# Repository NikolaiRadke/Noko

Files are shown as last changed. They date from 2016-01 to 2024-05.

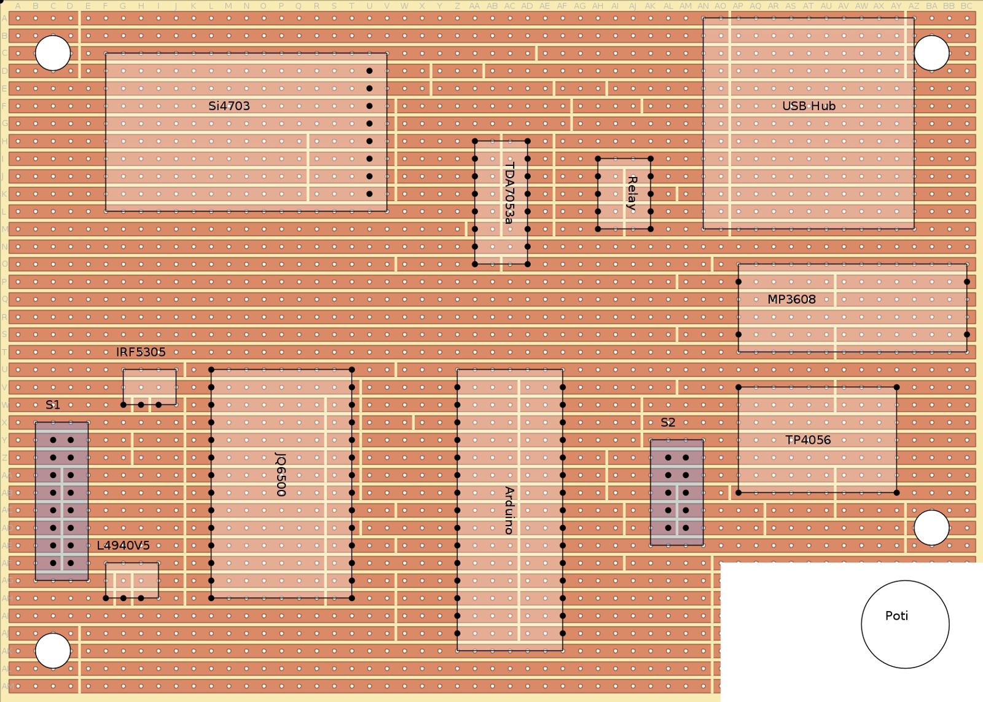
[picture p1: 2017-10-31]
schematics/Noko_layout_down.png

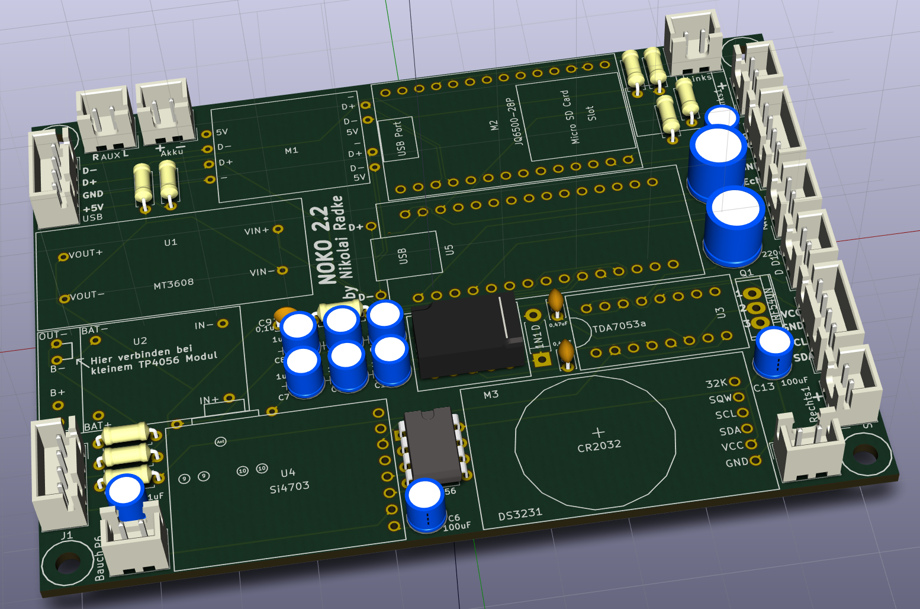
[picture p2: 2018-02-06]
Schematics/kicad/screenshots/NOKO PCB 3D 2018-02-01 20-50-33.png

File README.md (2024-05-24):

Noko
  
The DIY-**Noko Monster**, lovely and naughty, ready to build on your own. And everyone is invited to **contribute**. Noko is for everyone. What's new? See the [newsblog](https://github.com/NikolaiRadke/Noko/tree/master/NEWS.md).  
  
Noko Orange  

Noko is a multifunctional monster with an ATmega328  microcontroller on an **Arduino Nano**, display, clock, radio, mp3 player, four buttons as user interface, battery, voice set and  tons of gimmicks, packed in a cuddly monster suit - sturdy,
lovely and sometimes a bit mean and annoying. Just the way you want him to be. He, she or it - this is your decision     and only depends on the voice set. In this repository Noko is a lad, a real bloke! A buddy for life and a companion by day and night. All he needs is a little power every now and then.  

**Noko** stands for **No**ra and ni**ko**'s monster.

### Notes for non-German Noko makers
There are a German and an English version. Right now, the building wiki, the voice set, the manual and the optional EEPROM text files are in German. I'll try to translate the wiki and the manual one day. Until then, feel free to ask me for translation, if you need help. **Contribute!** I need an English voice set and English text files. In addition, any other language is welcome, Noko is to be cosmopolitan!

### Prerequisites
Noko needs Arduino IDE 1.6.6 - [1.8.2](https://www.arduino.cc/en/Main/Software) Copy the folder `Noko/V10/src/[language]/Noko/` into your sketch folder. When using 1.6.10 or newer with AVR core 1.6.12 or newer, everything will compile out-of-the-box. With 1.6.9 or lower, *Noko.ino* won't compile, the sketch size is too large. 

**Option 1:** Install newest  [IDE](https://www.arduino.cc/en/Main/Software) and relax.  
**Option 2:** If you are using IDE 1.6.9 or lower, you need to install [Optiboot](https://github.com/Optiboot/optiboot) onto your Nano.  
**Option 3:** Take one of the precompiled hex-files and follow the instructions in [how to compile](https://github.com/NikolaiRadke/Noko/tree/master/howto_compile).  

**In any case, Optiboot is strongly recommended.**

### Content

```
Noko/
├── howto_compile/
|   Manual how compile the sketches in your Arduino IDE and precompiled sketches.  
|   └── precompiled/
|       Precompiled hex-files and windows tools.
|       ├── Deutsch/
|       |   German Versions.
|       ├── English/
|       |   English Versions.
|       ├── Flashtool/
|       |   Linux firmware flasher.
|       └── avrdude_win/
|           Avrdude files for windows.
|
├── manual/
|   Noko manual in PDF format and a template for a packaging design.
|   └── scribus/
|       Source documents for Scribus with all illustrations and fonts.
|
├── mp3/
|   Female and male voice sets for Noko in German. English needed? Contribute!
|   ├── female/  
|   |   Female voice set for Nokos.
|   |   └── VoiceSet_226/
|   |       New voice files.
|   └── male/
|       Male voice sets
|       ├── alternative/
|       |   Some less rude voice files.
|       ├── VoiceSet_111/
|       |   Voice set for older Nokos.
|       └── VoiceSet_226/
|           Enhanced voice set.
| 
├── schematics/
|   The Schematics for the Noko parts, the Noko sewing pattern and shopping lists.
|   └── geda/
|       Source documents for gEDA.
|
├── src/
|   Arduino sketches.
|   ├── deutsch/
|   |   German version
|   |   └── Noko/
|   |       Main sourcecode with all the required libraries.
|   ├── english/
|   |   English version. 
|   |   └── Noko/
|   |       Same files but translated. 
|   └── tools/
|       Tools for using components and diagnostic.    
|       ├── I2C-Scanner/
|       |   Sketch to scan adresses of all connected I2C-devices.
|       ├── Noko_Diagnostics/
|       |   Tool to test Noko functions via serial monitor.
|       ├── Noko_Disk1/
|       |   Sketch to write the Disk1 textfile into 24LC256-EEPROMs.
|       ├── Noko_EEPROM_Disk0/
|       |   Sketch to write Noko presets into the Arduino EEPROM and the Disk0 textfile into the
|       |   AH24C32 EEPROM.
|       └── Noko_Time/
|           Simple tool to set the current time without touching the EEPROM
└── write_EEPROM/
    Tools to write data through serial connection to the Arduino and the EEPROMs. 
```
### Let's get started!

Interested in Noko? Great! Let's start here: [German wiki](https://github.com/NikolaiRadke/Noko/wiki).  
English wiki will follow. One day...

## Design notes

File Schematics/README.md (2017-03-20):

# Schematics

### Technical schematics
* **NOKO.png**:
NOKO's main schematic.
* **NOKO_Amp.png**:
Amplifier with TDA7053a and ADC-schematic for the buttons.
* **NOKO_USB.png**:
Power source and USB hub.

These schematics have been written with [gEDA](http://www.geda-project.org/). You can find the source files in folder [geda/](https://github.com/NikolaiRadke/NOKO/tree/master/schematics/geda).

### Other manuals

* **NOKO_Pattern.pdf**:
NOKOs sewing pattern. 
* **NOKO_Einkaufsliste.pdf**:
Shopping list in German  

### Construction plans, used in the wiki
* **NOKO_inside.png**:  
Foto of NOKOs inside life  
* **NOKO_layout_down.png**:  
Mainboard layout downside  
* **NOKO_layout_s1.png**:  
S1 plug description German  
* **NOKO_layout_s2.png**:  
S2 plug description German  
* **NOKO_layout_small.png**:  
Upper board layout downside  
* **NOKO_layout_small_2.png**:  
Upper board connections upside  
* **NOKO_layout_up.png**:  
Mainboard layout upside  
* **NOKO_layout_up_amp.png**:  
Mainboad layout for amplifier and connections upside
* **NOKO_layout_up_data.png**:  
Mainboard layout for data connections upside  
* **NOKO_layout_up_power.png**:  
Mainboard layout for power connections upside  
* **NOKO_raw.png**:  
Mainboard downside

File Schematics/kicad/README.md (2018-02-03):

Achtung! Bitte die Gerber Dateien noch nicht benutzen! Es müssen noch Fehler beseitigt werden.

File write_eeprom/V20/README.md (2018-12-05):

# Setting up a serial connection and writing to EEPROMs

Open the NOKO writer sketch **write_eeprom.ino** in the Arduino IDE and start it. You can see the progress on your console.  

## Linux

1. Open a terminal  

2. To communicate through the connection, the user must be a member of the group **Dialout**. This can easily be done once-for-all with this command:  
``` sudo usermod -aG dialout $(whoami) ```  

3. Set parameter of serial communication with  
``` stty -F /dev/ttyUSB0 cs8 9600 ignbrk -brkint -imaxbel -opost -onlcr -isig -icanon -iexten -echo -echoe -echok -echoctl -echoke noflsh -ixon -crtscts ```  
if another USB port is used by NOKO, modify /dev/USB0 to /dev/USB1 or whatever the IDE tells you.

4. Change the directoy to ` NOKO/write_eeprom/ `

5. Write the text file to EEPROM with the command  
``` ./write_eeprom > /dev/ttyUSB0 ```  
or, if you want to see the progress in your console,    
``` ./write_eeprom | tee /dev/ttyUSB0 ```  
The program sends the content of the text file **EEPROM** via Arduino to the EEPROM. You can watch your Arduino's RX and TX LEDs blinking furiously. This may take a while, the file needs about 18 minutes to be written... *yawn*

### NOTE 
*write_eeprom* was compiled with *x86_64*. For other platforms, see *write_eeprom.c* comments to compile it for yourself.

## Windows

1. Open a command line. Click on *Start* and type ``` cmd ```.  

2. Chance the directoy to ` NOKO/write_eeprom/  `  

3. Write the text file to EEPROM with the command  ``` write_eeprom > COM1 ```  
If another USB port is used by NOKO, modify COM1 to COM2 or whatever the IDE tells you. The program sends the content of the text file **EEPROM** via Arduino to the EEPROM. You can watch your Arduino's RX and TX LEDs blinking furiously. This may take a while, the file needs about 18 minutes to be written... *yawn*

## Windows 8  

Users report troubles writing an EEPROM with the provided tools. Please try another platform.  

## Windows 10

Like written above, but first Windows 10 needs another **baud rate**. You need admin rights.  
 
or **Line 17** in **write_eeprom.ino**.  
  
2. *Right click Start* -> *Device Manager* -> *Ports* -> *USB Serial Port (COMX)* -> *Right click Port Settings*  

3. Set *Bits per second* to **115200**.

4. Take steps above.  

### NOTE 
*write_eeprom.exe* was compiled with *x86_64*. For other platforms, see *write_eeprom.c* comments to compile it for yourself.

## The textfile EEPROM

### EEPROM format
* **0000-3999** are for the swearword generator:  
*German version*  
**0000-0999** 10 chars for an adjective. If it's male, the funtions adds an "r" and a space.  
**1000-1999** 10 chars for the first part of the noun.  
**2000-2999** 10 chars for male noun.  
**3000-3999** 10 chars for female noun.  
*English version*  
**0000-0999** 10 chars for an adjective. The function adds a space.  
**1000-1999** 10 chars for the first part of the noun. The function adds a space.  
**2000-3999** 10 chars for noun.  

* **4000-9999** are for the phrases:  
Every phrase starts with *Wusstest Du, dass...* in German and *Did you know that...* in English. So each item has **3x20** characters.

* **10000-17999** are for the quotations:    
Just **4x20** chars. NOKO pretends to be sophisticated.

* **18000-20079** are for the poems:   
Again **4x20**. Try to be lyrical.

* **20080-XXX** 20 chars for author's name and 20 chars for the story title

if you want to write less items, just change the starting adresses in *NOKO.ino*.

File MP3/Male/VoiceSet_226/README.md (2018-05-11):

# Male voice set for NOKO - German | enhanced 226 files Version

Copy these mp3s into the folder **001** on your microSD card. Strictly observe the sequence!
021.mp3 must be copied as the 21st file. See the [Wiki](https://github.com/NikolaiRadke/NOKO/wiki/SDKarte) for more detailed instructions.

| Number  | Assignment |
| ---|---:|
| 001-010 | Free NOKIA alarm tunes |
| 011-050 | Response to belly button |
| 051-100 | Response to nose button  |
| 101-150 | Response to ultrasonic |
| 151-225 | Time based events |
| 226 | Birthday song |

011-225 have been spoken by my fellow actor [Carsten Caniglia](https://filmmakers.de/carsten-caniglia). Why? 
He has done a great job - moreover I don't want to listen to my own voice every day, especially when development takes more than a year! (Ian said I sound really weird in real life. Thanks, mate.)

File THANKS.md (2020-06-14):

# Thanks

These people helped me bringing life to Noko:  
  
- **Hans Radke** - (my dad) hardware construction and a lot of soldering.
- **Nora Linder** - creating and sewing the monster suit and spellchecking.
- **Carsten Caniglia** - the voice of Noko. Look at his [Homepage](https://filmmakers.de/carsten-caniglia).  
- **Norma Anthes** - the new female voice of Noko. Look at her [Homepage](http://norma-anthes.de/Norma_Anthes/).  
- **Ian Berell** - some english translations and spelling. Look at his [bike locks](https://twitter.com/sphykeian) and his new Hexlox [Kickstarter campain](https://www.kickstarter.com/projects/hexlox/hexlox-anti-theft-for-saddles-wheels-and-more-made). 
- **Helga Hansen** - The great article in the german Make-Magazin.

Active supporters:  
  
- **Hein-Peter Mahlzahn** - lots of corrections in the Wiki and GitHub.
- **David Feindel** - corrections.  
- **Reinhard Hund** - corrections.  
- **Ronny Roscher** - he found an annoying hardware bug.  
- **Thomas "Crayfish68"** - schemtics corrections, the (wheeee!) pcb and a LOT of beta testing.   
- **Yannik "ylth94"** - for the first pcb and supporting Thomas with the pcb design.  
- **Tim "Wetimer"** - for supporting Thomas with the pcb design.  
- **"jlegen"** - for supporting Thomas with the pcb design.  
- **Thomas "teuler"** - for supporting Thomas with the pcb design.  
- **Ralf Warmuth** - corrections.  
- **BigAngelina** - ideas,testing and the (horray!) 3D casing.  
- **Issue-Community** - ideas, inspirations and (alas!) bugs.  

Used ressources:  

- **Arduino board and IDE** - [www.arduino.cc](http://www.arduino.cc)  
- **Display library** - [Marco Schwartz](https://github.com/marcoschwartz/LiquidCrystal_I2C)  
- **Old display library** - [Francisco Malpartida](https://bitbucket.org/fmalpartida/new-liquidcrystal/wiki/Home)  
- **RTC library** - [Wagner Sartori Junior](https://github.com/trunet/DS3231RTC)   
- **JQ6500 library** - [James Sleeman](https://github.com/sleemanj/JQ6500_Serial)  
- **Si4703 library** - [Gary Bell](https://github.com/whiteneon/Si4703_FMRadio)     
- **TimerFreeTone library** - [Tim Eckel](https://bitbucket.org/teckel12/arduino-timer-free-tone/wiki/Home)  
- **Time library** - [Michael Margolis](https://github.com/michaelmargolis/arduino_time/tree/master/Time)  
- **Clock font** - [Ishan Karve](http://karve.in/?p=59)  
- **Suit inspiration - Ninni** - [RevoluzZa Blog](http://blog.revoluzzza.com/2009/02/25/tutorial-hopw-to-sew-a-revoluzzzionary-monster-wie-man-ein-revoluzzzionares-monster-naht/)

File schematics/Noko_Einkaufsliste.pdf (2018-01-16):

+/,#5(3-+34'
Technik
1 Arduino Nano
1 Serielles (I2C) LC-Display, 20x04 Zeilen
1 Echtzeituhr DS3231 mit EEPROM AT24C32 1 MP3-Modul JQ6500-28p
1 Ultraschallsensor HC-SR04
1 Akku 1800mAh, 81x50x4mm
1 Lademodul TP4056
1 Step Up-Modul, MP3608, 2A
1 USB-Hub, klein, mit kabelgebundenen Ports 1 microSD-Karte, min. 2GB
2 Lautsprecher 8Ohm, rechteckig, 20x40mm
1 (Optional) Radio Si4703
1 (Optional) EEPROM 24LC256
2 Lochstreifenplatinen 160x100mm, 2,54mm Rastermaß
1 Hartpapierplatine ohne Kupferauflage, ca. 100x50mm
2 Micro-USB-Kabel mit Winkel rechts
1 USB Buchse, isoliert mit Anschlusskabel (eventuell vom USB-Slotblech) 1 3,5mm AUX-Klinkenbuchse, isoliert mit Anschlusskabel
4 Taster, flach und breit
1 LED - oder 3 Taster und eine Taster-LED für die Nase (empfohlen)
1 R 330 (LED-Vorwiderstand)
1 L4940V5 Spannungsregulator
1 TDA7053a DIP (kein Sockel!)
1 MOSFET IRF5305
1 Printrelais ST3 001 H5W
1 Poti 470k logarithmisch mit Schalter 1 Potiknopf
2 Elko 220µ
5 Elko 100µ
7 Elko 1µ
3 C0,47µ
2 C 0,1µ
1 R 100k
2 R 10k
1 R 4,7k
1 R 2,7k
3 R 2,2k
2 R 1k
1 Flachbandkabel,16-polig, ca. 0,5m 1 Flachbandkabel, 10-polig, ca. 0,5m 2 Stiftbuchsen mit Stecker, 16-polig 1 Stiftbuchse mit Stecker, 10-polig 1 Kabel mit Abschirmung, ca. 0,5m

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

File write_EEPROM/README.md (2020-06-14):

# Setting up a serial connection and writing to EEPROMs

Open the NOKO writer sketch **NOKO_EEPROM_Disk0.ino** or **NOKO_Disk1.ino** in the Arduino IDE and start it. 
Wait for *10 seconds*. When running *NOKO_Disk1.ino* you can go on immediately.

## Linux

1. Open a terminal  

2. To communicate through the connection, the user must be a member of the group **Dialout**. This can easily be done once-for-all with this command:  
``` sudo usermod -aG dialout $(whoami) ```  

3. Set parameter of serial communication with  
``` stty -F /dev/ttyUSB0 cs8 9600 ignbrk -brkint -imaxbel -opost -onlcr -isig -icanon -iexten -echo -echoe -echok -echoctl -echoke noflsh -ixon -crtscts ```  
if another USB port is used by NOKO, modify /dev/USB0 to /dev/USB1 or whatever the IDE tells you.

4. Change the directoy to ` NOKO/write_eeprom/ `

5. Write the text file to EEPROM with the command  
``` ./write_Disk0 > /dev/ttyUSB0 ```  
or   
``` ./write_Disk1 > /dev/ttyUSB0 ```  
or, if you want to see the progress in your console  
``` ./write_Disk1 | tee /dev/ttyUSB0 ```  
The program sends the content of the text file **Disk0** or **Disk1** via Arduino to the EEPROM. You can watch your Arduino's RX and TX LEDs blinking furiously. This may take a while, Disk1 needs about 20 minutes... *yawn*

### NOTE 
*write_DiskX* was compiled with *x86_64*. For other platforms, see *write_DiskX.c* comments to compile it for yourself.

## Windows

1. Open a command line. Click on *Start* and type ``` cmd ```.  

2. Chance the directoy to ` NOKO/write_eeprom/  `  

3. Write the text file to EEPROM with the command  
``` write_Disk0 > COM1 ```  
or  
``` write_Disk1 > COM1 ```  
If another USB port is used by NOKO, modify COM1 to COM2 or whatever the IDE tells you. The program sends the content of the text file **Disk0** or **Disk1** via Arduino to the EEPROM. You can watch your Arduino's RX and TX LEDs blinking furiously. This may take a while, Disk1 needs about 20 minutes... *yawn*

## Windows 8  

Users report troubles writing an EEPROM with the provided tools. Please try another platform.  

## Windows 10

Like written above, but first Windows 10 needs another **baud rate**. You need admin rights.  

1. Uncommend **Line 65** in sketch **NOKO_EEPROM_Disk0.ino**  
or **Line 17** in **NOKO_Disk1.ino**.  
  
2. *Right click Start* -> *Device Manager* -> *Ports* -> *USB Serial Port (COMX)* -> *Right click Port Settings*  

3. Set *Bits per second* to **115200**.

4. Take steps above.  

### NOTE 
*write_DiskX.exe* was compiled with *x86_64*. For other platforms, see *write_DiskX.c* comments to compile it for yourself.

## The textfiles Disk0 and Disk1

### Disk0 format
The Disk0 file contains the author and title of the stories. Every item has exactly **2x20** characters, including unused spaces. The next item follows immediately. Do not use the return key, the file is like a single long string. It has to be plain text, don't use a word processor, just a simple text editor. **Note:** NOKO counts from zero, maybe your editor starts with 1 - change nothing. Just type. The number of stories ist limited to **95**, the AT24C32 is limited to measy 4096 bytes. In this repository, there are 40 german stories. If you want more or less, modifiy in *NOKO_EEPROM_Disk0* **max_stories** in line  
``` #define max_stories 40 // Max 95 ```.  

### Disk1 format
Nearly the same as Disk0. No return key, just space bar. 
* **0000-3999** are for the swearword generator:  
*German version*  
**0000-0999** 10 chars for an adjective. If it's male, the funtions adds an "r" and a space.  
**1000-1999** 10 chars for the first part of the noun.  
**2000-2999** 10 chars for male noun.  
**3000-3999** 10 chars for female noun.  
*English version*  
**0000-0999** 10 chars for an adjective. The function adds a space.  
**1000-1999** 10 chars for the first part of the noun. The function adds a space.  
**2000-3999** 10 chars for noun.  

* **4000-9999** are for the phrases:  
Every phrase starts with *Wusstest Du, dass...* in German and *Did you know that...* in English. So each item has **3x20** characters.

* **10000-17999** are for the quotations:    
Just **4x20** chars. NOKO pretends to be sophisticated.

* **18000-20079** are for the poems:   
Again **4x20**. Try to be lyrical.

if you want to write less items, just change the starting adresses in *NOKO.ino*. Right now, the swearword generator needs 4000 chars, so the phrases always start at 4000. Change the adresses of the quotations and poems in line **95 and 96**.

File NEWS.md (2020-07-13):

# Newsblog
  
## 2020  

* **13.07.2020** Release **V1.0-130720**. The last for old Noko.   
* **12.07.2020** The rework is finishid.    
* **10.07.2020** Tested new IDE 1.8.13. Works good.  
* **10.06.2020** This repository gets a rework.  

## 2019
* **18.09.2019** New IDE 1.8.10 is out. Saves about 500 bytes - that's quite a lot!  
* **14.04.2019** Firmware **X.0-140418**. Fixed old and rare nightmode bug.  
* **13.04.2019** New IDE 1.8.9 is working.  

## 2018  
* **15.01.2018** New IDE 1.8.8 is working but still has AVR Core 1.6.23.  
* **20.11.2018** Small improvements for write_eeprom tool. Thanks to jlegen.  
* **19.11.2018** New IDE 1.8.7 tested. Works with new AVR Core 1.6.23. Finally.  
* **26.08.2018** See Noko and me at Wissensnacht Ruhr Gelsenkirchen: 28.08.2018.  
* **25.08.2018** New IDE 1.8.6 is out! Together with old AVR Core 1.6.18 code size is reduced by about 400 bytes!  
* **24.08.2018** See Noko and me at the Maker Faire Hannover: 15.09.2018-16.09.2018.  
* **14.05.2018** See Noko and me at the Maker Faire Berlin: 25.05.2018-28.05.2018, FEZ!  
* **11.05.2018** The female voice set ist finished.  
* **30.04.2018** Firmware **X.0-300418** Slightly optimized random generator.  
* **26.04.2018** Good news: The 3D printable casing is ready! Stay tuned for a new 2.0 repository!  
* **06.04.2018** Firmware **X.0-060418** When uploading files Noko should be quiet. The equalizer menu sets Noko in upload mode.  
* **04.04.2018** My hoster was offline for more than two weeks. I moved to a new one. The graphics in the GitHub are back now. What a waste of time...  
* **19.03.2018** German version V2.0 now has full Umlaute support.  
* **13.03.2018** The german manual got an update. All new functions are described now.  
* **07.03.2018** Firmware **X.0-070318** - Enhancement: You can select weekdays for the alarm. Very handy!  
* **02.03.2018** Firmware **X.0-020318** - Bugfix: No more compiling warnings. I sacrificed two precious bytes for your relief.  
* **01.03.2018** Testing firmware and tools to be released. The manual got an update too.  
* **28.02.2018** Firmware **1.0-280218**  
  PCB Nokos got the new update yesterday, today it's time for handmade Noko.  
  * Enhancement: Older Nokos got the equalizer, too.  
  * Removed: The obsolete quiet mode.  
* **27.02.2018** Firmware **2.0-270218**  
  Found some time today to do a little work at the player.
  * Enhancement: Added an equalizer menue fot the MP3 Module. See settings menue.  
  * Enhancement: Added two navigation buttons, +10 and -10 to the player for faster file browsing.  
  * Removed: The almost obsolete quiet mode is gone. The equalizier is now in his place. If you want Noko to be quiet, use the poti.  
  * Bugfix: Very small code cleanup.  
* **26.02.2018** Firmware **2.0-260218** - Bugfix: Fixed wrong story information adressing. Sorry, you need to flash again.   
* **24.02.2018** Firmware **2.0-240218** - There it is. Story informations are now stored in the not-optional-anmymore 24LC256.  
* **23.02.2018** Firmware **X.0-230218** - Enhancement: Noko shows the duration of a MP3 or a story by his own! Typing the times into noko_eeprom_disk0.ino is not needed anymore. In an upcoming firmware of V2.0 the story titles and authors will be written to 24LC256 to store more stories.  
* **09.02.2018** Firmware **X.0-080218** - Instead of NewTone library, which caused some troubles, Noko now uses TimerFreeTone library. Noko has his lost flash space back and tone generation works great.   
* **08.02.2018** Added Firmware **2.0-080218** - Bugfix: I encountered too much troubles with the tone generation on the PCB. Switched back from the beloved NewTone library to standard tone library. Now it is working fine, but takes 1500 Bytes more flash. Sight.  
* **07.02.2018** Added Firmware **1.0-070218** - Some tone code reworks.   
* **06.02.2018** Added Firmware **2.0-060218** and directory V20. These files are for PCB-Nokos. V1.0 in folder V10 will certainly get the same maintenance. No Noko will be left behind!  
* **04.02.2018** Finished testing the PCB. Nearly everything is working! There are some minor issues with the hub left.  
* **03.02.2018** The diagnostics tool got an update to V0.8. I needed more functions to test the new PCB.  
* **15.01.2018** Firmware **1.0-150118** - Enhancement: Story menu no shows length in hours and minutes.  
* **12.01.2018** Added a simple tool to set the current time without touching the EEPROM.  
* **08.01.2018** Finished the enhanced voice set. Firmware was updatet to **1.0-080118**. Have fun!  
  Warning: The new voice set ist preselected. If you want to use the old set, modify the comments in line **116** and **117**.  
* **01.01.2018** Happy new year! Stay tuned for the new Noko board and the enhanced voice set!  
  
## 2017
* **30.12.2017** Firmware **1.0-301217** - Enhancement/optional: Noko can read the busy signal reliable analog via A1  
* **18.12.2017** The gerber files are now online! Build your Noko in an easy way! Thanks to the community!  
* **30.11.2017** Firmware **1.0-301117** - Bugfix: The story addressing is now working correctly.  
NOTE: You need to reflash your AH24C32. Sorry. I'm a lousy coder.  
* **07.10.2017** Firmware **1.0-210917** - Enhancement: EEPROM lifecycle was improved mit EEPROM.update() instead of EEPROM.write(). I tried to fix more bugs but couldn't find any of them ;-). noko_eeprom_disk0 was also modified with this function. Noko_Diagnostics V0.5 now supports a library-free radio test.  
* **04.10.2017** IDE 1.8.5 is out. Still no compilier options. It seems to be AVR Core specific, maybe platform.txt is being ignored. Stay with 1.6.18 if you care about free flash.  
* **25.08.2017** IDE 1.8.4 with AVR Core 1.6.20 is out. Again, since AVR Core 1.6.19 compiler options aren't supported anymore. You can stay with 1.6.18. 
* **24.08.2017** Firmware **1.0-240817** - Bugfix: Now Noko supports 95 stories instead of 42.  
* **10.08.2017** Noko moved to Berlin!  
* **21.07.2017** ...and updated to V0.4. I have had some free time.  
* **20.07.2017** The Noko diagnostic tool was updated to V0.3.  
* **30.06.2017** **Release V1.0-300617**  
Second Noko release with new firmware 1.0-300617. I spend a lot of time looking for bugs. Since last firmware 1.0-240617, the belly button debounce was improved again, i also fred up some flash memory und did some small powersave improvents. This should be the last V1.0 release. Hopefully...  
* **24.06.2017** - Firmware **1.0-240617** - Belly button debounce improvement - it was about time! And some code optimizations. 100 Bytes freed! Wheee!  
* **19.06.2017** - Firmware **1.0-190617** - Bugfix: No time refresh when playing radio oder MP3s.  
* **09.06.2017** - Firmware **1.0-090617** - Another firmware update before the upcoming release with serval optimizations and a bugfix: The display won't turn off. 
* **07.06.2017** - New IDE 1.8.3 tested. Compiler options in platform.txt aren't working. Again. AVR Core 1.6.19 increases the sketch size by about 760 Bytes. IDE 1.8.3 with AVR Core 1.6.18 takes 17 Bytes more. Noko stays with AVR Core 1.6.18.  
* **04.06.2017** - Firmware **1.0-040617** - Code shrinking and - as the reason for a new firmware - a nasty bug got fixed in the distance light settings. A new release will follow soon.  
* **31.05.2017** - Added an early diagnostic tool for Noko to test functions through serial monitor.  
* **28.05.2017** - Added a TCL/TK Linux firmware flash tool. Should work with OSX, too. A Windows version will follow.  
* **21.05.2017** - Firmware **1.0-210517** - RDS rework. Works MUCH better now. Polling does not block navigation anymore. I am still working on some other improvements, expect a new release in June.    
* **17.05.2017** - **Release V1.0-170517**  
New optimized release. Install it! Noko will be glad. It is based on firmware 1.0-150517 with the following enhancements:  
  * Custom chars were taken from PROGMEM. That caused too much troubles.  
  * Cleaned up source code, completely in english, including constants, variables and function names.    
  * Autodetection for the display address. Very handy.  
  * Very small bugfixes.  
* **15.05.2017** - Small bugfixes. PROGMEM troubles custom character.  
* **14.05.2017** - The sourcecode is now in English. Renamed constans, functions and variables for better understanding.  
* **02.05.2017** - **Release V1.0-010517 - Buggy V1.0-190417 removed 29.05.2017**  
First release after initial 120516. Optimized and bugfixed 130417. Now there is enough flash free for future enhancements. Feel free to contact me for ideas, bugs and suggestions.  
* **27.04.2017** - Tested compiling options in platform.txt. They are working again with IDE 1.8.2. This saves about 800 bytes flash.  
* **19.04.2017** - Firmware **1.0-190417** - Fixed ADC bug after power safe mode.  
* **13.04.2017** - Well - it is **1.0-130417** now. Found a more flash-saving way.   
* **12.04.2017** - New firmware **1.0-120417** is out. After 11 month Noko gets some small enhancements:
  * Custom chars are now in PROGMEM  
  * Power saving when idle was improved.
  * The life cycle of the internal EEPROM was highly improved (several decades).
  * Small bugfixes and typos in the comments where removed.
* **24.03.2017** - New IDE 1.8.2 with AVR Core 1.6.18 works too.  
* **22.03.2017** - Noko was guest at CeBIT faire 2017: [https://www.youtube.com/watch?v=V2i4UrzMkM8#action=share]  
* **07.03.2017** - All four issues are now available as an ebook in all common stores and [heise shop](https://shop.heise.de/katalog/make-noko-das-mp3-monster?pk_campaign=dossnoko&pk_kwd=t1).  
* **22.02.2017** - The fourth und last issue of the Make Magazin arrived: [https://shop.heise.de/katalog/frankensteins-labor].  
* **13.01.2017** - New IDE 1.8.1 with AVR Core 1.6.17 works.  
* **12.01.2017** - Added Windows 10 support for burning the eeproms.  
* **05.01.2017** - **Hardware bug found**: The resistor at D2 moved to D3.  
  
## 2016
* **24.12.2016** - Merry Xmas. A good time to test new 1.8.0 IDE. Works.  
* **15.12.2016** - The third issue of the Make magazin is out: [https://shop.heise.de/katalog/make-06-2016].  
* **02.12.2016** - New IDE 1.6.13 is out. Works, but still no compiling options possible. (Deja Vu)  
* **12.11.2016** - The ST3 002 H5W relay is out of stock. Switched to FRT5 DC5V with a 1N4001 diode.  
* **02.11.2016** - Updated compiling options for newer (1.6.10+) and older (1.6.9-) IDEs.
* **13.10.2016** - The second issue of the Make magazin with the Noko article ist out. Get it now! Remember your friends... See [https://www.heise.de/make/inhalt/2016/5/68/] for more.  
* **28.09.2016** - New IDE 1.6.12 is out. Works, but still no compiling options possible. 
* **21.09.2016** - Added precompiled hex-files for those who have too much compiling troubles.  
* **28.08.2016** - New IDE 1.6.11 is out. Works, but new AVR Core 1.6.13 doesn't support compiling options anymore. Strange. Core 1.6.12 is still working great.    
* **12.08.2016** - Noko appears in the next four issues of the german Make magazin! See [https://www.heise.de/make/inhalt/2016/4/66/] for more.  
* **29.07.2016** - IDE 1.6.10 now has LTO, even Windows version! Optiboot and compiler options are not needed anymore, but still recommended.  
* **28.07.2016** - New IDE 1.6.10 is out. Works with Noko.ino. 
* **28.07.2016** - Reanimated the newsblog. For you and me and Noko.  
* **06.01.2016** - Joined GitHub

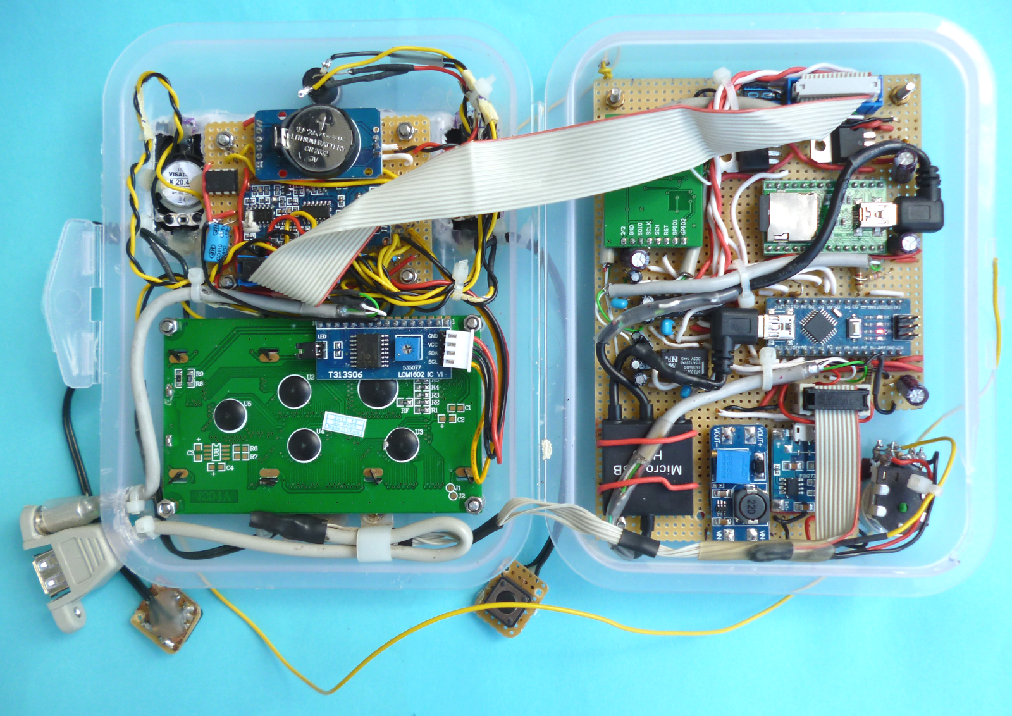
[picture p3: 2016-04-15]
schematics/Noko_inside.png

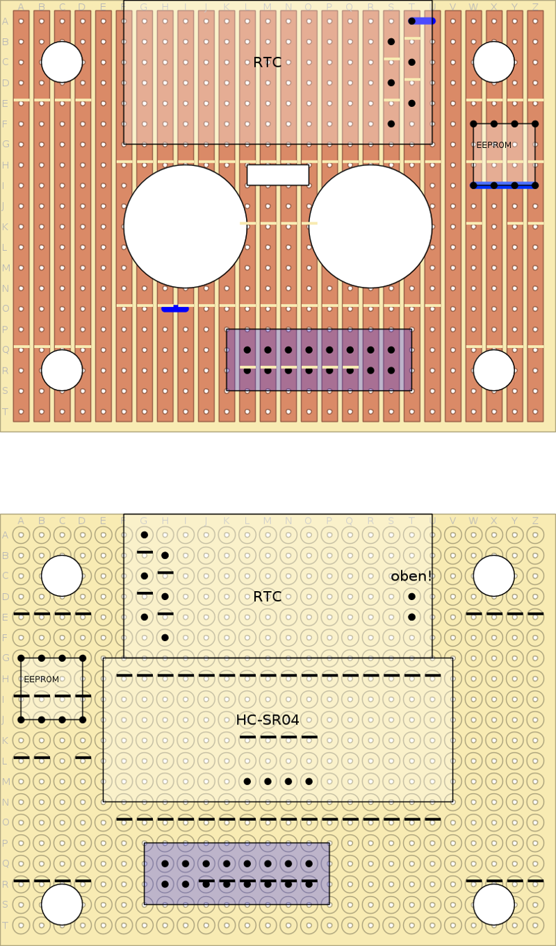
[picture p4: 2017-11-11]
schematics/Noko_layout_small.png

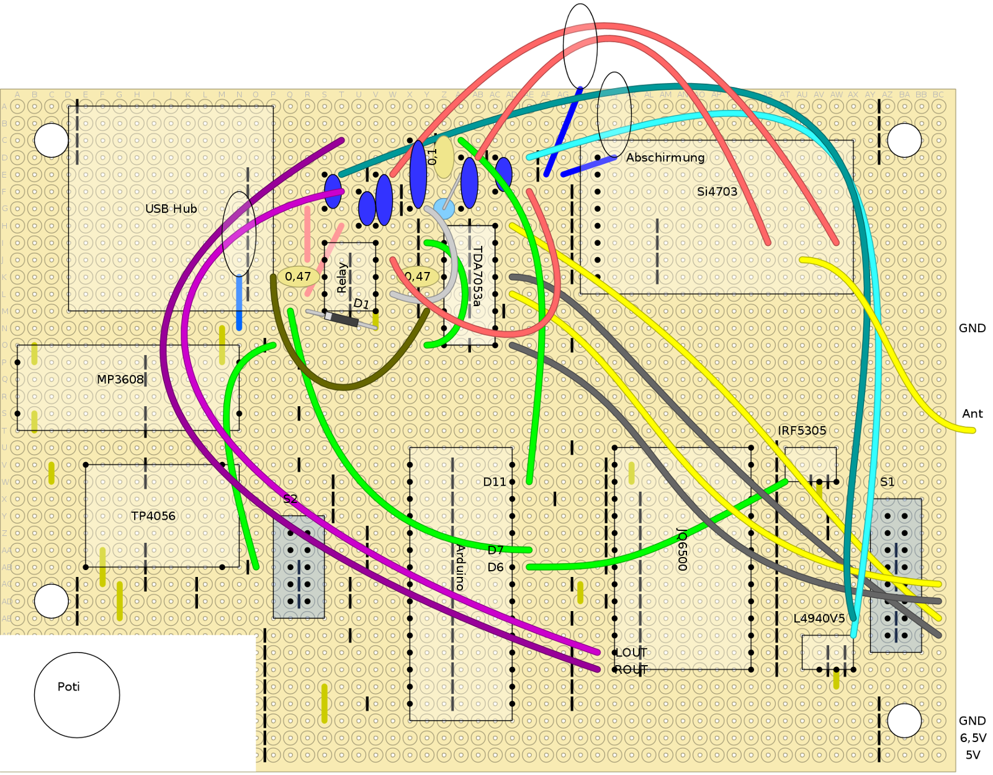
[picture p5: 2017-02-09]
schematics/Noko_layout_up_amp.png

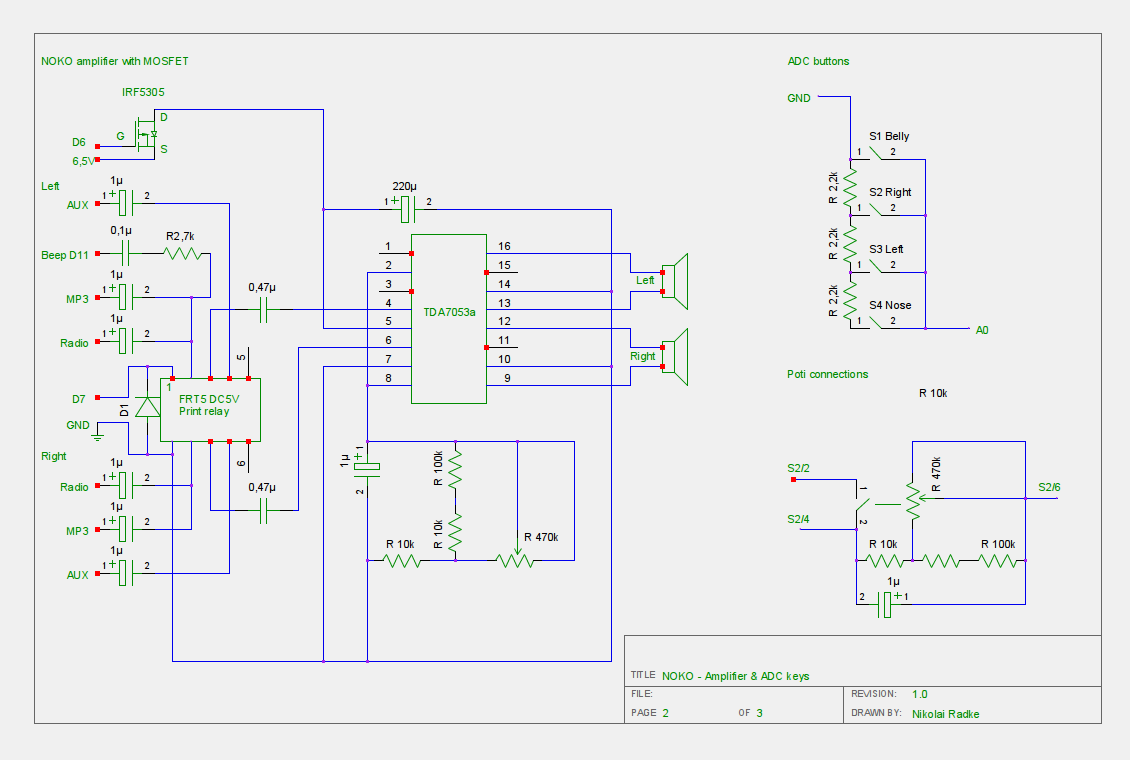
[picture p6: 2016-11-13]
schematics/Noko_Amp.png

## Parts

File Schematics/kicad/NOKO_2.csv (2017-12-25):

ID | Bezeichner | Gehäuse | Stückzahl | Bezeichnung | Anbieter und Ref.
1 | 1N1 | D_DO-41_SOD81_P7.62mm_Horizontal | 1 | D
2 | C1,C13,C14 | CP_Radial_D5.0mm_P2.50mm | 3 | 1uF
3 | C2,C3,C9,C15,C16 | CP_Radial_D5.0mm_P2.50mm | 5 | 100uF
4 | C4 | CP_Radial_Tantal_D4.5mm_P2.50mm | 1 | 0,1uF
5 | C5,C6 | CP_Radial_D8.0mm_P2.50mm | 2 | 220uF
6 | C7,C8 | CP_Radial_Tantal_D4.5mm_P2.50mm | 2 | 0,47uF
7 | C10,C11,C17,C18 | CP_Radial_D5.0mm_P2.00mm | 4 | 1uF
8 | C12 | CP_Radial_Tantal_D4.5mm_P2.50mm | 1 | 0,1u
9 | D1 | LED_D4.0mm | 1 | D
10 | P1 | JST_EH_B02B-EH-A_02x2.50mm_Straight | 1 | Battery
11 | P2 | JST_EH_B02B-EH-A_02x2.50mm_Straight | 1 | Switch_Poti
12 | P3 | JST_EH_B03B-EH-A_03x2.50mm_Straight | 1 | L4940V5
13 | P4 | JST_EH_B02B-EH-A_02x2.50mm_Straight | 1 | S4_Nose
14 | P5 | JST_EH_B02B-EH-A_02x2.50mm_Straight | 1 | S3_Left
15 | P6 | JST_EH_B02B-EH-A_02x2.50mm_Straight | 1 | S2_Right
16 | P7 | JST_EH_B02B-EH-A_02x2.50mm_Straight | 1 | S1_Belly
17 | P8 | JST_EH_B03B-EH-A_03x2.50mm_Straight | 1 | Poti
18 | P10 | JST_EH_B02B-EH-A_02x2.50mm_Straight | 1 | Speaker_Left
19 | P11 | JST_EH_B02B-EH-A_02x2.50mm_Straight | 1 | Speaker_Right
20 | P12 | JST_EH_B04B-EH-A_04x2.50mm_Straight | 1 | HC-SR04
21 | P13 | JST_EH_B04B-EH-A_04x2.50mm_Straight | 1 | Display
22 | P14 | JST_EH_B02B-EH-A_02x2.50mm_Straight | 1 | AUX
23 | Q1 | TO-220 | 1 | IRF540N
24 | R1,R2,R3 | R_Axial_DIN0207_L6.3mm_D2.5mm_P7.62mm_Horizontal | 3 | 2,2k
25 | R4,R6 | R_Axial_DIN0207_L6.3mm_D2.5mm_P7.62mm_Horizontal | 2 | 10k
26 | R5 | R_Axial_DIN0207_L6.3mm_D2.5mm_P7.62mm_Horizontal | 1 | 100k
27 | R7,R9 | R_Axial_DIN0207_L6.3mm_D2.5mm_P7.62mm_Horizontal | 2 | 1k
28 | R8 | R_Axial_DIN0207_L6.3mm_D2.5mm_P7.62mm_Horizontal | 1 | 300
29 | R10 | R_Axial_DIN0207_L6.3mm_D2.5mm_P7.62mm_Horizontal | 1 | 4,7k
30 | R11 | R_Axial_DIN0207_L6.3mm_D2.5mm_P7.62mm_Horizontal | 1 | 2,7k
31 | U3 | TDA7053a | 1 | TDA7053a
32 | U5 | Arduino_Nano | 1 | Arduino_Nano
33 | U7 | Printrelais_ST03 | 1 | FRT5_DC5V
34 | U8 | DIP-8_W7.62mm | 1 | 24LC256
35 | M3 | Micro-USB-Hub | 1 | Micro-USB-Hub
36 | P9 | JST_EH_B04B-EH-A_04x2.50mm_Straight | 1 | USB-Connector
37 | M2 | JQ6500-28P | 1 | JQ6500-28P
38 | U4 | Si4703 | 1 | Si4703
39 | M1 | DS3231 | 1 | DS3231
40 | U2 | TP4056 | 1 | TP4056
41 | U1 | MT3608 | 1 | MT3608

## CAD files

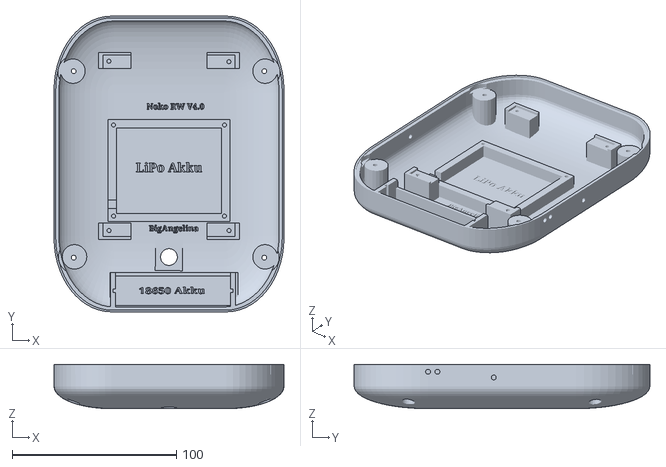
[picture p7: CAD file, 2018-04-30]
Schematics/gehaeuse/Rueckwand.stl
140.0 x 180.0 x 27.0

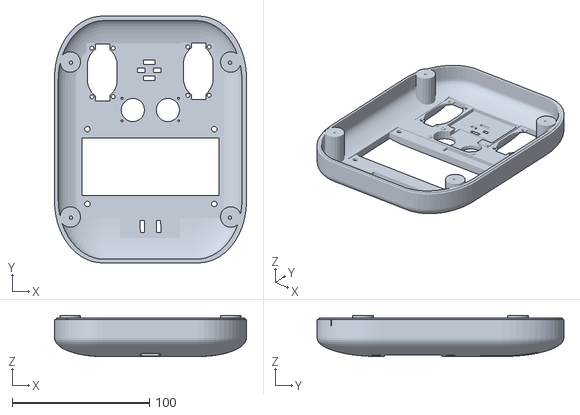
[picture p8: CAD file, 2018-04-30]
Schematics/gehaeuse/Gehaeuse_runde_LED_Schalter.stl
140.0 x 180.0 x 30.0

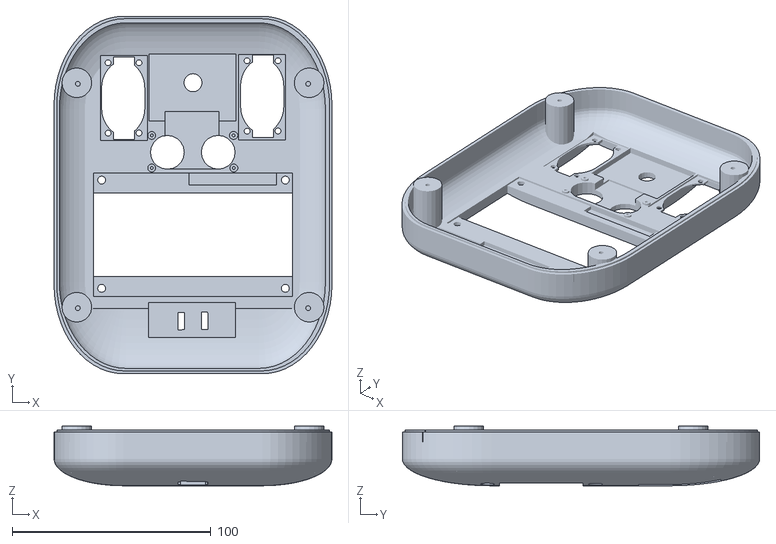
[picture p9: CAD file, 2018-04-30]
Schematics/gehaeuse/Gehaeuse_eckiger_LED_Schalter.stl
140.0 x 180.0 x 30.0

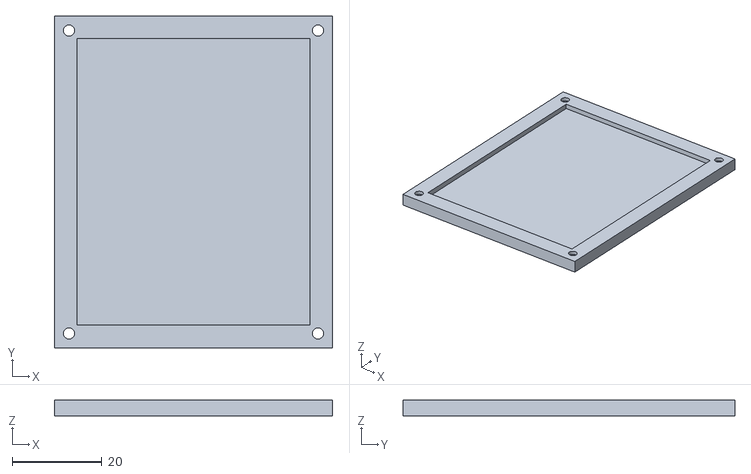
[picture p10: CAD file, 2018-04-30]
Schematics/gehaeuse/Akku_deckel.stl
62.0 x 74.0 x 3.50

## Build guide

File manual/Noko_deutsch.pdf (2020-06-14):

# Noko

# Anleitung

# Noko

# Inhalt

Einführung |
Noko zum Anfassen |
Das Display |
Die Menüs |
Hauptmenü |
Spiel was vor |
Radio hören |
Eigenes hören |
Geschichten hören |
Alarm stellen |
Uhrzeit stellen |
Nachtmodus |
Noko stellen |
weiter |
Noko und der Strom |
Display dimmen |
Nachtmodus |
Ausschalten |
Akku sparen |
Die Mischung macht's |
Fragen und Anworten |
Anhang |
Hinweise |

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
# Noko

# Einführung

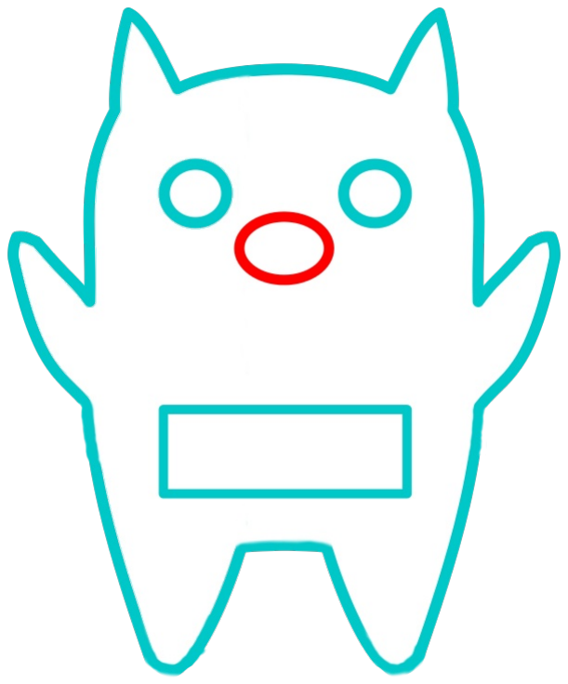
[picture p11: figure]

Noko ist zuhause. Von nun an wird alles anders. Er ist ein Kum‐ pane fürs Leben und ein Begleiter am Tag und in der Nacht. Al‐ les, was er braucht, ist ab und zu ein bisschen Strom. Noko soll unterhalten und nützlich sein, wird sich aber auch einmischen, denn sonst wird ihm schnell langweilig.

Noko steht für Noras und Nikos Monster und hat eine Vielzahl an Funktionen:

### Niedlich sein - Kumpel sein

Ja, das kann er wirklich gut. Er ist schließlich aus flauschigem Fleece mit einer kuscheligen Füllung genäht. Aber er kann noch mehr: Er bemerkt, wenn man sich ihm nähert, fordert ab und an Aufmerksamkeit, zeigt Gedichte auf seinem Display, ist schrecklich kitzelig am Bauch und mag es gar nicht, wenn man ihm auf die Nase drückt.

### Uhrzeitanzeige

Auf seinem Display zeigt Noko die Uhrzeit und das Datum an. Noko weiß, wie spät es ist, auch wenn er mal keinen Strom hat. Und sollte er sich irren: Man kann ihn natürlich stellen. Auch Zeitumstellungen kennt der kluge Noko. Aber er weiß auch, wann Schlafenszeit ist: Im Nachtmodus macht er artig von allei‐ ne das Display aus. Und mit einem Wisch auch mal kurz wieder an.

### Wecker

Noko verschläft nie und weckt artig mit Tönen, Klängen oder seinem Radio.

### Radio

Fremde Botschaften von der Erde oder aus dem All sind für No‐ ko kein Problem. Sofern es sich um UKW handelt. Stationstas‐ ten hat er auch und wenn der Empfang stimmt, zeigt er auch Sendernamen und Sendungsinformationen via RDS.

### Hörspiele und Musik

Langeweile? Noko kennt Hörspiele und kann viele Lieder in seinem Speicher ablegen, da ist für jeden etwas dabei. Es reicht jedenfalls für viele, viele Stunden. Und wird auch das langweilig: Mit Hilfe des AUX-Anschlusses gibt Noko auch ger-

# Noko

# Noko zum Anfassen

Noko hat neben seinem weichen Fell auch ein paar Dinge, um mit seinen Mitmenschen zu kommunizieren.

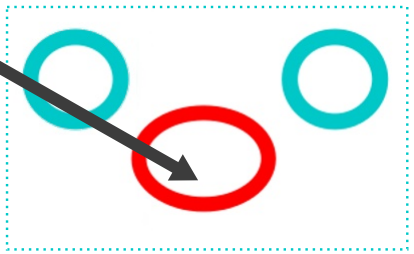
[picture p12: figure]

## Leuchtnase

Damit bietet Noko ein Licht in der dunklen Nacht. Die Helligkeit ist einstellbar. Licht aus geht natürlich auch. Noko hat keine Angst im Dunkeln.

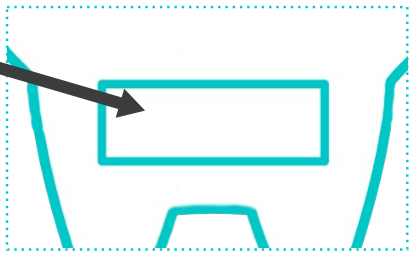
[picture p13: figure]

## Display

Nicht nur die Uhrzeit wird hier angezeigt, auch fast die gesamte Bedienung wird über dieses Display eingestellt. Ab und zu zeigt Noko auch hier ein Gedicht. Oder er macht damit Faxen. Ganz, wie es ihm gefällt.

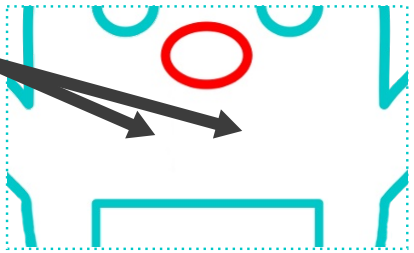
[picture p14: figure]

## Distanzsensor

Noko weiß, was um ihn herum geschieht. Wenn man sich ihm nähert, wird er sich äußern. Und in der Nacht macht er auf einen Wink hin das LIcht an. Wenn man will.

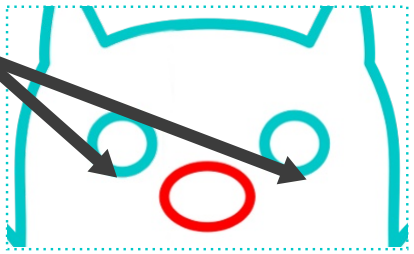
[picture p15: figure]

## Lautsprecher

Monster müssen Krach machen! Oder Geschichten erzählen. Das geht am besten mit zwei kräftigen Stereolautsprechern. Die sind etwas versteckt, vielleicht sind sie Noko peinlich. Nicht zu feste draufdrücken, ja?

## USB- und AUX-Anschluss

Hier kann Noko aufgeladen werden, zudem kann er dort eine neue Firmware bekommen, um ihm seine Fehlerchen auszutreiben und man kann neue MP3-Dateien aufspielen.
Mit dem AUX-Anschluss kann Noko wiedergeben, was auch
immer an eine 3,5mm-Klinke passt. Da kann kein

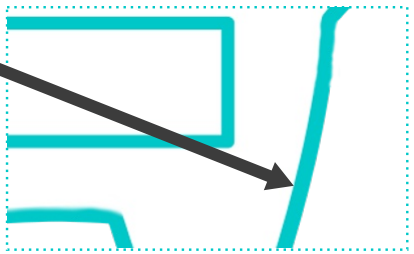
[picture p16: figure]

Handylautsprecher oder I-Pott mithalten! | 5

# Noko

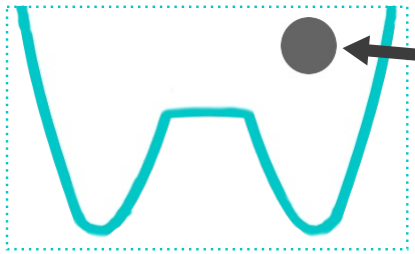
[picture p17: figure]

## Lautstärkeregeler

Auf Nokos Rückseite befindet sich die drehbare Lautstärkeregelung. Laut und leise. Man kann Noko hier auch ausschalten. Das wird er zwar nicht mögen, aber es geht. Einschalten geht hier natürlich auch.

## Nokos Tasten

Mithilfe von vier Tasten kann man Noko sagen, was er zu tun hat. Auf der Nase, auf dem Bauch, linke Hand und rechte Hand. Links und rechts gehen vom Betrachter aus.

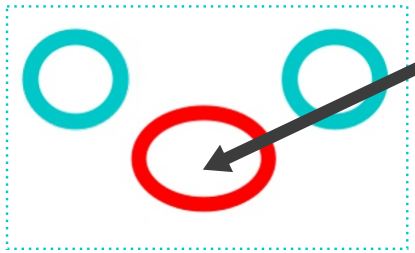
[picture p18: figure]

## Nasentaste

Mit einem Druck auf die Taste unter der LED kommt man sofort zurück zur Uhrenanzeige. Immer. Aber Noko wird leider nicht gern dort angefasst. Manchmal zeigt er das auch. Es ist schließlich seine Nase.

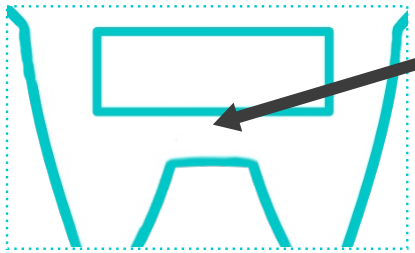
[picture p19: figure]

## Bauchtaste

Eine sehr wichtige Taste! Hiermit kommt man nämlich in das Hauptmenü. Zudem werden mit der Bauchtaste weitere Menüpunkte ausgewählt, Dinge angewählt und bestätigt. Sozusagen die Haupttaste. Wenn Noko nur am Bauch nicht so schrecklich kitzelig wäre...

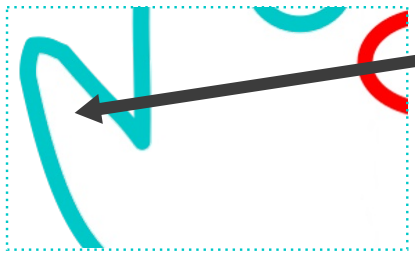
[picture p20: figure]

## Linke Hand

Mit Links wird die Displaybeleuchtung ausgeschaltet, aber auch im Menü die Menüpunkte ausgewählt. Nach links und nach oben. Das geht mit Links.

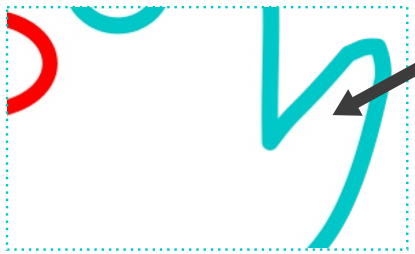
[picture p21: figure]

## Rechte Hand

Ist Noko mal zu lästig, wird der Distanzsensor mit einem Druck auf diese Taste ausgeschaltet. Im Menü geht man damit nach rechts und nach unten.

# Noko

# Das Display

Hier zeigt Noko also Datum und Uhrzeit an. Aber was bedeuten diese andere Zahl und diese Buchstaben?

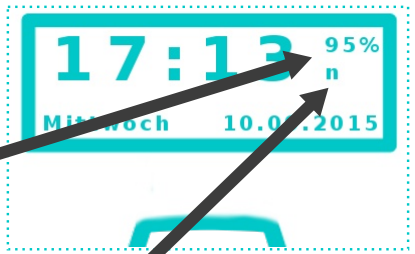
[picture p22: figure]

## Ladestand

Noko braucht Strom. Sein Akku hält etwa einen Tag, der Ladestand wird oben rechts als Zahl in Prozent angezeigt.

% | Der Akku entlädt.
+ | Der Akku wird geladen.

Fällt der Ladestand unter 10%, so blinkt die Anzeige und Noko beschwert sich jede Minute mit einem Piepton.

## Einstellungen

Anhand eines Buchstabens werden aktuelle Einstellungen dargestellt. Beim ersten Einschalten sollte hier ein n stehen.

n | Nachtmodus ist eingestellt.
N | Nachtmodus ist eingestellt und aktiv.
P | Noko spielt etwas vor
p | Pause, die Wiedergabe wird angehalten.
X | Distanzsensor ist deaktiviert.
D | Display ist gedimmt und geht von alleine aus.
Ω | (Omega) Der Alarm ist gestellt.
A | Der AUX-Eingang ist aktiviert.

Die einzelnen Einstellungsmöglichkeiten werden im nächten Abschnitt vorgestellt.

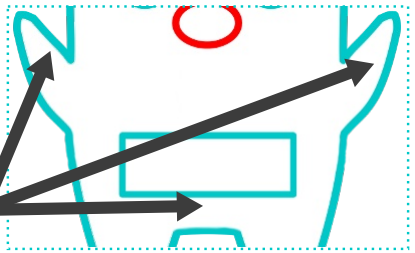
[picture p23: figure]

## Was kann man hier noch machen?

Drei Tasten können hier gedrückt werden. Nunja, eigentlich vier, aber die Nasentaste wird nicht gebraucht und Noko mag das nicht. Ausprobieren!

Bauchtaste | Hauptmenü
Linke Hand | Display dimmen bzw. ausschalten
Rechte Hand | Distanzsensor an/aus

## Nanu? Was passiert da auf dem Display?

Keine Uhrzeit zu sehen? Dafür aber ein Gedicht? Oder ein dummer Spruch? Oder komische Dinge? Das sind Events, mit

n N S P X D Ω A

# Noko

# Die Menüs

Die Bedienung des Noko erfolgt über die einzelnen Menüs, die nun vorgestellt werden. Auf das Hauptmenü folgen mehrere Untermenüs, die widerum Untermenüs haben können. Aber verwirrend ist das nicht. Noko kann das auch. Mit einem Druck auf die Bauchtaste zeigt er das Hauptmenü an. Wird das jeweilige Menü eine Minute nicht genutzt, kehrt Noko zur Uhrzeit zurück.

## Hauptmenü

Im Hauptmenü werden die Untermenüpunkte angezeigt. Der kleine Pfeil zeigt an, welches Element gerade ausgewählt ist. Mit der linken Hand wird der Pfeil hoch, mit der rechten Hand runter bewegt. Mit der Bauchtaste wird der Menüpunkt aufgerufen. Mit der Nasentaste wird das Hauptmenü verlassen (zum Ärger Nokos) und wieder die Uhrzeit angezeigt. Die vier Hauptmenüpunkte werden kurz vorgestellt und anschließend einzeln ausführlich beschrieben.

Spiel was vor
Unterhaltung pur! In diesem Untermenü zeigt Noko, was er zur Unterhaltung zu bieten hat. Das Radio kann hier bedient werden, Noko spielt Geschichten ab oder es wird etwas am AUX-Eingang über Nokos Lautsprecher ausgegeben.

Alarm stellen
Wann soll der Alarm klingeln? Soll er überhaupt klingeln? Wie soll er klingeln? Alles wird hier eingestellt.

Uhrzeit stellen
Noko zeigt die falsche Zeit an? Kein Problem, einfach neu stellen. Und ganz wichtig: Hier wird auch der Nachtmodus gestellt.

Noko stellen
Viele Einstellungen hier... viele. Helligkeit der LED, Häufigkeit der Events, Empfindlichkeit des Distanzsensors, Stromsparmodus, Distanzlicht und natürlich: Untermenü Mein Noko -um klar zu zeigen, wer Nokos einzig wahrer Kumpel ist.

> Spiel was vor
Alarm stellen
Uhrzeit stellen
NOKO stellen

# Noko

> Radio hören
Eigenes hören
AUX-Eingang
Geschichten hören

> Spiel was vor

## Spiel was vor

Ist eines der Geräte gerade aktiv, wird in diesem Menü vor dem jeweiligen Eintrag ein Notensymbol ♪ angezeigt.

Radio hören
Hier können das Radio eingeschaltet und verschiedene Sender auf Stationstasten verteilt werden.

* Eigenes hören
Noko eigene MP3s wiedergeben. Hier in diesem Untermenü. Sofern der Erbauer welche aufgespielt hat.

AUX-Eingang
Zum Hören eines externen Gerätes genügt ein Druck auf die Bauchtaste, woraufhin ein Notensymbol vor dem Menüpunkt erscheint. Sollten das Radio oder eine Geschichte laufen, so werden diese allerdings ausgeschaltet.

* Geschichten hören
Noko kann Hörspiele erzählen. Alles hier in diesem Untermenü. Sofern der Erbauer auch hier welche aufgespielt hat.

## Radio hören

Das Radio. Die nie versiegende Quelle der Unterhaltung. Die erste Zeile zeigt die Frequenz in MHz und, sofern der Empfang gut genug ist, den Sendernamen via RDS an. Das Radio ist, wenn es nicht in diesem Menü zuvor angeschaltet wurde, aus. Ist das Radio an und wird das Menü anhand der Nasentaste verlassen, läuft es weiter, bis es ausgeschaltet wird.

[«][»] Sendersuchlauf. Noko versucht, einen Sender zu finden. Dazu muss das Radio jedoch eingeschaltet sein.
[<][>] Manuelle Suche. Ändert die Frequenz um 0.1 MHz.
[►][■] Startet/Stoppt das Radio. Läuft gerade eine Geschichte oder ist der AUX-Eingang aktiv, so werden diese abgeschaltet.
[R] | Startet RDS-Text in Zeile zwei, sofern das
Radio | eingeschaltet | ist. | Bei | schlechtem
Empfang ist hier leider nichts zu sehen. Oder der Sender bietet keinen RDS-Text.
[1|s] Stationstasten. Bei 1, 2, 3 werden die Sender aufgerufen, bei s entsprechend gespeichert.

> Spiel was vor

> Radio hören

♪ 101.30 WDR4

[«][<][►][R][>][»]
[1|s][2|s][3|s]

# Noko

## * Eigenes hören

Sofern Noko mit MP3s gefüttert wurde, spielt er sie auch dienstbereit ab. In der zweiten Zeile zeigt Noko den Namen der Datei an. Allerdings nur die ersten acht Zeichen - zu mehr hat er einfach keine Lust. Oben zeigt Noko die aktuelle Nummer an, sowie die Anzahl aller MP3s, die er kennt.

[<][>] Titelauswahl. Läuft gerade ein MP3, so springt Noko zum nächsten/vorherigen.
[«][»] Zehn Titel vor oder zurück. Wie oben.
[►][■] | Startet/Stoppt das Abspielen. Läuft das Radio
| oder ist der AUX-Eingang aktiv, so werden
| diese abgeschaltet. Ist er am Ende angelangt,
| so spielt er automatisch den nächsten Titel.
[װ [ | Pause. Lieder und Geschichten können lang
| sein. Die Wiedergabe wird unterbrochen und
| kann zu einem anderen Zeitpunkt fortgesetzt
| werden. Neben der Uhrzeit wird P angezeigt.
| Die Pause hat aber Nachteile: Noko kann
| nicht Sprechen und verbraucht mehr Strom.

Wie kommen aber nun die MP3s auf den Noko? Das geht über die USB-Verbindung. Wie das genau funktioniert, wird im Anhang beschrieben.

## * Geschichten hören

Noko kennt einige Geschichten als MP3: Tatort-Krimis, Bestsellervertonungen und tolle Kurzgeschichten, sofern er damit ausgestattet wurde. Allesamt lizenzfrei. Die erste Zeile zeigt die Geschichtennummer und die Spieldauer an. Die zweite Zeile die Reihe bzw. Autor und die dritte Reihe den Titel.

Die Steuerung ist genauso, wie unter Eigenes hören. Allerdings hört Noko am Ende einer Geschichte auf. Vielleicht, weil dann ja Schlafenszeit ist.

## OK, was bedeutet nun dieser Stern?

Die Ausstattung kann variieren. Manche Nokos können etwas mehr, manche etwas weniger. Dieser Stern bedeutet also, dass die entsprechende Fähigkeit optional ist. Das betrifft Geschichten, Eigene MP3s und einige lustige Texte, Reime und Frechheiten, die er als Events auf dem Display von sich gibt. Aber keine Sorge: Im Großen und Ganzen bleibt Noko doch immer derselbe.

> Spiel was vor

> Geschichten hören

♪ 006/040 00:47:09
Tatort
Currykill
[«][<][װ][►][>][»]

> Spiel was vor

> Eigenes hören

♪ 001/045 00:03:4
NOKOLIED.MP3

[«][<][װ][►][>][»]

# Noko

> Alarm stellen

♪ 15:10 Uhr
> 15:10 | [aus]
Tage | [MDMDF | ]
Weckton | [Ton | ]

> Alarm stellen

> [X] Weckton
[ ] Radio
[ ] MP3

> Weckton +| [3]

## Alarm stellen

Gegen Müdigkeit oder fehlendes Erinnerungsvermögen hat Noko ein Rezept: Schrille Töne! Nun gut, wer mag kann sich auch sanft wecken lassen. In der ersten Zeile steht neben dem Glockensymbol die aktuell eingestellte Weckzeit. In der dritten Zeile kann nun die neue Weckzeit eingestellt werden. Mit den Handtasten wird zwischen 10er und 1er-Stellen gewechselt, mit der Bauchtaste die jeweilige Stelle um 1 erhöht. Noko passt dabei auf, dass keine unsinnigen Zeiten wie 25:61 entstehen.

[aus] | Hier wird der Wecker an- bzw. ausgestellt.
[MDMDFSS] Hier werden die Tage, an denen geweckt
| werden soll, ausgewählt.
[Ton] | Zur Auswahl der Weckerart kommt man von
| hier in ein weiteres Untermenü.

Drei Arten von Weckern stehen zur Auswahl: Von Noko generierte Töne, das Radio oder (lizenzfreie) Wecktöne im MP3-Format. Das X zeigt die aktuell ausgewählte Weckerart an. Wird Radio ausgewählt, erscheint das X an entsprechender Stelle. Bei Weckton und MP3 zeigt Noko ein neues Untermenü.

Angezeigt wird der aktuelle Weckton. Drückt man nun auf die Bauchtaste, wird der nächste Ton angezeigt und gespielt. Es gibt sechs Töne und zehn MP3. Mit der Nasentaste kehrt Noko zur Uhrzeit zurück.

## Uhrzeit stellen

Eigentlich ist Noko nicht vergesslich. Sollte aber seine Uhr mal falsch gehen, oder muss er weit in eine andere Zeitzone verreisen, so kann man die Uhr natürlich auch stellen. In der zweiten Zeile kann der Nachtmodus gestellt werden, der auch ein eigenes Untermenü hat. Uhrzeit und Datum werden wieder mit den Handtasten ausgewählt und mit der Bauchtaste verstellt. Auch hier passt Noko auf, dass alles seine Richtigkeit hat.

[an ] Hier gelangt man zum Nachtmodus-Menü.

Die Uhr wird nur gestellt, wenn auch etwas mit der Bauchtaste verändert wurde. Zur Uhranzeige kommt man mit der Nasentaste.

> Uhrzeit stellen

@ Neue Uhrzeit/Datum
> Nachtmodus [an ]
15:10 Uhr
10.09.2015

# Noko

## Nachtmodus

Manchmal ist Noko ganz schön redselig. Zum Glück gibt es den Nachtmodus! In einem angegebenen Zeitraum, voreingestellt ist 22:00 bis 09:00 Uhr, hält Noko sich vornehm zurück. In diesem Zeitraum

- löst der Distanzsensor keine Sprache aus.
- sagt Noko nichts, außer man drückt Tasten.
- wird ein Stromsparmodus aktiv.
- kann das Display automatisch dimmen.
[an] | Hier | wird | der | Nachtmodus | ein- | bzw.
ausgeschaltet. Ist der Nachtmodus an, so erscheint in der Uhzeitanzeige ein n.
[X] | Ist hier ein X gesetzt, so wird das Display
während der angewählten Zeit automatisch nach einer Minute ausgeschaltet.

In der dritten und vierten Zeile wird der Zeitraum des Nachtmodus von ... bis festgelegt. Das muss nicht zwingend über Nacht sein, auch von 09:00 bis 18:00 Uhr wäre möglich. Das wäre dann zwar ein Tagmodus, heißt aber dennoch weiterhin Nachtmodus, um Noko nicht unnötig zu verwirren. Ist der Zeitpunkt erreicht, wird aus dem n neben der Uhr ein N und der Nachtmodus verrichtet seinen Dienst.

Der Zeitraum wird, wie bei der Uhrzeit oder dem Alarm auch, wieder mit den Handtasten und der Bauchtaste gestellt. Die Nasentaste führt zurück zur Uhr.

Hinweis: Sollte Noko gerade damit beschäftigt sein, eine Geschichte abzuspielen, so läuft diese artig bis zum Ende, bevor er in seine wohlverdiente Nachtruhe geht. Bei Eigenen MP3s ist da schon Handarbeit gefragt.

Grundsätzlich ist der Nachtmodus eine gute Sache - er spart Strom und automatisiert Noko ungemein. Ausprobieren!

> Nachtmodus [an ]

> Uhrzeit stellen

@ Nachtmodus stellen
> [an ] Dimmen [X]
von 22:00 Uhr
bis 09:00 Uhr

# Noko

## Noko stellen

Mit Hilfe einiger Einstellungsmöglichkeiten kann man sich das Zusammenleben mit Noko so angenehm und auch rücksichtsvoll wie nötig oder möglich gestalten. Die ersten drei Einträge lassen sich wieder mithilfe der Bauchtaste verstellen.

LED
Ist das Display gedimmt oder aus, so wird automatisch die LED angeschaltet. Die Helligkeit wird mit 0 bis 9 bestimmt, wobei 0 ganz aus bedeutet.

Hinweis: Läuft das Radio, eine Geschichte, AUX oder sagt Noko gerade etwas, wird die LED zu dieser Zeit ausgeschaltet, um Störgeräusche zu vermeiden.

Events
Dieser Wert von 0 bis 9 bestimmt die Häufigkeit, mit der Noko Faxen macht, also etwas sagt oder auf seinem Display anzeigt. Bei 0 macht er nichts. Sitzt nur so da. Und bei 9? So ziemlich jede Minute. Bei 4 etwa alle halbe Stunde. Aber das bestimmt der Zufall. Im Nachtmodus macht Noko keine Events.

Hinweis: Events lassen sich mit einem Druck auf die Nasentaste unterbrechen, falls die eine Minute mal zu lang werden sollte. Dann zeigt Noko wieder die Uhrzeit.

Distanz
Die Empfindlichkeit des Distanzsensors wird auch hier mit 0 bis 9 bestimmt. Mit 0 wird er ausgeschaltet. Noko bemerkt nicht, wenn man ihn in die Hand nimmt, auch das Display wird nicht eingeschaltet, wenn es gedimmt wurde. Die anderen Werte von 1 bis 9 entsprechen dabei jeweils etwa 10 cm, bei 5 würde er also auf einen halben Meter reagieren.

Hinweis: Bei 0 wird auch in der Uhranzeige ein X angezeigt. Auch ein Druck auf die rechte Hand ändert nichts, die Empfindlichkeit muss hier erst wieder hochgestellt werden.

weiter...
Dieser Eintrag führt zu weiteren Einstellungen. Ausprobieren. Nur Mut.

> NOKO stellen

> LED | +| [0]
Events | +| [4]
Distanz +| [5]
weiter...

# Noko

weiter...
Hier sind weitere praktische Einstellungsmöglichkeiten. Die Elemente können mit der Bauchtaste angewählt werden, an der entsprechenden Stelle erscheint ein X.

Akku sparen
Ist Noko nicht am Ladegerät und wird das Display automatisch oder manuell gedimmt, so wird ein stärkerer Stromsparmodus aktiv, bei dem u.a. das Display ganz ausgeschaltet wird.

Hinweis: Die Stromsparmechanismen werden im nächsten Kapitel behandelt.

Distanzlicht
Ist das Display gedimmt, so kann es mit einem Wink vor Nokos Distanzsensor wieder beleuchtet werden, um z.B. nachts die Uhrzeit ablesen zu können. Anschließend wird es nach kurzer Zeit wieder gedimmt. Ist der Distanzsensor auf 0 gestellt oder durch Drücken der rechten Hand deaktiviert, so steht in der Uhranzeige ein X und das Distanzlicht funktioniert nicht.

Equalizer & Upload
Hier gelangt der Musikkenner in ein Untermenü, in dem verschiedene Equalizervoreinstellungen vorgenommen werden können: Normal, Rock, Pop, Jazz, Klassik und Bass. Wenn Noko mit neuen MP3s bespielt werden soll, ist dieser Menüpunkt ebenfalls zu wählen. Noko hält dann artig und Geduldig die Klappe.

Mein Noko
Ein sehr wichtiger Menüpunkt. Hier wird Nokos Kumpel, sein Bezugspunkt oder auch, was er allerdings weniger mag, sein Besitzer samt Email angezeigt. Das ist sogar so wichtig, dass Noko nicht von alleine zur Uhrzeit zurückkehrt! Nach Drücken einer beliebigen Taste werden noch die Firmwareversion und der Hersteller angezeigt. Nach einem Druck auf die Nasentaste ist der Spuk aber vorbei und Noko zeigt wieder die Uhrzeit an.

> NOKO stellen

> Akku sparen | [ ]
Distanzlicht | [ ]
Equalizer & Upload
Mein NOKO

@ Dieser NOKO gehört
Uwe Testperson
Uwesmail@
uwesprovider.de

> NOKO stellen

> weiter...

> weiter...

> Mein NOKO

# Noko

# Noko und der Strom

Auch Monster haben Hunger. Noko mag zwar Bier und Kekse, zum Funktionieren braucht er aber Strom. Meistens ist am USB-Anschluss das Netzteil angeschlossen. Wenn nicht, so muss Noko auf seinen Akku zurückgreifen. Der hält im Normalzustand locker über einen halben Tag, bevor er geladen werden muss. Wem das nun nicht reicht, der kann auf folgende Stromsparfunktionen zurückgreifen.

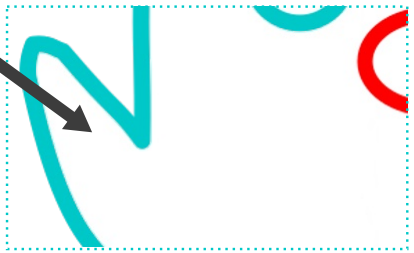
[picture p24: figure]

## Display dimmen

Zeigt Noko die Uhrzeit, so kann mit einem Druck auf die linke Hand die Displaybeleuchtung ausgeschaltet werden. Das spart natürlich Strom. Wurde vorher unter Noko stellen > weiter... > Distanzlicht ein X gesetzt, so kann das Licht mit einem Wisch vor dem Distanzsensor wieder für eine kurze Zeit eingeschaltet werden.

## Nachtmodus

Mehr Strom kann Noko im Nachtmodus sparen. In Zeiten, in denen man ihn wirklich nicht braucht oder er stören könnte, wie z.B. nachts, muss er auch nichts sagen. Ist der Modus aktiv, was im Display mit einem N angezeigt wird, wird das MP3-Modul weniger verwendet, was natürlich Strom spart.

Zusätzlich kann Uhr stellen > Nachtmodus > Dimmen angewählt werden. So wird im Nachtmodus das Display automatisch gedimmt. Ist die eingestellte Zeit vorüber und der Nachtmodus nicht mehr aktiv, bleibt das Display allerdings aus. Mit einem Druck auf die linke Hand ist Noko aber wieder voll da. Zumindest, bis es wieder Zeit für den Nachtmodus ist.

## Ausschalten

Das ist natürlich eine sehr stromsparende Maßnahme. Einfach am Lautstärkeregeler ausschalten. Dadurch wird Noko so espritvoll wie ein Stein, was ja nicht ganz Sinn der Sache ist, beispielsweise im Kino oder in der Oper aber angemessen wäre. Allerdings entläd sich so zwangsläufig die Pufferbatterie der Uhr. Sollte er nach zehn Jahren nicht wieder eingeschaltet werden, ist sie alle... .

# Noko

## Akku sparen

Unter Noko stellen > weiter... > Akku sparen findet man eine weitere Energiesparoption. Diese wird nur aktiv, wenn Noko auf seinen Akku zugreift, also nicht am Ladegerät via USB-Buchse angeschlossen ist. Ist dort ein X gesetzt, so wird das Display nicht nur gedimmt, wie oben beschrieben, sondern ganz abgeschaltet. Ebenso werden, wie im Nachtmodus, das MP3-Modul abgeschaltet und noch weitere Einsparungen vorgenommen. Ist der Modus gesetzt, das Display gedimmt und wird das Stromkabel gezogen, wird dieser Modus ebenfalls aktiv.

Nokos Alarm funktioniert natürlich weiterhin, ebenso beschwert er sich, wenn an seiner Nasentaste hantiert wird. Das Distanzlicht jedoch funktioniert hier nicht, ebenso muss das Display erst wieder mit der linken Hand eingeschaltet werden, bevor man ins Menü gelangt. Allerdings braucht Noko dafür etwas Zeit, auch hier ist etwas Geduld gefragt.

Auf diese Weise spart Noko wirklich sehr viel Strom, weit mehr als 24 Stunden sind so möglich.

## Die Mischung macht's

Ist Noko am Ladekabel angeschlossen, so sind Stromsparfunktionen natürlich nicht notwendig. Abgesehen vielleicht vom Nachtmodus, damit auch der feine Herr Noko freundlicherweise die Nachtruhe bewahrt.

Im Akkubetrieb sieht das anders aus. Noko ständig im Stromsparmodus zu betreiben ist natürlich langweilig, da das Display nicht nur gedimmt, sondern ganz aus ist. Daher empfiehlt es sich, den Nachtmodus und die Dimmfunktion einzuschalten. Wird er längere Zeit vom Stromnetz genommen, so ist der Menüpunkt Akku sparen durchaus sinnvoll. Auf diese Weise hält Noko auch ohne Ladestrom einen Tag durch. Tapferer Noko.

Noko hat nie was dagegen, wenn sein Display mit Drücken der linken Hand manuell gedimmt wird, sollte man mal das Haus verlassen. Alleine schon der Umwelt zuliebe.

> NOKO stellen

> weiter...

> Akku sparen [ ]

> Nachtmodus [an ]

> Akku sparen [X]

> [an ] Dimmen [X]

# Noko

# Fragen und Anworten

Hier sind Antworten auf Fragen und Probleme, die auftreten könnten.

Hilfe! Noko sagt nichts mehr! Warum?
Das könnte verschiedene Ursachen haben:

Vielleicht ist er via USB am Computer verbunden? Vielleicht ist der Nachtmodus aktiv?
Vielleicht ist die Lautstärkeregelung auf Minimum? Vielleicht ist er gedimmt im Akkusparmodus? Vielleicht ist er aus?

Hilfe! Ich drücke eine Taste, aber es passiert nichts!
Noko ist nicht der Schnellste. Manchmal klappt die Abfrage nicht sofort, machmal sogar gar nicht. Einfach wieder versuchen. Vielleicht hilft es auch, die Taste etwas fester zu drücken. Noko ist hart im Nehmen.

Hilfe! Noko lacht, aber reagiert erst spät auf die Taste!
Leider braucht Noko einige Zeit, wenn das MP3-Modul etwas wiedergibt. Es ist aber kein zweites Drücken mehr notwendig. Das ist zugegeben manchmal etwas nervig, aber nunmal seine Natur.

Hilfe! Das Display geht die ganze Zeit aus!
Wenn man Noko in den Händen hält, sein Display aber dennoch immer wieder kurz oder länger ausgeht, so ist er gedimmt, erkennbar an einem D neben der Uhrzeit, hat aber das Distanzlicht aktiv. Einmal die linke Hand drücken.

Hilfe! Das Menü ist trotz des Distanzlichtes dunkel!
Gleiches Problem wie oben: Er ist gedimmt. An hellen Sommertagen draußen ist das kein Problem. Ist die Displaybeleuchtung aus, weil man sich außerhalb des Distanzsensors befindet, wird es im Menü nicht angeschaltet. Der Distanzsensor funktioniert nur bei der Uhrzeitanzeige!

Hilfe! Noko ist frech!
Ja. Das ist er. Da kann man nichts machen. Außer vielleicht Events auf 0 stellen oder die Lautstärke runter drehen. Aber dann ist er auch langweilig. Wer will das schon?

# Noko

# Anhang

## Eigene MP3s auf Noko spielen

Dazu muss Noko zunächst über den USB-Anschluss mit einem Computer verbunden werden. Beide Geräte müssen natürlich eingeschaltet sein.

MP3
Noko kann alle gängigen MP3s abspielen. Natürlich auch Stereo. Leider kann er nicht ID3-Tags auslesen, dafür jedoch den Dateinamen anzeigen. Aber auch hier gibt es Beschränkungen: Das 8.3-Format. Maximal acht Zeichen, natürlich nur Großbuchstaben und keine Sonderzeichen und Umlaute, für den Namen und die drei Zeichen für die Endung .mp3 - mehr ist leider nicht möglich.

Ein möglicher Dateiname wäre also NOKOLIED.mp3.

Linux
Es sollte sich nun ein Fenster öffnen. In diesem sollte sich das Verzeichnis MP3 befinden. Dort können nun die neuen MP3-Dateien hineinkopiert oder alte gelöscht werden. Zum Schluss noch das Laufwerk auswerfen, fertig.

Mac
Das konnte ich mangels Hardware leider noch nicht testen, sollte aber wie unter Linux ablaufen.

Windows
Tja. Hier ergibt sich eine Besonderheit: Sobald Noko
eingesteckt | wird, | öffnet | das | MP3-Modul | eine
Benutzeroberfläche, mit der einfach Dateien kopiert werden können. Sehr praktisch. Aber leider auf Chinesisch...
1. Zweiten Tabulator anwählen.
2. Den Knopf rechts drücken.
3. Im Auswahlmenü das Quellverzeichnis und anschließend die MP3s zum Aufspielen wählen.
4. Ersten Tabulator anwählen.
5. Den Knopf drücken.

Nun werden die Datein hochgeladen, was anhand eines Fortschrittbalkens extrem eindrucksvoll dargestellt wird.

# Noko

# Hinweise

Nokos Firmware wird ständig weiterentwickelt. Anhand der beiliegenden Software kann eine neue Firmware aufgespielt werden. Alle Besitzer werden via Email informiert, wenn eine neue Firmware erstellt wurde.

Ladespannung: | 5V 1A
Akku: | LiPo 3,7V mit Überhitzungs- und Entladeschutz

Fragen bitte an
kontakt@nikolairadke.de

Noko wurde entworfen, programmiert und gebaut von Niko, genäht hat ihn Nora. Danke an: Nikos Vater (Bau und Test), Carsten Caniglia (Stimme).

Interesse an Noko?
https://github.com/NikolaiRadke/Noko
Baut Nokos. Denkt auch an Eure Freunde.

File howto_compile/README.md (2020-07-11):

# Compiling instructions for Noko
### NOTE: These options are used globally for all sketches.

**Prerequisits**  
If you have Optiboot installed, you don't need to change anything.  
If you have IDE 1.6.10 or higher with AVR Core 1.6.12 or higher, relax, but Optiboot is always recommended.  

Linux: with IDE 1.6.6-1.6.9 use AVR Core 1.6.9 and see intructions below.  
Windows: IDE 1.6.6-1.6.9 will *not* work without Optiboot. Install Optiboot and see intructions below.

### Note:
The sketch will **not** run without the Si4703 radio module. If you want to test it anyway, you have to modify *Noko.ino*. Change the line  
```#define def_radio 1           // Using Radio?```   
in the beginning of the sketch into   
```//#define def_radio 1           // Using Radio?```    

Now, the radio functions are commented out and disabled.  

## Instructions for older IDEs   

### platform.txt

To compile Noko.ino, you need to modify the file configuration file platform.txt.  
- In Linux, it can be found under 
`/usr/share/arduino/hardware/arduino/avr/platform.txt`

- In Windows under 
`[Arduino folder]/hardware/arduino/avr/platform.txt`

Open your **platform.txt** and overwrite the lines after the line
```
# These can be overridden in platform.local.txt
```
with the lines below. Without these options the compiled sketch would exceed the 30kb flash memory of the Arduino Nano. With Optiboot, it will just fit.

Alas, until now I wasn't able to find out more about *platform.local.txt*, which allows the user to define a specific platform.txt locally for each sketch. So better backup your old platform.txt to save your old compiler options. 

### Linux and Windows with IDE 1.8.2 and higher (optional, saves about 700 byte flash)

```
# These can be overridden in platform.local.txt
compiler.c.extra_flags=-funsafe-math-optimizations -mcall-prologues -maccumulate-args -ffunction-sections -fdata-sections -fmerge-constants
compiler.c.elf.extra_flags=-funsafe-math-optimizations -mcall-prologues -maccumulate-args -ffunction-sections -fdata-sections -fmerge-constants
compiler.S.extra_flags=
compiler.cpp.extra_flags=-funsafe-math-optimizations -mcall-prologues -maccumulate-args -ffunction-sections -fdata-sections -fmerge-constants
compiler.ar.extra_flags=
compiler.objcopy.eep.extra_flags=
compiler.elf2hex.extra_flags=
```  

### Linux with IDE 1.6.9 and below  

```
# These can be overridden in platform.local.txt
# Compiling options for NOKO and NOKO.ino
compiler.c.extra_flags=-flto -funsafe-math-optimizations -mcall-prologues -maccumulate-args -ffunction-sections -fdata-sections -fmerge-constants
compiler.c.elf.extra_flags=-flto -funsafe-math-optimizations -mcall-prologues -maccumulate-args -ffunction-sections -fdata-sections -fmerge-constants
compiler.S.extra_flags=
compiler.cpp.extra_flags=-flto -funsafe-math-optimizations -mcall-prologues -maccumulate-args -ffunction-sections -fdata-sections -fmerge-constants
compiler.ar.extra_flags=
compiler.objcopy.eep.extra_flags=
compiler.elf2hex.extra_flags=
```
### Windows with IDE 1.6.9 and below  
```
# These can be overridden in platform.local.txt
# Compiling options for NOKO and NOKO.ino
compiler.c.extra_flags=-funsafe-math-optimizations -mcall-prologues -maccumulate-args -ffunction-sections -fdata-sections -fmerge-constants
compiler.c.elf.extra_flags=-funsafe-math-optimizations -mcall-prologues -maccumulate-args -ffunction-sections -fdata-sections -fmerge-constants
compiler.S.extra_flags=
compiler.cpp.extra_flags=-funsafe-math-optimizations -mcall-prologues -maccumulate-args -ffunction-sections -fdata-sections -fmerge-constants
compiler.ar.extra_flags=
compiler.objcopy.eep.extra_flags=
compiler.elf2hex.extra_flags=
```
Unfortunately, on Windows the Link Time Optimization (LTO) plugin is disabled in IDE 1.6.6-1.6.9, the *-flto* switch is unusable. The sketch fits barely into flash memory, so **Optiboot** is a **must have**! See [Issue 3](https://github.com/NikolaiRadke/NOKO/issues/3).  
You can find an intruction on how to flash a new bootloader in German [here in the wiki](https://github.com/NikolaiRadke/NOKO/wiki/Optiboot). An English instruction will follow. Until then take a look [here](https://www.arduino.cc/en/Tutorial/ArduinoISP).

## How to upload a precompiled hex-file  

Select the hex-file of your choice in [howto_compile/precompiled](https://github.com/NikolaiRadke/NOKO/tree/master/howto_compile/precompiled). Notice that files **older than 170517** are made for **displays** with **0x27**-address. If you need a file with anoher address like *0x3f* just contact me. You need a special file? Feel free to ask me, i'll try my best!  

### Linux  
See if you habe *avrdude* installed. Open a shell and type ```avrdude```. If not, install is with ```sudo apt-get install avrdude``` for Debian-based systems. Test again. Connect your Arduino via USB, open a terminal and use the following command:

With OptiBoot:  
```avrdude -v -patmega328p -carduino -P/dev/ttyUSBX -b115200 -D -Uflash:w:XXXXX.hex:i```  
Without OptiBoot:  
```avrdude -v -patmega328p -carduino -P/dev/ttyUSBX -b57600 -D -Uflash:w:XXXXX.hex:i```  

* XXXXX.hex is the name of your selected hex-file.  
* X in ttyUSBX is the number of your USB-port connected to the Arduino. In most cases, ist is *ttyUSB0*. If not, look into the Arduino-IDE for the correct number.  
  
### Linux Updater  
Just run **nokoflash** in [howto_compile/precompiled/Flashtool](https://github.com/NikolaiRadke/Noko/tree/master/howto_compile/precompiled/flashtool) and select the firmware of your choice. Needs *avrdude* (see above). The GUI was written in TCL/TK and should run on every modern Linux Distribution and OSX. Maybe the *tk* and *wish* packages are needed, if it does not run at once.   

Try *blink.hex* to test the tool :-)  

### Windows (Stupid stupid Windows)
Get *avrdude* either from sourceforge or better, because you need libusb0.dll as well, from [howto_compile/precompiled/avrdude_win](https://github.com/NikolaiRadke/Noko/tree/master/howto_compile/precompiled/avrdude_win). Copy the files to your machine and add the hex-file of your choice from [howto_compile/precompiled](https://github.com/NikolaiRadke/Noko/tree/master/howto_compile/precompiled) into the same directory. Open the command prompt with admin rights und use the following command:  

With OptiBoot:  
```avrdude v -patmega328p -carduino -P\\.\COMX -b115200 -D -Uflash:w:XXXXX.hex:i```  
Without OptiBoot:  
```avrdude v -patmega328p -carduino -P\\.\COMX -b57600 -D -Uflash:w:XXXXX.hex:i```   

* XXXXX.hex is the name of your selected hex-file.  
* X in COMX is the number of your USB-port connected to the Arduino. In most cases, it is *COM1*. If not, look into the Arduino-IDE for the correct number.

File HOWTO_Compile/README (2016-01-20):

Compiling options for NOKO
NOTE: These options are used global for all sketches.

Open your platform.txt and overwrite the lines after the line
"# These can be overridden in platform.local.txt"
with the lines below.

Alas, until now i wasn't able to find out more about platform.local.txt. 
So backup you old platform.txt to save your old compiler options. 

# These can be overridden in platform.local.txt
compiler.c.extra_flags=-Wextra -flto -funsafe-math-optimizations -mcall-prologues -maccumulate-args -ffunction-sections -fdata-sections -fmerge-constants
compiler.c.elf.extra_flags=-w -flto -funsafe-math-optimizations -mcall-prologues -maccumulate-args -ffunction-sections -fdata-sections -fmerge-constants
compiler.S.extra_flags=
compiler.cpp.extra_flags=-Wextra -flto -funsafe-math-optimizations -mcall-prologues -maccumulate-args -ffunction-sections -fdata-sections -fmerge-constants
compiler.ar.extra_flags=
compiler.objcopy.eep.extra_flags=
compiler.elf2hex.extra_flags=

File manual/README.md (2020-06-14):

# Manual for Noko
This folder contains the 19 page manual as a PDF, written in German. Box.pdf is a design template to place Noko in a
pretty matching gift box.

Both PDFs have been written with [Scribus](http://www.scribus.net). The source files, fonts and illustrations are
in the folder [/scribus](https://github.com/NikolaiRadke/Noko/tree/master/manual/scribus), so you can change the manual as you wish or translate it in any language. Please fork this repository or send a copy.

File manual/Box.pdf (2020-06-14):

Noko


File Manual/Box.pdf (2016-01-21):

NOKO


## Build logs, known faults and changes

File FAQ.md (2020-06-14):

# FAQ

### Why Arduino? A Raspberry PI is much more powerful.
Yes, but much more complicated to install, larger and takes MUCH more battery power. Are there any features missing? I don't think so. Noko is as good as it is.

### Why this crappy LCD? There are cheap colorful touchscreens.
Yes, there are, but the LC display should be an easy-to-read clock and a lightsource. Besides, the Arduino ressources are very VERY limited. Noko doesn't need a touchscreen. He has buttons for a more haptical experience.

### Is it possible to fast forward a story or an own MP3?
No, it is not supported by the JQ6500-Module. 
  
### Why does it not do or have XXX?
You got a good idea? Write me!

### When did your work on Noko start?
I started wasting my time in March, 2014.  

# More FAQ (German)
See project page of Make Magazin:  
[Noko-FAQ](https://www.heise.de/make/artikel/Noko-FAQ-3618296.html)

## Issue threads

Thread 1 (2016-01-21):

Repository is not complete

NikolaiRadke, 2016-01-21:
Yes... i'm working on it. Please stay patient.

NikolaiRadke, 2016-01-22:
Das dauert ja ne ganze Weile und viele Commits, um GitHub und die Funktionen zu verstehen. Aber langsam habe ich das alles Verstanden und arbeite fleißig am Wiki.

Closed 2016-04-18.

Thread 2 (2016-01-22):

Which licence?

NikolaiRadke, 2016-01-22:
Ich habe keine Ahnung, welches Lizenzmodell ich wählen soll. Die meisten verwendeten Bibliotheken im Quelltext verwenden GPL v3, einige MIT. Jemand riet mit zu APACHE 2.0 - ich habe aber keine Ahnung, warum.

Vielleicht kann mich jemand aufklären?

StephanSST, 2016-09-19:
Ich kenne auch nicht alle drei, weiss aber, dass MIT die einfachste ist. Da darf man alles, muss aber auf Deinen Code bzw. Deine Lizenz zurückverweisen.

So wie ich Apache 2.0 verstanden habe, würde diese Lizenz verbieten, dass ein anderer Deinen Code patentieren lässt. Aber da bin ich auf Glatteis.

Ich würde also sagen, wenn Du nicht bzw. nie vor hast, mit Noko Geld zu verdienen, dann nimm MIT.

NikolaiRadke, 2016-10-16:
Hm. Mein Code ist eher auf Grundstudium Informatik-Niveau, aber alleine schon aus Verlagsgründen möchte ich doch die Rechte daran behalten. Dann kommt also eher Apache in Frage.

Danke für die Info!

hkuhn42, 2016-10-16:
Apache / BSD erlaubt jedem alles (ändern,neu veröffentlichen etc.) , solange er deine Copyright Disclaimer nicht entfernt und ist damit ziemlich offen.
Falls Du Zeit zum lesen hast, gibt es bei [Heise](http://www.heise.de/ct/artikel/Open-Source-Lizenzen-221957.html) eine relativ gute Übersicht der Unterschiede.

NikolaiRadke, 2016-10-28:
Danke für den Link!

Closed 2018-03-05.

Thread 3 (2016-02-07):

Windows (IDE 1.6.7): Won't compile with -flto

NikolaiRadke, 2016-02-07:
I always get
``` collect2.exe: fatal error: CreateProcess: No such file or directory ```.

Without Link Time Optimization the sketch will be 3kb larger and wont't fit
 into flash without Optiboot.

NikolaiRadke, 2016-02-07:
Hm. I found this:
``` LTO permanently removed for Arduino IDE as the plugin is not correctly delivered in the AVR GCC tool chain for Arduino. ```

Drat!

NikolaiRadke, 2016-08-19:
LTO is back!

Closed 2016-08-19.

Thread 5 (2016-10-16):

TDA7053a wird nicht mehr produziert

NikolaiRadke, 2016-10-16:
Im August wurde nach vielen Jahren die Produktion eingestellt. War ja klar. Der erste Verstärker, mit dem ich zufrieden war. Und natürlich gibt es keinen Nachfolger. Die Suche geht also weiter, ich werde es mal mit dem TDA7057aq versuchen.

Der TDA7053a ist noch in China erhältlich. Wer nicht fündig wird oder absolut nicht warten kann, soll sich an mich wenden, ich habe noch einige vorrätig.

NikolaiRadke, 2016-11-12:
Aus Großbritannien für unter 5€ inkl. Porto:
http://www.ebay.de/itm/TDA7053A-Integrated-Circuit-Case-DIP16-Make-NXP-Semiconductors-/172140647270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

Crayfish68, 2018-03-16:
Es gibt (derzeit) einen eBay Verkäufer in Shen Zen, der die TDA7053a im 5er Pack für $3,29 (bei mir kamen etwa 2,65€ bei der Konvertierung raus) anbietet, das sind also 53ct pro Stück. Versandkostenfrei.
[https://www.ebay.de/itm/5pcs-TDA7053A-STEREO-BTL-AUDIO-OUTPUT-AMPLIFIER-DIP-16/172454933389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](https://www.ebay.de/itm/5pcs-TDA7053A-STEREO-BTL-AUDIO-OUTPUT-AMPLIFIER-DIP-16/172454933389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)
Sie haben bei mir allerdings 48 Tage bis zur Ankunft benötigt.

NikolaiRadke, 2018-03-16:
Ah! Das lohnt sich ja gerade. Ich habe eben 10 Stück für 5,55€ bestellt.

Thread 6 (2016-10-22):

Kein Issue, eher eine Frage ...

teuler, 2016-10-22:
Hi, mir gefällt das Projekt sehr gut. Eine Frage zum Verstärker: Ich verwende ein DAB-Radio-Modul und hatte große Probleme mit dem Empfang, sobald ich die Verstärkerschaltung (mit dem TDA7053a) anschloss. Nach etwas 'rumprobieren fand ich heraus, dass das Step Up-Modul (MT3608) für die Störungen verantwortlich ist und der Verstärker (ich betreibe ihn allerdings Mono) auch mit stabilisierten 5V aus einem USB-Hub läuft. Was spricht dagegen, den Verstärker mit 5V zu betreiben?
Vielen Dank und Grüsse,
Thomas

NikolaiRadke, 2016-10-27:
Hallo Thomas,

entschuldige die späte Antwort, Deine Mail hat der Spamfilter gefressen.
Gegen 5V spricht die Klangqualität. Erst ab etwas mehr als 6V war der
Verstärker einigermaßen laut und klirrfrei. Wird auch im Datenblatt
empfohlen. Lauffähig ist er aber ab 4,5V, 5V sollten also auch gehen,
aber dann eben nicht kräftig krachen. Beim USB-Hub darauf achten, dass
er mindestens 1A bei Spitzenlast gibt. Die Ports an meinen Computern
gehen da schon lange in die Knie.

Liebe Grüße,

Nikolai

--

	*Nikolai Radke*

Tel.  : 0171 401 22 69
Mail: kontakt@nikolairadke.de <mailto:kontakt@nikolairadke.de>
Web: http://www.nikolairadke.de

teuler, 2016-10-29:
Hallo Nikolai,

danke für die Nachricht und die Info.
Ich kann kein Klirren feststellen und laut genug ist der Verstärker auch. Ich denke, ich bleibe erstmal bei 5V - ich habe bisher keinen Spannungswandler (5V -> 6.5V oder höher) gefunden, der nicht den DAB Receiver massiv stört. Beim USB-Hub habe ich darauf geachtet, dass er ein externes Netzteil mit mindestens 3A mitbringt.

Beste Grüsse,
Thomas

NikolaiRadke, 2016-10-31:
Da bin ich gespannt, halt mich auf dem Laufenden.
Was ist das für ein DAB-Modul?

teuler, 2016-10-31:
http://www.monkeyboard.org/products/85-developmentboard/80-dab-fm-digital-radio-development-board

NikolaiRadke, 2016-11-13:
Danke für den Link. Bin gespannt, was daraus wird!

teuler, 2016-12-19:
https://github.com/teuler/Grundig60

NikolaiRadke, 2016-12-21:
Tolle Idee, schönes Projekt!

Closed 2017-05-29.

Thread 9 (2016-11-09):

Printrelais ST3 002 H5W alternative ?

JimmyBondi, 2016-11-09:
Hallo Nikolai,

auch ich bin gerade dabei mir alles herauszusuchen.
Dabei ist mir aufgefallen, dass das genannte Printrelais anscheinend ebenfalls nicht mehr verfügbar ist.
Welches könnte ich denn alternativ dafür nehmen ?

Danke und Gruß,
Lars

NikolaiRadke, 2016-11-09:
Oje... schon wieder ein Bauteil, das eingestellt wurde. Es ist zum verrückt werden.
In Frage käme vielleicht das G6K-2P 5V. Allerdings braucht dieses Relais noch eine Schutzdiode. Ich kümmere mich am Wochendende darum. Dabei ist mir auch ein Fehler im Verdrahtungsplan aufgefallen, es sind Plus und Minus, also Pin1 und Pin10 vertauscht. Interessanter Weise funktioniert es trotzdem tadellos :-)

Viele Grüße,

Nikolai

bencha, 2016-11-11:
Diesem Thema schließ mich an, bin gespannt welche Lösung folgt.

Vorab schon mal vielen Dank
Ben

NikolaiRadke, 2016-11-12:
Das Printrelais ist nun ein FRT8S. Dass benötigt allerdings noch eine Freilaufdiode in Sperrichtung. Hierfür reicht eine 1N4001 aus. Das Relais ist genauso groß und hat diesselbe Pinbelegung wie das ST3 002 H5W. Das Wiki wurde entsprechenend angepasst.

bencha, 2016-11-13:
Hallo Nikolai,

erstmal vielen Dank für das Feedback, aber leider muss ich Dir sagen, Du machst es uns nicht einfach.
Ich suche nun seit 1h nach dem Printrelais und nicht mal die Dealer meines vertrauens (reichelt.de, Ebay.de, Conrad.de u. google.de) können das Relais finden. Die Freilaufdiode ist Wiederrum kein Problem.

Ich hoffe Du kannst uns auch hier weiterhelfen.

Danke und Grüße
Ben

NikolaiRadke, 2016-11-13:
Das liegt daran, dass ich mich gerne an den entscheidenden Stellen vertippe :-)
Das Relais heißt FRT5 DC5V (Reichelt) oder FRT5 DV05V (Conrad).

Zur Strafe muss ich jetzt wieder alle entsprechenden Texte im Wiki ändern.

NikolaiRadke, 2016-12-03:
Als Alternative zum Relais dient nun das gleich große und Pingleiche FRT5 DC5V. Allerdings benötigt dieses Relais noch eine Freilaufdiode.

Closed 2016-12-03.

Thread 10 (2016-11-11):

Battery

bencha, 2016-11-11:
Hallo an alle,

hat jemand einen Tip wo ich den Akku bestellen kann?

Danke für eure Hilfe und
viele Grüße
Benjamin

NikolaiRadke, 2016-11-12:
Im Auktionshaus des Vertrauens. Z.B. hier:
http://www.ebay.de/itm/LiPo-Akku-2000-mAh-3-7-V-Lithium-Polymer-Schutzschaltung-/182347325476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

Darauf achten, dass der Akku eine Schutzschaltung (PCM) hat!

bencha, 2016-11-13:
Hallo Nikolai,

danke für den Link und den Hinweis "Schutzschaltung (PCM)".

Grüße
Ben

Closed 2016-11-13.

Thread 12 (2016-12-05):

Taster

Crayfish68, 2016-12-05:
Hallo Nikolai! Tolles Projekt, Danke für die Idee und die ganze Arbeit, die da drin steckt!!!

Ich habe eine Frage zu den Tastern: welche (Art von) Tastern hat sich als geeignet erwiesen? Ich stehe etwas auf dem Schlauch. In der Bucht finde ich den Abbildungen ähnliche (6x6x5mm), wenn ich nach "THT Taster 4 Pin" suche, frage mich aber, ob die zu klein sind. Wie groß sind die, die du benutzt hast?

PS: nachdem sich die Idee, so etwas zu Weihnachten zu machen, rumgesprochen hat, ist der Bedarf hier auf 5 gewachsen - ich bin also grad in der Massenproduktion, bzw. derzeit noch im Massen-Bestell-Prozess. Vieles kommt aus China und lümmelt sicher noch in irgendwelchen Container rum. Mal schauen :)

Thomas

NikolaiRadke, 2016-12-05:
Meine sind haben eine Kantenlänge von ca. 1 cm - das ist ausreichend und gut zu bedienen. je größer, desto besser. Erhältlich in einschlägigen Elektronikonlineshops

Fünf Nokos! Au weia! Da wünsche ich starke Nerven ;-)
Viel Erfolg und viele Grüße!

Nikolai

Crayfish68, 2016-12-22:
Noch eine Frage bitte:

Was genau meinst du in der Stückliste mit:
--------------------snip----------------------
2 Stiftbuchsen mit 3 Steckern, 16-polig
1 Stiftbuchse mit 2 Steckern, 10-polig
--------------------snip----------------------
?
Soweit ich das bis jetzt übersehe, brauche ich doch 2 x 16-polige Buchsen (und eben 2 x 16-polige Stecker dazu) und 1 x 10-polige Buchse (mit 1 x 10-poligem Stecker), richtig? Warum dann 2 Buchsen mit 3 Steckern bzw. 1 Buchse mit 2 Steckern??

PS: Die Dinger heißen (glaube ich) "Pfostenverbinder" - hab mir 'n Wolf gesucht, vielleicht magst du es in der Stückliste anpassen? Ich lasse mich auch gerne eines Besseren belehren ;)

Danke
Thomas

NikolaiRadke, 2016-12-27:
Hallo Thomas,

sorry, hab Deine Nachricht übersehen.

Ich kann absolut nicht mehr nachvollziehen, was ich mir dabei gedacht habe. Ehrlich, keine Ahnung.
In NOKO sind 3 "Wannenstecker", 2x16 und 1x10-polig drin. Danke für den Hinweis. Die Stückliste und das Wiki werden überarbeitet.

Liebe Grüße,
Nikolai

Closed 2017-01-06.

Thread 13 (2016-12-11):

Beschreiben der EEProms (write_disk0/1)

jlegen, 2016-12-11:
Unter Windows 10 haben die beiden Programme "nach Anleitung" nichts in die EEProms geschrieben, obwohl der Ablauf (Zeit, Geblinke) normal aussah.
Das klappte erst, nachdem ich sowoho im Code, als auch im Gerätemanager den COM-Port auf 115200 Baud gesetzt hatte.
Ansonsten vielen Dank für ein wirklich interessantes Projekt! 👍

NikolaiRadke, 2016-12-12:
Danke für den Hinweis! Wird bezeiten geprüft - sobald ich ein Windows 10-Testgerät unter den Fingern habe.

Viele Grüße!

d1ckb31n, 2017-01-06:
Das kann ich so bestätigen. Mit der Default-Baudrate von 9600 laufen die Routinen zwar fehlerfrei durch aber Text wird scheinbar keiner geschrieben. Erst nach Anpassung der Baudrate des "Arduino-COM-Port" im Gerätemanager auf 115200 sowie der Codeanpassung in NOKO_EEPROM_Disk0.ino (Zeile 105) sowie NOKO_Disk1.ino (Zeile 22) von

`Serial.begin(9600);`
auf
`Serial.begin(115200);`

funktioniert es einwandfrei.

NikolaiRadke, 2017-01-12:
Kann ich auch bestätigen.
Danke für Eure Mitarbeit! Das Wiki und der Sketch werden angepasst.

Closed 2017-01-12.

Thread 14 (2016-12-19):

Prototyp: Nur knattern aus dem Lautsprecher

d1ckb31n, 2016-12-19:
Hallo,

ich habe jetzt den Prototyp nach Anleitung (allerdings ohne Radio) aufgebaut.

- Via USB 5V/1A am MP3 Modul passiert gar nichts, weder die LED am Modul noch das Display etc. geht an
- Via USB 5V/1A am Nano läuft soweit alles, nur das ich fortwährend nur "knattern" aus dem Lautsprecher höre, nichts anderes.

Irgendeine Idee?

By the Way: Auf der Einkaufsliste ist die Rede von einem 330Ohm Vorwiderstand für die LED, im Wiki sind es nur noch 300Ohm

d1ckb31n, 2016-12-19:
Das knattern beginnt übrigens sobald ich Pin 25 am MP3 Modul mit D3 verbinde.

NikolaiRadke, 2016-12-20:
Danke für den Hinweis. Das Wiki habe ich angepasst.
Ist der USB-Port das MP3-Moduls auf der linken Seite? Vielleicht stimmt die Pinbelegung nicht. Im Make-Magazin ist z.B. eine andere aufgeführt.

d1ckb31n, 2016-12-20:
USB Port ist wie in deiner Anleitung beschrieben, rechts (zeigt Richtung Nano). Links ist der MicroSD Slot.
Alle Bilder bei Google nach Q6500-P28 zeigen einen identisches Pinlayout. Hast du ggf. eine Grafik aus dem Make-Magazin oder einen Link?

Lautsprecher an sich funktionieren einwandfrei. Ebenso wird das MP3-Modul sauber am PC erkannt. Der Nano scheidet als Fehlerquelle egtl. auch aus. Ein identisch konfigurierter zeigt das selbe "knattern".

NikolaiRadke, 2016-12-21:
Da könnte ein Problem liegen: Ich verwende eine andere Pinnummerierung, als jene im Make (die stammt von der Redaktion). Bei mir liegt Pin 1 links neben dem USB-Anschluss. So wie in der Grafik sollte es aber klappen.

Hast Du mal versucht, nur das Modul zusammen mit einem Arduino und einem 8-Ohm-Lautsprecher zu betreiben?

d1ckb31n, 2016-12-27:
Selbst nur arduino und mp3 Modul in der Konfiguration (https://github.com/sleemanj/JQ6500_Serial/blob/master/README.md#jq6500_serial) geht nicht.

Klar es gibt hier kein knattern aber halt auch kein anderes audio out.

NikolaiRadke, 2016-12-28:
Hm. Vielleicht ist das Modul auch einfach kaputt?
Schick mir doch eine Mail mit einem Foto eines Minimalaufbaus, also nur Arduino und Modul samt eines Sketches zum Abspielen einer einzelnen Datei an meine Adresse: kontakt@nikolairadke.de
Ich prüfe das dann.

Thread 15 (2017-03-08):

MP3 Dateien

Wetimer, 2017-03-08:
Hallo NikolaiRadke,

bin momentan ebenfalls dabei dein Noko-Projekt (darauf gestoßen über das Make-Magazin) nachzubauen. Deine Beschreibung ist sehr gut und ich komme gut voran jedoch wollte ich gerade die MP3 Dateien (https://github.com/NikolaiRadke/NOKO/tree/master/mp3) downloaden und bekam eine Fehlermeldung. Gibt es einen anderen Weg an die MP3 Dateien zu kommen oder sind die Dateien gar nicht mehr vorhanden?

Gruß Wetimer

NikolaiRadke, 2017-03-08:
Hallo Wetimer,

ich habe eben nachgeschaut, die Dateien können problemlos
heruntergeladen werden: Anklicken, z.B. 001.mp3, dann rechts auf
"Download", oder das alternativ das Git klonen, oder einfach alles auf
der Startseite vom NOKO-Repository mit dem grünen Button "Clone oder
download" herunterladen.

Aber um Sicher zu gehen, habe ich die Dateien gezipt und auf meinen
Webserver geladen, da sollte nichts schief gehen:
http://www.nikolairadke.de/NOKO/noko.zip

Viel Erfolg und viele Grüße,

Nikolai

--

	*Nikolai Radke*

Tel.  : 0171 401 22 69
Mail: kontakt@nikolairadke.de <mailto:kontakt@nikolairadke.de>
Web: http://www.nikolairadke.de

Wetimer, 2017-03-08:
Hallo Nikolai,

vielen Dank für die schnelle Antwort!
Danke fürs zippen, hat problemlos geklappt!

PS: Habe mit dem Programm kicad ein PCB erstellt für die Noko-Schaltung (alles auf einer Platine). Sobald ich es getestet habe ob alles so funktioniert wie es soll kann ich es gerne zur Verfügung stellen falls Interesse besteht ?!

Gruß Wetimer

NikolaiRadke, 2017-03-08:
Hallo nochmal.

"Interesse" ist stark untertrieben :-)
Sehr gern!

Liebe Grüße,

Nikolai

--

	*Nikolai Radke*

Tel.  : 0171 401 22 69
Mail: kontakt@nikolairadke.de <mailto:kontakt@nikolairadke.de>
Web: http://www.nikolairadke.de

Wetimer, 2017-03-08:
Ok dann melde ich mich nochmal sobald es fertig ist :)

Closed 2017-03-13.

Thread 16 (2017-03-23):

Leiterplatte

ylth94, 2017-03-23:
Hi,
gibt es inzwischen einen Bastler, der sich die Mühe gemacht hat eine Leiterplatte für NOKO zu entwerfen?

VG
Yannik

NikolaiRadke, 2017-03-24:
Hallo Yannik!

Ja, einer hat angekündigt, daran weiter zu arbeiten, will aber - völlig unnachvollziehbar!! - erst seine Masterarbeit im April beenden. Ein weiterer User ist dran, hat aber wenig Zeit.

Also ein klares "eventuell".

LG,
Nikolai

ylth94, 2017-03-24:
Hi Nikolai,
vielen Dank für die schnelle Antwort! Dann bin ich mal gespannt und warte ab!

VG Yannik

NikolaiRadke, 2017-05-06:
Lieber Yannik,

leider warte ich immer noch. Wenn Du also Lust hast - NOKO, ich und viele Bastler würden sich freuen über Deinen technisch-heroischen Einsatz :-)

LG,
Nikolai

ylth94, 2017-05-10:
Hallo Nikolai,

ich kann mich mal dran versuchen, aber ohne viel zu Verspechen! ;-)

Viele Grüße
Yannik

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

NikolaiRadke, 2017-05-11:
Wer NOKO etwas verspricht, hat selber Schuld  :-D
Viel Erfolg und danke für Deine Mühe,

Nikolai

Wetimer, 2017-05-27:
Hallo zusammen,

ich hätte ein fertiges Layout, jedoch arbeitet Noko noch nicht ganz wie gewünscht (Lautstärkeregelung über Poti funktioniert noch nicht). Sobald ich weiß woran es liegt und ich es ausschließen kann, dass es ein Fehler im Layout ist stell dich Dateien fürs Layout zur Verfügung.

Grüße
Wetimer

NikolaiRadke, 2017-05-28:
Oooooooh... da freue ich mich aber!
Das Poti regelt den TDA7053a an Pin 2 und Pin 8. Da kann man eigentlich nicht viel falsch machen.

Ich bin sehr gespannt! Auch wenn es wieder viel Tipparbeit für die Dokumentation bedeutet :-)

Liebe Grüße,
Nikolai

NikolaiRadke, 2017-05-28:
Interessant wäre auch eine Variante ohn den Regulator, was die Akkulaufzeit erheblich steigern würde. Angeblich läuft ja der Verstärker auch mit 5V problemlos. Die Probleme mit Störungen können durchaus an meiner wilden Verdrahtung angefallen sein...

teuler, 2017-05-28:
Bei mir läuft der Verstärker mit 5 V aus einem USB Netzteil seit Monaten verlässlich.

NikolaiRadke, 2017-05-29:
Siehe Make 2/2017 :-)

Wetimer, 2017-05-29:
Ja die Beschaltung des TDA passt auch soweit, also muss iwo anders im Layout der Fehler liegen (AUX-Eingang funktioniert auch noch nicht)... nicht wundern wenn es noch ein paar Wochen dauert (bin jetzt erst mal für ne Weile im Urlaub;) )

NikolaiRadke, 2017-05-30:
Kompliziert.
Nen schönen Urlaub!

Wetimer, 2017-06-20:
Also Schaltplan steht, das Layout wird vermutlich im Laufe dieser Woche oder spätestens nächster Woche fertig sein. Ich werde das neue fertige Layout jedoch leider nicht mehr testen können, da ich momentan noch keine Möglichkeit habe eine Platine selbst zu erstellen und nochmals welche zu bestellen ist mir zu teuer. Falls jmd das Layout testet kann würd ich mich über eine Rückmeldung freuen (funktioniert alles bzw. gibt's Layoutfehler etc. ). Notfalls kann ich dann auch nochmals das Layout überarbeiten.

Bis bald.

Grüße
Wetimer

ylth94, 2017-06-20:
Hallo zusammen,

leider bin ich wegen diverser Prüfungen an der Uni noch nicht so weit wie Wetimer.
Jedoch hätte ich bei uns an der Uni die Möglichkeit Leiterplatten-Prototypen zu fertigen! Also wenn ich da helfen kann, gerne.

Viele Grüße
Yannik

NikolaiRadke, 2017-06-21:
Das wäre ja großartig!!
Wenn nicht, so bin ich auch bereit, mal ein paar Euro in die Hand zu nehmen.

Viele Grüße!

ylth94, 2017-06-24:
Sollte zu 90% klappen! Bräuchte dann nur den fertigen Entwurf als Eagle oder Gerber file :-)

Viele Grüße!

Wetimer, 2017-06-25:
Hört sich sehr gut an ! :)
Bin jetzt fertig mit den Layout-Dateien, habe sie als Gerber Files abgespeichert. Leider kann ich das File-Format hier nicht als Anhang hinzufügen.
Ich könnte Sie NikolaiRadke per Mail schicken und er kann Sie dann bei sich hier im Projektverzeichnis hinzufügen ?! Oder gibt es eine andere Möglichkeit ?

NikolaiRadke, 2017-06-26:
Das ist doch die beste Lösung.
Die Dateien bitte an kontakt@nikolairadke.de

Danke schonmal für Eure Mühe!

NikolaiRadke, 2017-06-27:
Ich habe die Dateien bekommen, allerdings enthält das Layout einen Fehler (den ich selbst verbockt bzw. verbugt habe): Der Widerstand zum MP3-Modul sitzt an D3, nicht an D2.

Vor einem halben Jahr hat mich ein fleißiger User darauf aufmerksam gemacht :-)

Vielen Dank schonmal für die Dateien! Ich würde es selber ändern, kann es aber leider (noch) nicht...

NikolaiRadke, 2017-06-27:
Ich habe die Dateien schon mal hochgeladen.

NikolaiRadke, 2017-07-05:
Lieber Yannik,

Wetimer und ich haben die Dateien nun soweit fertig, ich habe sie im oben genannten Verzeichnis abgelegt.

Dann drücken wir Dir mal die Daumen :-)

Viele Grüße!

ylth94, 2017-07-10:
Hallo Zusammen,

ich habe die Dateien erhalten! Leider ist die Fräse nicht immer zugänglich und wo es was umsonst gibt sind viele in der Schlange :-D Ich gebe gas!

Viele Grüße !

NikolaiRadke, 2017-07-11:
Uiuiuiuiui, das ist ja wie Weihnachten!

Wetimer, 2017-07-12:
Hallo ylth94,

du willst die Leiterplatte fräsen ?! Ich glaube nicht, dass dir das besonders gut gelingen wird, da auf der Leiterplatte auch SMD Bauteile vorhanden sind ...eine Möglichkeit zu ätzen hast du nicht an der Uni ?

ylth94, 2017-07-20:
Hey,
Die SMD Bauteile sollten kein problem darstellen, das habe ich schon oft gemacht. Allerdings sind in den Gerber files keine drill-files enthalten, also wir haben heute beim Versuch zu fräsen keine Löcher gefunden. Könntest du mir die Ki-Cad Datei zukomenlassen? Am besten Per mail, weil veröffentlicht werden müssen sie ja nicht.
Viele Grüße

peddi47, 2017-07-21:
Das sehe ich anders. Mir fehlen die auch, um Bauteile zu tauschen und die Platine zu fräsen.

Am 20. Juli 2017 20:30:29 MESZ schrieb ylth94 <notifications@github.com>:
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

--
Diese Nachricht wurde von meinem Android-Gerät mit K-9 Mail gesendet.

Wetimer, 2017-07-24:
Hallo zusammen,

habe das drill-File Nikolai geschickt. Er wird's (hoffentlich) zu den restlichen Daten hinzufügen damit Sie vollständig sind.

Viele Grüße

NikolaiRadke, 2017-07-24:
Hab ich gemacht:
https://github.com/NikolaiRadke/NOKO/tree/master/schematics/layout

Viel Erfolg Euch allen!

ylth94, 2017-08-03:
Hallo Zusammen,

die Leiterplatte is gefertigt und sieht soweit gut aus, müssen jetzt nur noch die Vias gelötet werden, dann kann sie bestückt werden.
Soll ich das tun oder möchte jemand von euch den Prototyp haben?

Viele Grüße

NikolaiRadke, 2017-08-17:
Hallo!

Sorry für die späte Antwort, ich bin gerade (mit NOKO) nach Berlin gezogen und habe noch viel um die Ohren. Ich würde gerne helfen, aber ich befürchte, dass ich das nicht kann :-(

Liebe Grüße

NikolaiRadke, 2017-09-21:
Gibt es was neues von der Platine?
Der Heise-Verlag hat auch Interesse bekundet.

ylth94, 2017-09-21:
Hallo Zusammen,

leider hatte ich 3 Prüfungen den ganzen September.. Montag ist endlich die Letzte! Danach bin ich sofort wieder auf und dran. Sorry das es sich so hin zieht!

VG

ylth94, 2017-10-16:
Hallo,

ich habe die Leiterplatte durchkontaktiert und feststellen müssen, dass es nicht klappt. Ich war leider zu überzeugt vom Leiterplatten fräsen. Chemisch wäre doch die bessere Methode gewesen... Habe jetzt alles versucht sie "zum laufen" zu bekommen. Konnte deshalb auch die Leiterplatte nicht richtig testen (im Blick auf NOKO und seine Funktionen).

Aber wenn Heise ja Interesse hat, vielleicht können sie einen Prototyp organisieren, denn Heise hat sicher einen festen Zulieferer was Platinen angeht.

Also ich bin leider gescheitert, tut mir leid.

Viele Grüße Yannik
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
teuler, 2017-11-30:
Der Verstärker läuft seit mehr als einem Jahr verlässlich und mit sehr gutem Klang mit 5 V; ich versorge ihn direkt aus einem USB-Hub. Allerdings habe ich ihn ausschließlich mit dem alten [Originallautsprecher ](https://github.com/teuler/Grundig60/wiki/Geh%C3%A4use-%C3%BCberarbeiten) des Radios getestet; von dem habe ich aber die Spezifikationen nicht.

Crayfish68, 2017-11-30:
Vielen Dank für die Blumen - das geht natürlich runter wie Öl! ;)

Ich habe auch schon diverse Ideen für die nächste Version der Leiterplatte, ist auch schon in Arbeit. Die wichtigste Frage wäre natürlich, wie die Schaltung aussähe, käme das StepUp Modul raus. Das ersparte natürlich einiges an Platz auf der Leiterplatte. Käme der 5V Regler dann auch raus? Die Batteriespannung betriebe dann alles? Besäße ich ein Oszi, testete ich es selbst.

Aber genug vom Konjunktiv! Wenden wir uns dem Imperativ zu: Nikolai, mach mal! :)

Das Grundig Radio Projekt habe ich auch gesehen, alle Achtung, sehr schick! Den DrehKo anzuzapfen ist ja ein echtes Husarenstück. Den Lautsprecher tippe ich auf 60Ohm ;) Vor allem das DAB+ Modul finde ich richtig gut, obwohl es (relativ) teuer ist. DAB+ Radio hat sich mMn immer noch nicht richtig in DE durchgesetzt, weil die DAB-Radios alle einfach _potthäßich_ sind! Hier könnten Maker sicher helfen, dazu bräuchte es aber ein preiswerteres Modul. Dieses hier, kann man ja nicht mal eben zerschießen.

vG
Crayfish

NikolaiRadke, 2017-11-30:
Ja Sir!
Aber erst mach ich den 6,2V-NOKO, sonst würde ich Deine Arbeit ja nicht angemessen würdigen :-)

Die 5V-Variante benötigt natürlich auch den Step-Up, da der Akku ja nur, je nach Ladestand, 3,2-4,2V liefert. Der Regulator, der außer dem Verstärker alle anderen Geräte versorgt, würde dann wegfallen, alle Geräte würden direkt am Step-Up hängen. Darüber hinaus würde der Akku länger halten, da diese "Heizung" ja weg fällt, zudem wäre NOKO weniger anfällig gegenüber Störgeräuschen. Das kann ich zwar nicht bestätigen, ist aber häufig im Netz nachlesbar, dass Step-Up und Regulatoren sich nicht allzu gerne mögen.

teuler, 2017-11-30:
@NikolaiRadke Wäre eine günstige Powerbank nicht eine gute Energiequelle? Eine, bei der man eine Ladebuchse herausführt? Dann könnte man die Schaltung noch ein bisschen vereinfachen.
@Crayfish68 Ja, das DAB-Modul ist nicht günstig. Es scheint aber robust zu sein; ich hab's nicht kaputt gekriegt. Ärgerlicher ist eher, dass man die Infos über die Ansteuerung erst beim Kauf erhält; meine Arduino library durfte ich nicht auf GitHub stellen, da sie "proprietäre" Information enthält. So muss jeder, der das Modul nicht vom PC aus mit VisualBasic ansteuern möchte, sich wieder selbst 'was zusammenbasten - ist nicht schwierig, aber unnötiger Aufwand.

Crayfish68, 2017-12-01:
Das mit der PowerBank war schon einmal in der Diskussion irgendwo. Die PowerBanks haben zu 97% die LiIon Typ 18650 drin. Die sind deutlich größer. Mein LiPo ist 3,6mm dick, ein 18650 hat 18,5mm Durchmesser. Dafür kostet er zugegebenrmaßen nur etwa die Hälfte.
Baulich ist ein flacher LiPo Akku allerdings am idealsten. Ich wüsste jetzt nicht, wie und wo ich die 18650 unterkriegen sollte.
Ausserdem müßte man dann zwingend das Lademodul mit Lade- _und Ent_ ladeschutz haben. Aus einem total banalen Grund: für die 18650 _mit_ Entladeschutz gibt es keine Halterungen, weil diese 5mm länger sein müsste. Keine Ahnung warum, ich suche seit ca. 6 Monaten danach, es gibt sie einfach nicht. Derzeit säge ich normale Halterungen ausseinander und schraube sie dann mit 5mm Abstand auf ein Brett. Is'n Traum!

NikolaiRadke, 2017-12-02:
Die Powerbank müsste auch einen Strom von 2A liefern, da der Verstärker bei Spitzenlasten doch recht hungrig wird. Die billigen Dinger liefern aber meist nur 1A.

Besonders aus Platzgründen habe ich mich für die flachen Akkus mit selbst gebauter Lade- und StepUp-Kombination entschieden, zumindest was meine ersten Nokos mit TDA7052a und nur einem Lautsprecher betrifft, der auch mit 5V gut klang.

Crayfish68, 2017-12-16:
Noch ein kleiner Nachtrag zu der Leiterplatte und den 5V: ich habe jetzt einen NOKO mit 5V gebaut, es scheint zu funktionieren, klingt alles sauber, keine Störungen zu hören. Das dürfte natürlich auch die Laufzeit des NOKO deutlich verlängern. Dazu einfach:

 * den StepUp Wandler auf 5V regeln
 * C2, C3 und C4 weglassen
 * 5V Regler weglassen
 * Löcher für Pin 1 und 3 des 5V Reglers verbinden.

Sieht dann ungefähr so aus:

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

![bildschirmfoto vom 2017-12-16
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

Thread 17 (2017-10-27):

Obere Leiterplatte Lautsprecher Anschlüsse

Crayfish68, 2017-10-27:
Hallo Nikolai

Noch eine Detailfrage:

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

(das ist hier:  https://camo.githubusercontent.com/beaceb80ccfa7fbee1aa4dac055786602f59c68a/687474703a2f2f7777772e6e696b6f6c61697261646b652e64652f4e4f4b4f2f4e4f4b4f5f6c61796f75745f7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)

Hier sind zwischen dem HC-SR04 und dem Wannenstecker zwei Leiterbahnen _nicht_ getrennt (M und N). Allerdings liegen da bei mir jetzt Echo und Trigger vom HC-SR04 drauf (an den 4 Pins habe ich den Sonsor sozusagen befestig), so habe ich es verstanden. Das war dann aber gar nicht so gemeint, oder? Denn an den beiden Pins des Wannensteckers werden ja dann R- und L+ (von den Lautsprechern).

Also, doch trennen, richtig?

vG
Thomas
PS: das war doch bestimmt mal so gedacht, das Echo und Tigger direkt zum Wannenstecker runtergezogen werden und R+- und L+- über andere SteckerPins zur Hauptplatine gehen ... aber dann hat Noko geniest?

NikolaiRadke, 2017-10-31:
Hallo Thomas!

Ich habe gerade schrecklich viel zu tun, aber ich werde wohl heute Abend dazu kommen, Deine Fragen zu beantworten.

Liebe Grüße,

Nikolai

NikolaiRadke, 2017-10-31:
Au backe.
Da habe ich aber einen dummen Fehler gemacht, Ich befürchte ich habe da sogar mal verschlimmbessert. Ja, der Stecker ist verrutscht. Ich muss wohl alle Grafiken neu erstellen...

Danke für den Hinweis!!

Crayfish68, 2017-10-31:
Mh, 'Stecker verrutscht' kann, wenn ich das alles richtig sehe, eigentlich nicht sein, denn die Anschlüsse (+, -, SCL, SDA, A0, ...) stimmen ansonsten mit der Belegung von S1 auf der Hauptplatine überein ... auch die Lautsprecher. Aus meiner Sicht sollte eine Trennung der Leiterbahnen hier reichen.

vG
Thomas

Es sei denn, ich sehe hier irgend etwas anderes nicht...

vG
Thomas

NikolaiRadke, 2017-10-31:
Es war mal angedacht, Trigger und Echo direkt hinzuführen, aber dann habe ich beim Bauen einen Fehler gemacht. Bis das Wiki überarbeitet ist, mache einfach die Unterbrechnungsline unter dem Sensor durchgängig. Ich habe die restliche Verdrahtung im Wiki angeschaut, die müsste so eigentlich funktionieren.

NikolaiRadke, 2017-10-31:
ARGH! Da warst Du 3 Sekunden schneller :-D

Crayfish68, 2017-10-31:
Gut, jetzt poltert mir grad ein riesiger Brocken vom Herzen, sollte eigentlich in ganz Berlin zu hören gewesen sein ;)  Und das an Halloween!

Dann werde ich mich mal weiter durchkämpfen.

:)

vG
Thomas

NikolaiRadke, 2017-10-31:
Ja, habe ich hier in Weißensee auch gehört. Dachte, es war ein Böller.
Viel Erfolg weiterhin!

Das Issue bleibt erstmal offen, bis die Grafiken korrigiert sind.

NikolaiRadke, 2017-11-11:
Ist korrigiert!

Closed 2017-11-11.

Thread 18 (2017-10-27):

A0 auf der oberen Platine

Crayfish68, 2017-10-27:
Hi Nikolai

Hier nochwas gefunden: auf der oberen Platine ist (mit 'hellbgrünem' Kabel) der A0-Anschluss vom Wannenstecker zu Spalte R / Reihe O, gezogen. Dann müsste aber noch eine Brücke zu den Widerständen gelegt werden (Reihe S), oder das Kabel direkt in die Reihe S ziehen (auf der Leiterseite dann).

Richtig?

vG
Thomas

Crayfish68, 2017-10-27:
Sorry, die Brücke ist ja drin, alles gut!

Closed 2017-10-27.

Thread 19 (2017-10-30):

Hauptplatine im Wiki

Crayfish68, 2017-10-30:
Und nochwas:

Im Wiki auf der Seite "Hauptplatine" scheint irgendwas nicht zu stimmen. Von unten sieht es so aus:

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

Von oben sieht es so aus:

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

Also, müssen da jetzt 3 oder nur 2 Leiterbahnen getrennt werden?

vG
Thomas

NikolaiRadke, 2017-10-31:
Auch hier ein dickes Danke, die Unterbrechung ist eigentlich überflüssig, sofern die Verbindung in der Grafik bei 4_1 Stromversorgung zwischen VIN+ des MP3608 und BAT+ vom TP4056 um eins nach unten versetzt wird. Die Grafik werde ich gleich korrigieren.

NikolaiRadke, 2017-10-31:
Nein, ich habe mich entschieden, die Unterbrechung in der oberen Grafik einzufügen. Das ist einfacher, als alle anderen Grafiken neu zu bearbeiten...

Crayfish68, 2017-10-31:
Ok, das ist für mich auch einfacher, ich hatte es schon unterbrochen und dann wieder gebrückt. Ich nehme die Brücke jetzt einfach raus.

vG
Thomas

NikolaiRadke, 2017-10-31:
Prima. Freut mich.
Ein schönes Gefühl, ein Issue zu schließen :-)

Closed 2017-10-31.

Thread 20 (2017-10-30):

Radio Antenne

Crayfish68, 2017-10-30:
Hi Nikolai

Sorry, ich arbeite mich durch und dann kommen die Fragen so dahergetrödelt. Zum Radio: du sagst unter "4.3 Verstärker", dass die Antenne an den Pin zwischen den beiden Kanälen angeschlossen wird. Damit meinst du diesen Pin hier?

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

das mit der Unterbrechung zwischen L1 und C5 wird spaßig - ich sollte mir ein Mikroskop zulegen!

vG
Thomas

NikolaiRadke, 2017-10-31:
Lieber Thomas,

die Dokumentation im Wiki ist in der Tat da etwas... defizitär, das werde ich ergänzen.
Ja, die Antenne soll an genau diesen Pin. Die Wurfantenne soll 1/4 von 3m = 0,75m lang sein.

Die Unterbrechung trennt einen Eingangsfilter aus Kondensator und Spule. Dadurch verbessert sich der Empfang. Das geht ganz gut mit einem Skalpell oder etwas brachialer mit einem Teppichmesser. Wenn das zu fummelig ist, kann der Filter auch drin bleiben.

Crayfish68, 2017-11-01:
Hi Nikolai

Das ist ja dann doch leichter gewesen, als ich gedacht habe. Der Tip mit dem Skalpell ist Gold wert! Manchmal kommt man einfach nicht auf die einfachsten Sachen.

Leider habe ich zu dem Radio-Modul keinen Schaltplan/Bestückungsplan gefunden, könnte mir denken, dass es auch reicht entweder L1 oder C5 zu entfernen?

Im Wiki würde es ausreichen, wenn du das Bild von mir oben einfügst, ich denke, dann ist es klar. Der Antennenanschluss war wirklich das einzige, was etwas unklar war. Hiermit übertrage ich dir vollständig und unwiderruflich die Rechte an dem Bild oben! ;)

vG
Thomas

NikolaiRadke, 2017-11-11:
Ich habe dann aus Konsistenzgründen eine Grafik mit einem grünen Modul erstellt. Wiki ist ergänzt. Danke für den Hinweis!

Closed 2017-11-11.

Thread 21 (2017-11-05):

NOKO bleibt stumm?

Crayfish68, 2017-11-05:
Hallo Nikolai

Ich brauche noch einmal moralische Unterstützung! Und Hilfe! Nachdem ich mich jetzt durch die Audio-Verbindungen (Teil 4.3: Verstärker) gekämpft habe, wäre mein erster NOKO eigentlich fertig - nur bleibt er leider stumm. Kein Pieps. Momentan stehe ich ein bisschen auf dem Schlauch, warum das sein könnte. Wenn ich in das Menü -> Noko stellen -> weiter... gehe, und dort versuche das "Stumm [X]" zu deaktivieren (so, dass er eben _nicht_ mehr stumm ist), dann überlegt er 2 Sekunden und dann kommt das X wieder. Ich kann grad den Fehler nicht sehen - hättest du einen Tipp für mich?

Im I2C Bus sieht Noko alles, was er soll (x10x3Fx50x57x68), Spannungen (6.5V) sind da, hab jetzt grad keine Idee mehr, was ich noch falsch gemacht haben könnte. Übersehe ich irgendetwas an der Bedienung?

vG
Thomas

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

NikolaiRadke, 2017-11-06:
Hallo Thomas!
Morgen Abend schaue ich mir das mal in Ruhe an. Komisch.

Crayfish68, 2017-11-07:
Jetzt ist bei mir auch Winter ;)

Einen Fehler in der Verdrahtung habe ich grad noch gefunden: das MOSFET Gate ging an D8 und nicht D6. Das habe ich jetzt berichtigt, aber trotzdem geht es (noch) nicht, selbes Fehlerbild. (https://photos.app.goo.gl/k7eFVjTP8my8jkH93)

Mir ist aber auch grad noch aufgefallen(!), dass ich die USB Verbindungen zum MP3 Modul und Arduino noch nicht dran habe! Ich dachte, die brauche nur zum Anschluss an den PC nachher. Kann es sein, dass der Arduino und das MP3-Module darüber ihre Versorgungsspannung bekommen, zumindest solange der Potischalter aus ist? Ich hätte jetzt angenommen, die kämen über den 5V Bus über StepUp Wandler und dann 5V Regler - aber die sind ja dann aus!? Die Seite 3 des Schaltplanes hat mich da reingelegt, da ist nämlich rehts (Arduino und MP3 USB) nur D+ und D-.
Trotzdem, wenn ich den Potischalter einschalte ... _sollte_ es ja gehen. Ich vermute, das irgendetwas immer noch nicht stimmt.

Nunja, ich wollte Geld sparen, die USB-Selbstlöt-Stecker sind noch auf dem Weg aus Fernost, hier im Abendland kosten die (konfektionierten) ein Vermögen (4€/Stck vs. 1€/10Stck), aber ich bestelle dann mal 2 bei Reichelt, brauche eh noch Zeugs.

vG
Thomas

NikolaiRadke, 2017-11-08:
Lieber Thomas,

das sich "Stumm" nicht ausstellen lässt, ist schon sehr komisch, da dieser Zusand nur über dieses Menü geschaltet werden kann. Wenn Stumm, also die Variable quiet=true ist, müsste NOKO ein großes S im Display neben der Uhrzeit haben.

Ersetze doch mal bitte in Zeite 283 "quiet=read_EEPROM(1);" durch "quiet=false;". Dann miss mal D6 bzw. das MOSFET-Gate. Beim Einschalten muss NOKO zwei Töne von sich geben und dabei D6 auf LOW ziehen. Ist der Verstärker aus, ist D6 HIGH.

NOKO bezieht seinen Strom ausschließlich über den Akku. Ich habe sowohl beim MP3-Modul als auch beim Arduino nur die Datenleitungen D+ und D- des Hubs verlötet. Die Versorgung der beiden kommt, wie vermutet, über die 5V des Regulators. Somit ist NOKO nicht in einem schrecklichen Dämmerzustand, wenn Der Akku geladen wird. Die USB-Verbindungen werden aber im Betrieb nicht benötigt. Die kommen nur zum Einsatz, wenn NOKO an den Computer angeschlossen wird, um eine neue Software auzuspielen oder die SD-Karte des MP3-Moduls zu beschreiben.

Die Winkelstecker kosten hier schrecklich viel Geld, ich weiß. Wären da nicht private und berufliche Pflichten, würde ich NOKO-Teile im eigenen Shop für kleines Geld anbieten. Oh grausames Schicksal.

Dran bleiben!

Viele Grüße,
Nikolai

Crayfish68, 2017-11-14:
Hallo Nikolai

Ich habe jetzt ein paar Tage probiert, ich komme derzeit einfach nicht weiter. Es ist ein Hardware Problem an der oberen Leiterplatte. Nach dem Herausnehmen dieser Platine (aus der Befestigung), ging es plötzlich – aber nur ganz kurz. Wenn ich sie jetzt wieder einsetze und mit dem Kabel (S1) verbinde, dann brechen meine 5V plötzlich ein. Manchmal. Wenn ich sie dann nochmal herausnehme und wieder einsetze, geht es (ohne Ton). Dann wieder nicht. ... Irgendwo ist noch ein Wackler oder eine Brücke, aber es ist sehr schwierig zu finden. Das Einfachste wäre wohl, diese Platine noch einmal zu machen, jetzt weiß ich ja wie es geht ;)

Aber, ich denke, ich warte aber jetzt erst einmal auf meine Leiterplatten aus China. Sie sollten nächste Woche ankommen, wenn alles gut geht. Ich denke, dass ich damit insgesamt besser fahre. Durch-testen und bauen muss ich die dann sowieso, insgesamt denke ich, wird das der einfachere Weg sein. Also, mach hier ersteinmal zu, der Fehler liegt so oder so bei mir.

Mhmpf :/

vG
Crayfish

Closed 2017-11-29.

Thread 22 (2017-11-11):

SDL vs. SCL

Crayfish68, 2017-11-11:
Weil du grad am ändern bist, hier noch ein ganz, ganz, ganz, ganz kleiner Typo für dich: auf diesem Link (https://github.com/NikolaiRadke/NOKO/blob/master/schematics/NOKO_layout_up_data.png) steht S_D_L, an Stelle von S_C_L!

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

vG
Thomas
PS: Leiterplatte kommt, habe noch einige Verbesserungen eingebaut...

NikolaiRadke, 2017-11-12:
Ist korrigiert!

Closed 2017-11-12.

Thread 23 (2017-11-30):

NOKO Gehäuse

Crayfish68, 2017-11-30:
Hallo

Ich habe vor Monaten ein passendes Gehäuse für NOKO bei W**lw*rth gefunden. Ich glaube, es handelte sich um den Vorgänger von dieser Snackbox hier:

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
(Snackbox flach 387208)

Die EAN Nummer auf meiner Box ist 387900

Allerdings bekomme ich es nirgendwo mehr. In allen 1€ Shops gibt es dieselben Boxen, die ich derzeit habe, sind mir eigentlich locker 1cm zu dick. Die, die flach genug wären, sind zu klein, da passt z.B. das LCD Display nicht rein. Das o.g. gefällt mir noch am ehesten.

Hat jemand entweder einen Tip, wo ich die finden kann oder eine andere Idee für ein passendes Gehäuse? Ich habe auch grad den Hersteller angeschrieben, vielleicht wird mir ja geantwortet, wo ich diese käuflich erwerben kann. Bei Erfolg sage ich Bescheid.

Danke
vG
Crayfish

NikolaiRadke, 2017-11-30:
Ja, die kommt mir bekannt vor...
Da hast Du doch glatt meinen nächsten Aufruf vorweg genommen: Ein passendes 3D-gedrucktes Gehäuse, in das die Module ohne bohren und sägen eingelassen werden können.

Die Dosen habe ich damals aus Tedox rausgeholt. Oder war es Poco?

andy5macht, 2017-11-30:
Ich habe Zugriff auf einen 3D-Drucker. Nur im Konstruieren bin ich kein Profi. Wenn ich die ganze Hardware zusammen habe werde ich mich nach den Abmaßen bemühen. (oder hat da jemand schon die nötigen Daten?)
Und dann ein einfaches Gehäuse konstruieren.

Crayfish68, 2017-12-04:
Der Hersteller hat mir tatsächlich geantwortet, womit ich im Leben nicht gerechnet hätte. Diese Boxen gibt es bei Kaufland derzeit - sie hat mich auch auf eine Lidl Aktion im Januar hingewiesen ;)

Nikolai, wie ist denn deine Meinung zu diesen Boxen?
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

Die sind nochmal deutlich kleiner (ca. 16cm x 11cm x 4cm). Die Leiterplatte würde ich auf die Größe bekommen (ca. 8cm x 13cm), sofern ich den 5V Regelkreis rauslassen kann (Regler + 3 Elkos). Das Display, Sensor, Lautsprecher müssten dann in den Boden, die Leiterplatte in den Deckel. Ich bin mir nicht so ganz sicher, ob das passt, könnte aber eine gute Idee sein? Die 4cm Höhe wären das Mindestmaß, rein rechnerisch. Vielleicht schaust du dir das mal an, falls nicht schon geschehen.

Ja, oder halt 3D-Druck ... *träum*

Crayfish

NikolaiRadke, 2017-12-06:
Diese Dose habe ich auch hier rumliegen, allerdings war sie mir zu hoch und nicht breit genug.
Aber sehr großartig ist, dass Du eine Antwort bekommen hast!!

So eine in Lila hast Du doch für Deinen platinenlosen NOKO verwendet?
Bei dem weißen Gehäuse gefällt mir die Anordnung nicht, da ich bei mir sehr viel wert auf NOKOs Äußeres lege und dort die Schnittvorlage nicht funktioniert. Aber gegen Eigenkreativität ist natütlich nichts einzuwenden :-)

Ich schaue mich auch nochmal nach geeignete Dosen um.

Crayfish68, 2017-12-07:
Sorry, ich hätte etwas klarer sein sollen. Noch einmal von vorn:

Ich habe derzeit 3 verschieden Boxen hier:
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
Von links nach rechts:
* Links ist die weiße (eigentlich hell-türkis), in der ich meinen ersten NOKO mit Leiterplatte verbaut habe. Die ist allerdings mit 5cm mir persönlich zu dick.
* In der Mitte ist die von dir ursprünglich vorgeschlagene Box in der ich meine aller ersten NOKO - in lila - verbaut hatte. Die Außenmaße sind 18,5cm x 14cm x 4cm. Damit baue ich jetzt meine 5 NOKOs fertig, soweit klar.
* Rechts ist jetzt eine deutlich kleinere Snackbox. Die Außenmaße sind da 16cm x 11cm x 4cm. Die gibt es derzeit in jedem, gut sortierten Fach-Euro-Shop. Der direkte Vergleich zeigt es besser:

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
Die Frage ist jetzt, aus deiner NOKO Bauerfahrung, würde das Display, Lautsprecher und Ultraschall-Sensor in die kleinere Box passen? Ich selbst denke es passt. Ganz knapp zwar, aber passt.

Die Leiterplatte bringe ich auf die entsprechende Größe in der nächsten Version. Ist eigentlich schon zu 90% fertig. Ich hoffe, der 5V Regler kann draußen bleiben, ich werde das mit dem nächsten mal testen (kann ich ja einfach weglassen und überbrücken, auch auf der derzeitigen Platine).

Und ja, ich habe mich mit den neuen Boxen jetzt etwas näher an deiner Orginalvorlage orientiert. Die weiße gefällt mir so wie sie ist/war auch nicht.

viele Grüße
Crayfish

PS: haben wir eigentlich grad eine Diskussion um Brotboxen?

NikolaiRadke, 2017-12-12:
Hmm... Beim Entwurf ging es eigentlich nur darum, Alle Bauteile auf der Platine unterzubringen. Bei meiner wilden Verdrahtung kam ich auf die Maße der Platine und habe dann entsprechend nach passenden Dosen gesucht. Probier es doch mal aus - allerdings passt das Schnittmuster nicht mehr richtig, das müsste etwas verkleinert werden, was ja nicht schlecht wäre.

Ja, wir reden über Brotdosen, genau genommen 1€-Brotdosen :-D
Und manche Leute nehmen sogar mit den Herstellern Kontakt auf!

Closed 2018-03-03.

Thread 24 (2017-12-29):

USB Hub

bencha, 2017-12-29:
Hallo Zusammen,

da ich gerade am Basteln bin und zum Glück schon die einfache Version und zwar das Board von Crayfish68 verwende, ist mir trotzdem das USB Hub ein Dorn im Auge und ich bin auf die Suche gegangen.
Dabei habe ich heute das folgende Nano USB Hub mit 2 Ports auf tindie.com gefunden.
Ob es was taugt, weiß ich leider noch nicht oder vielleicht ist jemand gerade auf der Suche nach einem USB Hub und möchte dieses mal testen. :-)
Leider ist es auch deutlich teurer, als alle anderen. :-(

https://www.tindie.com/products/mux/nanohub-tiny-usb-hub-for-hacking-projects/

@crayfish68: Wenn das USB Hub etwas taugt, dann könnte das eventuell mit in das PCB Board eingeplant werden, oder?

Grüße
Benjamin

@NikolaiRadke: Ich habe gesehen, Du hast auch ein neues Board in Verwendung. Kannst Du uns mal eine Beschreibung oder ein Link dazu hinterlassen?

NikolaiRadke, 2017-12-30:
Der Hub ist prima, mir persönlich allerdings zu teuer.
Ich werde ihn im künftigen PCB-Wiki jedoch gerne als Alternative aufnehmen (und mir heimlich doch einen kaufen ;-) ).

Ich habe ein neues Board? Ich verwende das, das ich von Crayfish68 zugeschickt bekommen habe...

bencha, 2017-12-30:
Mit "neues Board" meinte ich das USB Hub, dass Du auf crayfishs Platine verwendet hast.

NikolaiRadke, 2017-12-30:
Achso. Das teste ich gerade, gibt es ab 2,70€. Ich bin mir noch nicht sicher, ob das Schrumpfschlauchgefummel nerviger ist, oder das Büchsenauslöten,

https://de.aliexpress.com/item/DC-5-V-USB-Hub-USB2-0-Hub-4-Female-Hub-USB-Expansion-Board-Modul/32845109447.html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

Oder auch in der Buch nach "USB Hub Board" suchen.

Crayfish68, 2017-12-30:
Den Nano-USB-Hub finde ich schon genial - allerdings (genau wie Nikolai) deutlich zu teuer. Ich komme beim NOKO auf Gesamtkosten von etwa 100€ - 120€ (auch stark abhängig davon, ob man schon Bastler ist, sprich Kabel hat, Crimpzange, Löt-Zubehör, Schrauben, etc.).
Wenn jetzt nur der USB Hub davon schon 10% einnimmt, ist das in Relation zu viel.

Ich hatte auch mal nach USB Chips (ICs) geschaut. Aber man kommt erstens nicht auf den Preis von 2€ bis 3€, dann braucht es immer noch Außenbeschaltung und es sind SMD Packages, die nicht einfach zu löten sind.

Meine Erfahrung mit dem Micro USB Hub, der im Wiki steht: man sollte die schwarze Isolierung der Anschlüsse so dicht am Gehäuse wie möglich abisolieren/entfernen (wenn das jetzt Sinn mach). Dann etwas Muße nehmen zum schrumpfen und es passt. Ich habe ihn am Ende dann eher so schräg (45°) reingesetzt (siehe auch Bild im anderen Issue).

Ich habe mir noch so paar der kleineren Micro USB Hubs mit 2 Ports bestellt, die sollten auf dem Weg sein. Ich werde mal einen aufknacken, vielleicht kann man das Innere einfach(er) auf das Board bringen?

Crayfish

Crayfish68, 2018-01-10:
Es gibt Neuigkeiten:

Bei mir sind grad die kleinen 2-Port-USB-Hubs aus Xingyuan (North) angekommen. Ich würde mal fast ganz doll stark dafür plädieren. Hier mal ein Foto:

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

Man kann die ganz easy aufknacken, einfach mit einem Seitenschneider vorsichtig an einer Ecke, wahrscheinlich kann man sie mit etwas mehr Geschick als ich auch einfach aufhebeln. Von Innen sieht es dann so aus:

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

Die Platine ist 18,3mm x 21,8mm groß. Da kann man ohne Probleme die +/-/D+/D- jeweils ein kurzes Kabel anlöten und dann auf die Leiterplatte verbinden. Da würde ich dann entsprechend den passenden Footprint für anlegen.
Als einziger USB Anschluss, der dann händisch zu machen wäre, bliebe dann der Arduino. Wenn ich den auf der Leiterplatte drehe, dann bräuchte es noch nicht mal einen gewinkelten Stecker, sondern man kann einen beliebigen (graden) nehmen. Ist günstiger und einfacher zu bekommen.

Mit dieser Platine traue ich mir auch ganz locker zu, die Platine auf die Größe von 80x130mm zu bekommen, oder noch kleiner. Kleiner kann ja nicht schaden. Vielleicht 80x100mm, dann kosten sie fast nichts mehr.

Was meint ihr? Ich habe ein paar mehr bestellt (ausversehen), wenn ihr also einen zur Ansicht haben wollt - also @NikolaiRadke und @bencha jetzt :) - kann ich jeweils einen in einen Brief stecken und zu euch schicken, dann könnt ihr euch selbst ein Bild machen.

vG
Crayfish

NikolaiRadke, 2018-01-10:
Das ist so ziemlich genau das, was ich seit drei Jahren suche!
Sehr schön. Über Post würde ich mich freuen und den Hub dann um Wiki übernehmen.

jlegen, 2018-01-23:
Ali, Suche nach "2 Port Hub", erste Seite:
https://de.aliexpress.com/item/Hot-New-Design-High-Quality-Portable-USB-3-1-Type-C-USB-C-To-Dual-2/32804431620.html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

sieht zumindest sehr ähnlich aus, Order läuft... :-)

Crayfish68, 2018-01-23:
Das wird derselbe sein. Ich hatte bei eBay (China) bestellt: https://www.ebay.de/itm/Micro-USB-Stecker-OTG-Hub-f%C3%BCr-Smartphone-Handy-Tablets-On-The-Go-Adapter-Kabel/162650973982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

Hat den eigentlich schon jemand von euch probiert? Ober der was taugt in dem Zusammenhang? Na, das wär's jetzt der Brüller ... :/

NikolaiRadke, 2018-01-23:
Ali und ich werden keine Freunde. Ich habe dort zweimal was bestellt, beide Male ist nichts angekommen. Ich bin wohl der einzige weit und breit, aber jetzt ein gebranntes Kind :-)

Closed 2018-03-05.

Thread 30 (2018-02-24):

Hinweise zu 2.0

NikolaiRadke, 2018-02-24:
Liebe NOKO-Freunde, ab Firmware 2.0-240218 werden die Hörspiel-Informationen im 24LC256 gespeichert, da dort noch über 16kByte Platz waren. Jetzt können rund 400 Hörspiele gespeichert werden. Wem das immer noch nicht reicht, kann ein 24LC512 nehmen - dann ist noch mehr Platz. Da Interface ist jedoch auf 999 begrenzt.

Die Informationen werden in der Datei EEPROM gespeichert, früher Disk1. Im Grunde habe ich Disk0 und Disk1 nur zusammen geführt, um einen Vorgang zu sparen. Dafür müssen nun kein Spiellängen mehr händisch eingetippt werden.

Vorgehensweise:
1. EEPROM in /write_eeprom/V20 anpassen/ergänzen.
2. NOKO_Settings.ino anpassen.
3. NOKO_Settings.ino auf den Arduino laden. Kurz warten.
4. NOKO_EEPROM.ino auf den Arduino laden.
5. Je nach Betriebssystem write_eeprom bzw. write_eeprom.exe mit den Parametern aus dem README starten.

Bei 40 Hörspielen und den 20k NOKO-Unsinn dauert das Beschreiben 18 Minuten. Zeit für Kaffee oder Bier oder die Lieben dabeim.

NikolaiRadke, 2018-02-25:
*Was ist zu beachten?*

* Die Platine läuft mit 5V, benötigt also **keinen Regulator** (L4940V5).
* Das Radio wird als kleinere Ausführung benötigt, also anstelle der grünen Version eine *lila* Platine nehmen.
* Als Lademodul wird nun ein *TP4065 Protect* verwendet, also ein Modul mit zusätzlichem Entladeschutz. Der ist nicht unbedingt notwendig, aber kostet genau so viel bzw. so wenig. Erkennbar an den sechs anstelle von vier Anschlüssen.

jlegen, 2018-11-12:
Hi, da ich beim V2-Befüllen der EEPROMS irgendwie mehrere Anläufe brauchte, hat es mich etwas gestört, dass man "nix sieht" beim 'Rüberschaufeln. Daher habe ich das "write_eeprom.c" leicht modifiziert, sodass ein Zähler den Fortschritt ausgibt:

```
#include <stdio.h>

int main()
{
   int c;
   long j=0;
   long k;
   FILE *datei;
   usleep(5000000);
   datei=fopen("EEPROM","r");
   if(datei != NULL)
      {
		 fseek(datei, 0L, SEEK_END);
		 k = ftell(datei);
		 rewind(datei);
         while((c=fgetc(datei))!= EOF)
		 {
			fprintf(stderr, "Bytes written: %d/%d\r", j, k);
			fflush(stderr);
            putchar(c);
			fflush(stdout);
			usleep(50000);
			j++;
		 }
      }
   else
      printf("Konnte Datei nicht finden bzw. oeffnen!\n");
 return 0;
}
```
[write_eeprom2.zip](https://github.com/NikolaiRadke/NOKO/files/2572041/write_eeprom2.zip)

Ausserdem fand' ich's beim "NOKO_Diagnostics.ino" leicht ungünstig, dass das "Menü" nach einem Aufruf immer 2x durchrauschte, sodass man sich das Ergebnis des letzten Tests immer erst erscrollen musste.
Ein
```
  while(Serial.available()) {
    Serial.read();
    };

```
Am Ende des loops() hat das behoben...

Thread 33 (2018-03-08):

EEPROM beschreiben unter Windows 10

NikolaiRadke, 2018-03-08:
Nachdem vor einigen Monaten mit Einstellen der Baud-Rate auf 115200 alles lauffähig schien, gelingt es mir und anderen nun nicht mehr unter (Ich hasse) Windows 10 das EEPROM zu beschreiben. Die LED blinkt frenetisch, aber das EEPROM bleibt leer.

Die Eingabeaufforderung habe ich mit Admin-Rechten gestartet.

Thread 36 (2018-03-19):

Domain

Crayfish68, 2018-03-19:
Nikolai

Kein Issue mit NOKO, aber irgendwie doch: deine Domain ist auf Bewährung ("REDEMPTION PERIOD") und du bist dadurch nicht kontaktierbar!

Rechnungen bezahlt?

vG
Crayfish

Closed 2018-03-19.

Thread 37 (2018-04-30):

No need to wait after Wire.requestFrom().

Koepel, 2018-04-30:
In some files, there is a `while(Wire.available()` after the Wire.requestFrom(). All of those can be removed.
Explanation: [Common-mistakes#1](https://github.com/Koepel/How-to-use-the-Arduino-Wire-library/wiki/Common-mistakes#1)

I noticed them in the files:
- NOKO/src/V10/tools/NOKO_Diagnostics/NOKO_Diagnostics.ino
- NOKO/src/V20/tools/NOKO_Diagnostics/NOKO_Diagnostics.ino
- NOKO/src/V10/English/NOKO/Si4703.cpp
- NOKO/src/V10/Deutsch/NOKO/Si4703.cpp
- NOKO/src/V20/English/NOKO/Si4703.cpp
- NOKO/src/V20/Deutsch/NOKO/Si4703.cpp

NikolaiRadke, 2018-04-30:
Thanks for the advice.
I removed the obsolete code and checked the other common mistakes mentioned in your link!

NikolaiRadke, 2018-04-30:
No, i am not only checking the common mistakes, i am reading your complete wiki.
Very handy!

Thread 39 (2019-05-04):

Wie schliesse ich den USB-Hub auf der Platine 2.0 an?

GhostGirl16, 2019-05-04:
Hallo,
auf meinem Noko (Platine 2.0) muss nun der USB-Hub eingelötet werden.
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

Welcher Pin des USB-Hubs muss mit welchem Pin der Platine zusammen gelötet werden? In den anderen Threads ist nicht immer ganz klar wer welche Platinen Version verwendet, weshalb ich nun etwas verwirrt bin.
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

Danke für Eure Unterstützung
Natalie

NikolaiRadke, 2019-05-06:
Hallo Natalie,

mit dieser Platinenversion ist die Pin-Belegung korrigiert worden. 5V an 5V DP an D+, DM an D-, GND an GND. Alles, wie es sein soll.

Naja, fast. Dieser Hub macht leider Probleme. Bei einem Noko funktioniert er, bei etlichen anderen nicht. Daher empfehle ich den etwas größeren Hub aus NOKO 1, auch wenn der nicht auf die Platine gelötet werden kann.

 Probiere es aus, in der Software gibt es unter NOKO stellen den Menüpunkt Equalizer und Upload, dann könnte es möglich sein, da so keine Steuersignale an des Modul gesendet werden. Konnte ich bisher jedoch nicht testen.

Dran bleiben, das sieht ja alles schon ganz toll aus!

Liebe Grüße,

Nikolai

GhostGirl16, 2019-05-08:
Vielen Dank für die Antwort. Ich werde es gerne ausprobieren.

Closed 2019-05-08.

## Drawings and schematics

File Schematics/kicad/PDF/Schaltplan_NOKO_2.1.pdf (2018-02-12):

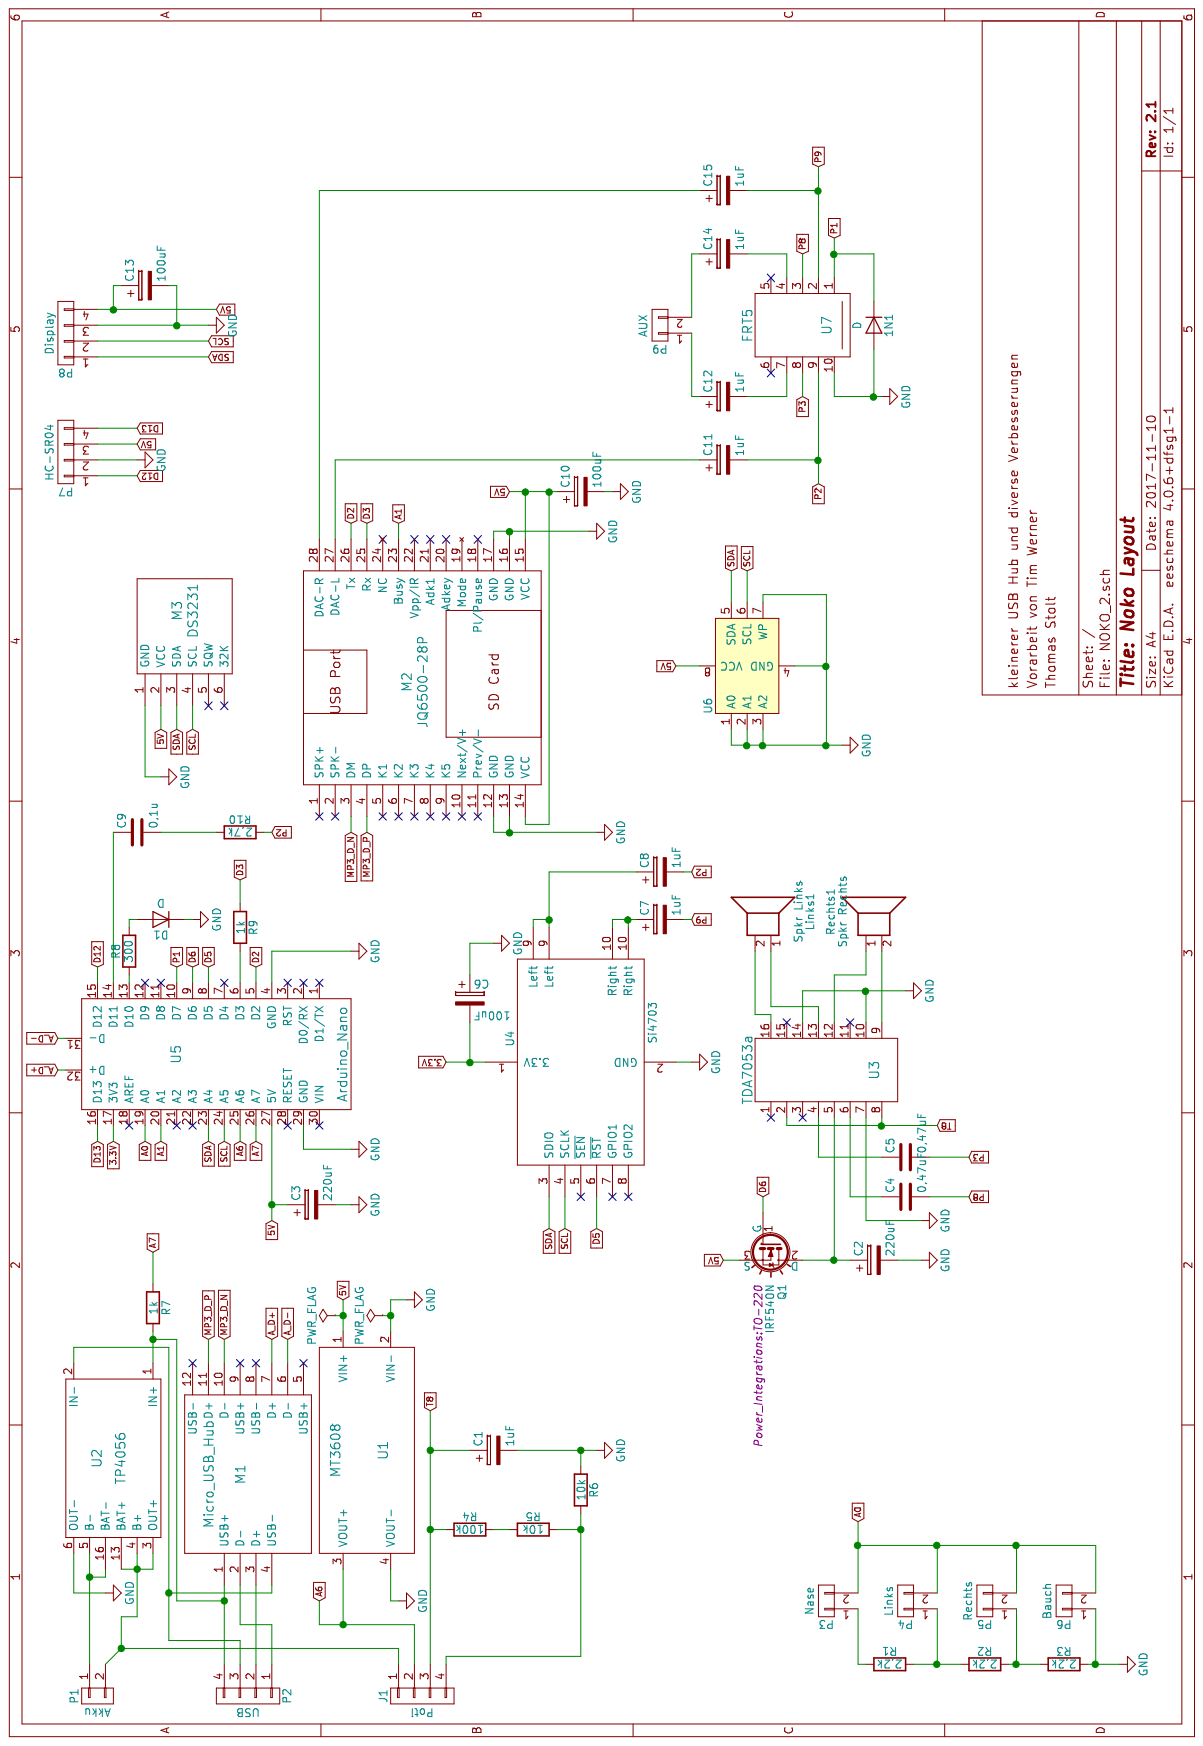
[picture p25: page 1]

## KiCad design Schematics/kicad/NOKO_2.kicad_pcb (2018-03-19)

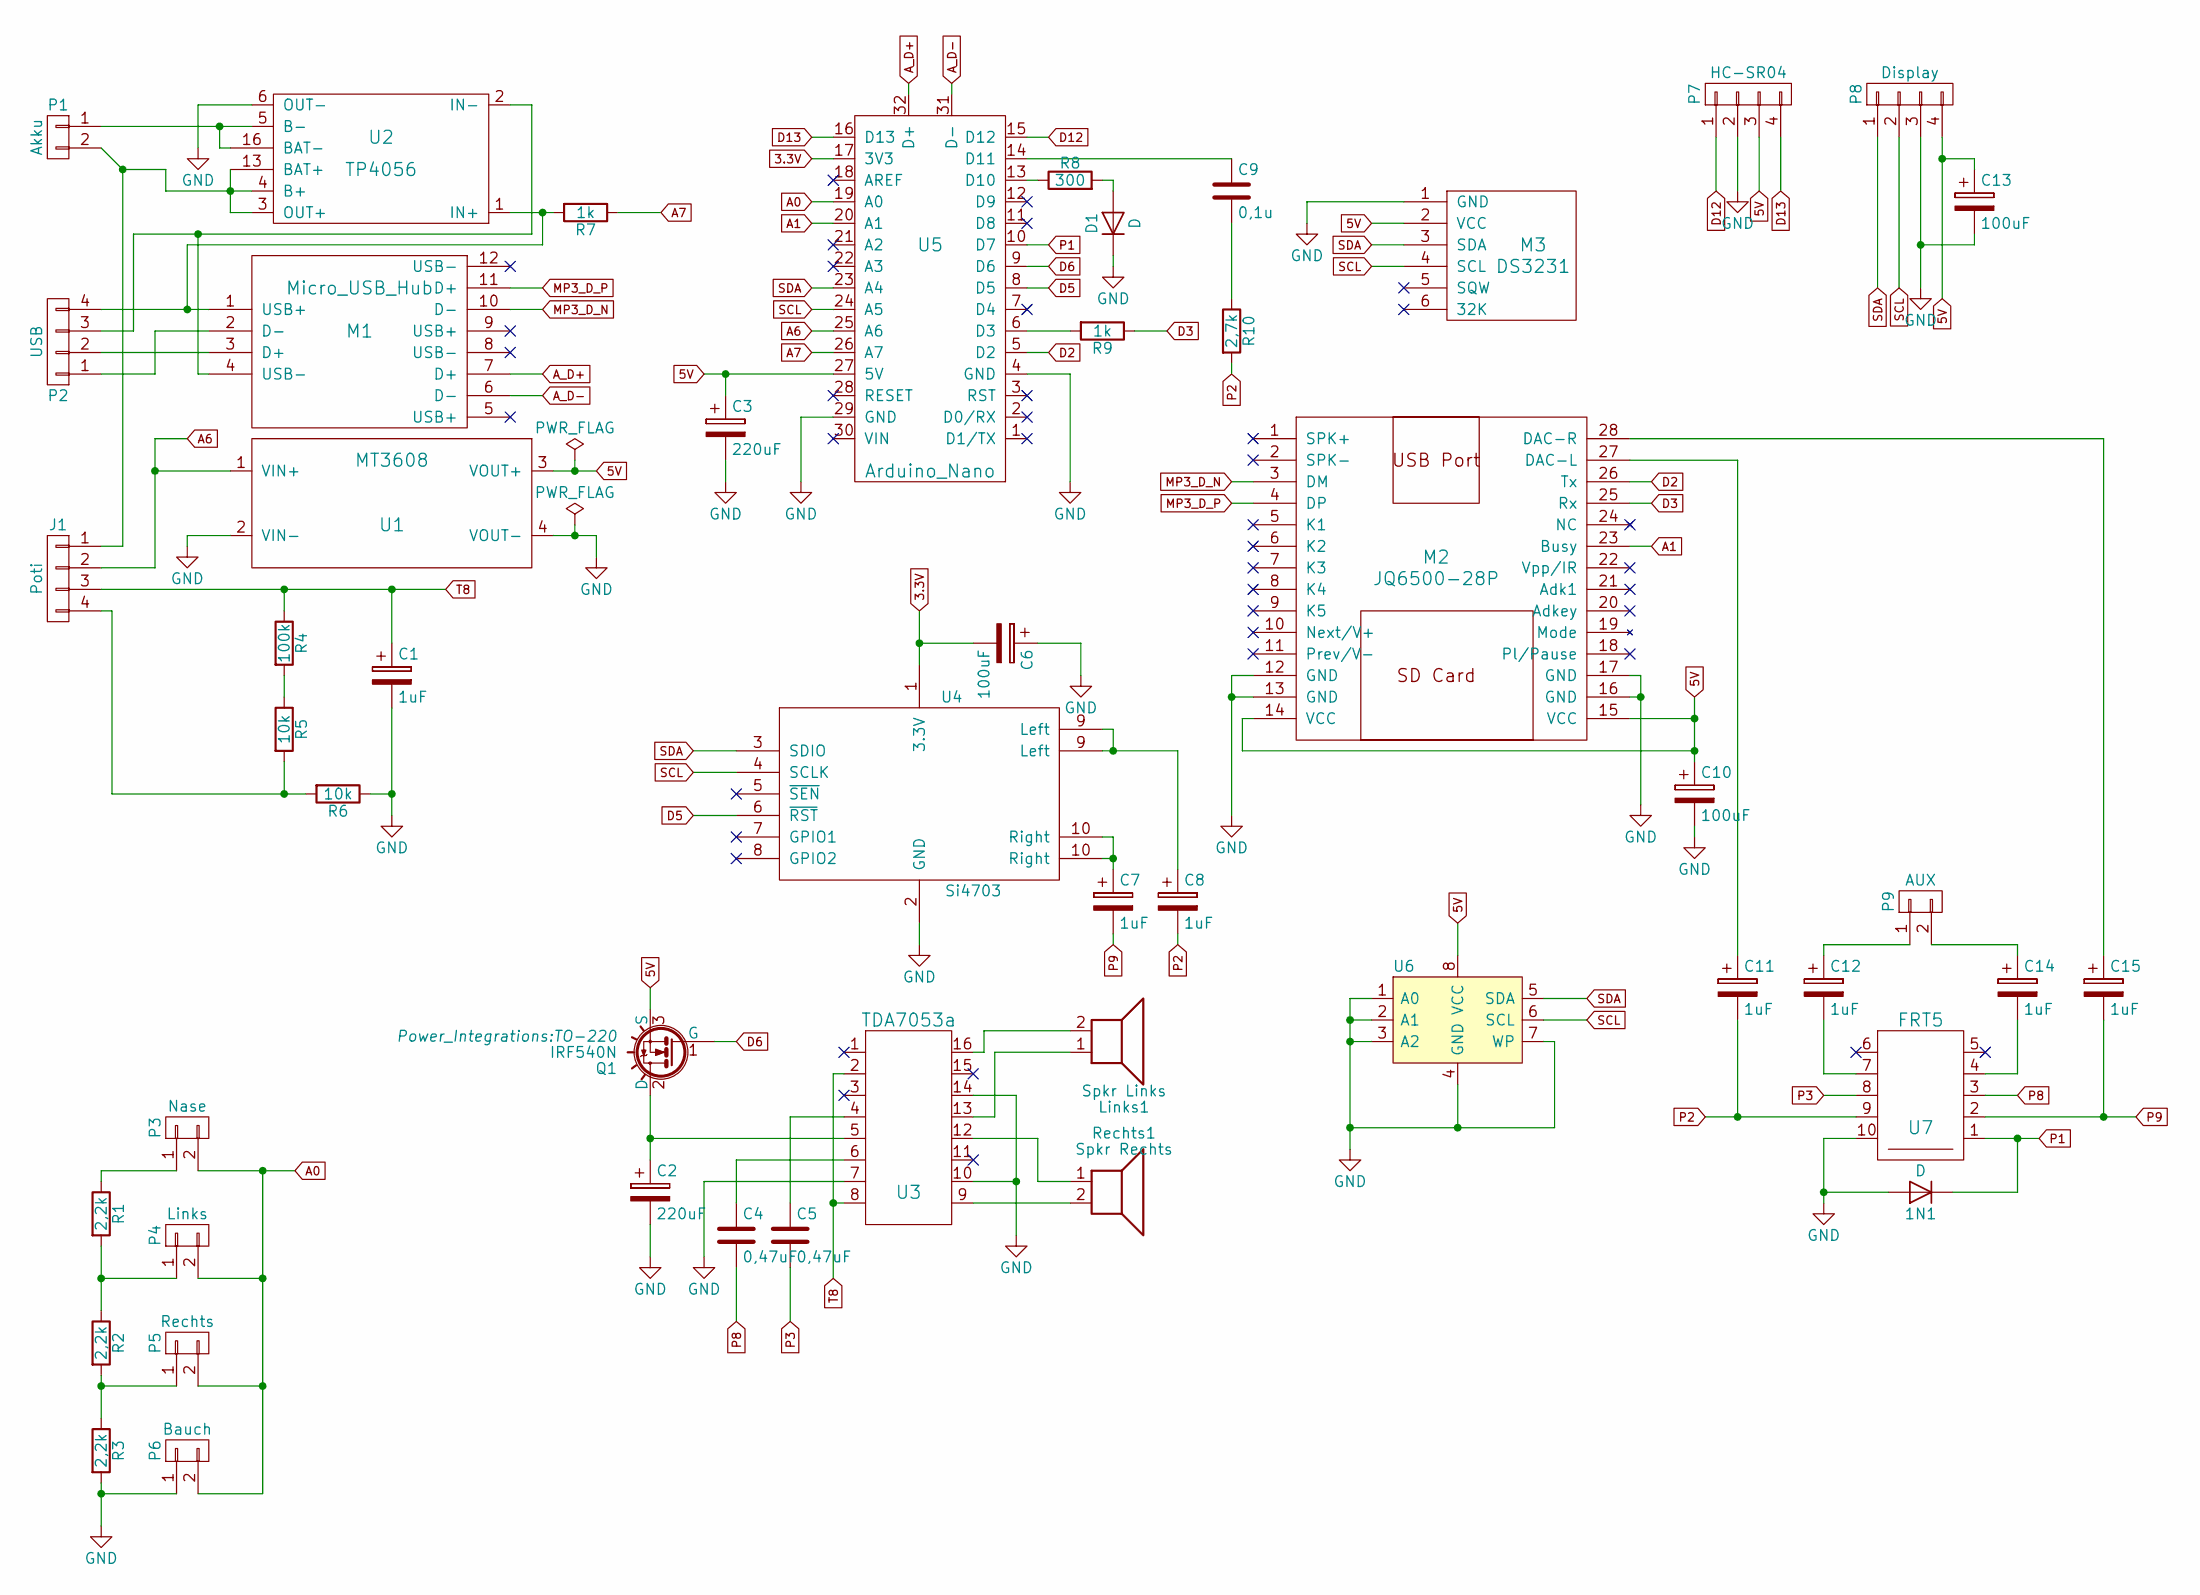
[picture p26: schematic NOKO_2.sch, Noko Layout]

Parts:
1N1: D; D_DO-41_SOD81_P7.62mm_Horizontal
C1, C11: 1uF; CP_Radial_D5.0mm_P2.50mm
C2, C3: 220uF; CP_Radial_D8.0mm_P3.80mm
C4, C5: 0,47uF; C_Disc_D3.4mm_W2.1mm_P2.50mm
C6, C10, C13: 100uF; CP_Radial_D5.0mm_P2.50mm
C7, C8, C12, C14, C15: 1uF; CP_Radial_D5.0mm_P2.00mm
C9: 0,1u; C_Disc_D3.4mm_W2.1mm_P2.50mm
D1: D; JST_XH_B02B-XH-A_02x2.50mm_Straight
J1: Poti; JST_XH_B04B-XH-A_04x2.50mm_Straight
Links1: Spkr Links; JST_XH_B02B-XH-A_02x2.50mm_Straight
M1: Micro_USB_Hub; Micro-USB-Hub
M2: JQ6500-28P
M3: DS3231
P1: Akku; JST_XH_B02B-XH-A_02x2.50mm_Straight
P2: USB; JST_XH_B04B-XH-A_04x2.50mm_Straight
P3: Nase; JST_XH_B02B-XH-A_02x2.50mm_Straight
P4: Links; JST_XH_B02B-XH-A_02x2.50mm_Straight
P5: Rechts; JST_XH_B02B-XH-A_02x2.50mm_Straight
P6: Bauch; JST_XH_B02B-XH-A_02x2.50mm_Straight
P7: HC-SR04; JST_XH_B04B-XH-A_04x2.50mm_Straight
P8: Display; JST_XH_B04B-XH-A_04x2.50mm_Straight
P9: AUX; JST_XH_B02B-XH-A_02x2.50mm_Straight
Q1: IRF540N; TO-220
R1, R2, R3: 2,2k; R_Axial_DIN0207_L6.3mm_D2.5mm_P7.62mm_Horizontal
R4: 100k; R_Axial_DIN0207_L6.3mm_D2.5mm_P7.62mm_Horizontal
R5, R6: 10k; R_Axial_DIN0207_L6.3mm_D2.5mm_P7.62mm_Horizontal
R7, R9: 1k; R_Axial_DIN0207_L6.3mm_D2.5mm_P7.62mm_Horizontal
R8: 300; R_Axial_DIN0207_L6.3mm_D2.5mm_P7.62mm_Horizontal
R10: 2,7k; R_Axial_DIN0207_L6.3mm_D2.5mm_P7.62mm_Horizontal
Rechts1: Spkr Rechts; JST_XH_B02B-XH-A_02x2.50mm_Straight
U1: MT3608
U2: TP4056
U3: TDA7053a
U4: Si4703
U5: Arduino_Nano
U6: 24LC256; DIP-8_W7.62mm
U7: FRT5; Printrelais_ST03

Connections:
3.3V: C6.2, U4.1 (3.3V), U5.17 (3V3)
5V: C3.1, C10.1, C13.1, M2.14 (VCC), M2.15 (VCC), M3.2 (VCC), P7.3, P8.4, Q1.3 (S), U1.3 (VOUT+), U5.27 (5V), U6.8 (VCC)
A0: P3.2, P4.2, P5.2, P6.2, U5.19 (A0)
A1: M2.23 (Busy), U5.20 (A1)
A6: J1.2, U1.1 (VIN+), U5.25 (A6)
A7: R7.1, U5.26 (A7)
A_D+: M1.7 (D+), U5.32 (D+)
A_D-: M1.6 (D-), U5.31 (D-)
D2: M2.26 (Tx), U5.5 (D2)
D3: M2.25 (Rx), R9.1
D5: U4.6 (~RST), U5.8 (D5)
D6: Q1.1 (G), U5.9 (D6)
D12: P7.1, U5.15 (D12)
D13: P7.4, U5.16 (D13)
GND: 1N1.2 (A), C1.2, C2.2, C3.2, C6.1, C10.2, C13.2, D1.1 (K), M2.12 (GND), M2.13 (GND), M2.16 (GND), M2.17 (GND), M3.1 (GND), P6.1, P7.2, P8.3, R3.2, R6.1, U1.2 (VIN-), U1.4 (VOUT-), U2.6 (OUT-), U3.7, U3.10, U3.14, U4.2 (GND), U5.4 (GND), U5.29 (GND), U6.1 (A0), U6.2 (A1), U6.3 (A2), U6.4 (GND), U6.7 (WP), U7.10
MP3_D_N: M1.10 (D-), M2.3 (DM)
MP3_D_P: M1.11 (D+), M2.4 (DP)
unnamed: C2.1, Q1.2 (D), U3.5
unnamed: C4.1, U3.6
unnamed: C5.1, U3.4
unnamed: C7.1, U4.10 (Right)
unnamed: C8.1, U4.9 (Left)
unnamed: C9.1, U5.14 (D11)
unnamed: C9.2, R10.1
unnamed: C11.1, M2.27 (DAC-L)
unnamed: C12.1, P9.1
unnamed: C12.2, U7.7
unnamed: C14.1, P9.2
unnamed: C14.2, U7.4
unnamed: C15.1, M2.28 (DAC-R)
unnamed: D1.2 (A), R8.2
unnamed: J1.1, P1.2, U2.3 (OUT+), U2.4 (B+), U2.13 (BAT+)
unnamed: J1.4, R5.2, R6.2
unnamed: Links1.1, U3.13
unnamed: Links1.2, U3.16
unnamed: M1.1 (USB+), P2.4, R7.2, U2.1 (IN+)
unnamed: M1.2 (D-), P2.1
unnamed: M1.3 (D+), P2.2
unnamed: M1.4 (USB-), P2.3, U2.2 (IN-)
unnamed: P1.1, U2.5 (B-), U2.16 (BAT-)
unnamed: P3.1, R1.1
unnamed: P4.1, R1.2, R2.1
unnamed: P5.1, R2.2, R3.1
unnamed: R4.2, R5.1
unnamed: R8.1, U5.13 (D10)
unnamed: R9.2, U5.6 (D3)
unnamed: Rechts1.1, U3.12
unnamed: Rechts1.2, U3.9
P1: 1N1.1 (K), U5.10 (D7), U7.1
P2: C8.2, C11.2, R10.2, U7.9
P3: C5.2, U7.8
P8: C4.2, U7.3
P9: C7.2, C15.2, U7.2
SCL: M3.4 (SCL), P8.2, U4.4 (SCLK), U5.24 (A5), U6.6 (SCL)
SDA: M3.3 (SDA), P8.1, U4.3 (SDIO), U5.23 (A4), U6.5 (SDA)
T8: C1.1, J1.3, R4.1, U3.2, U3.8

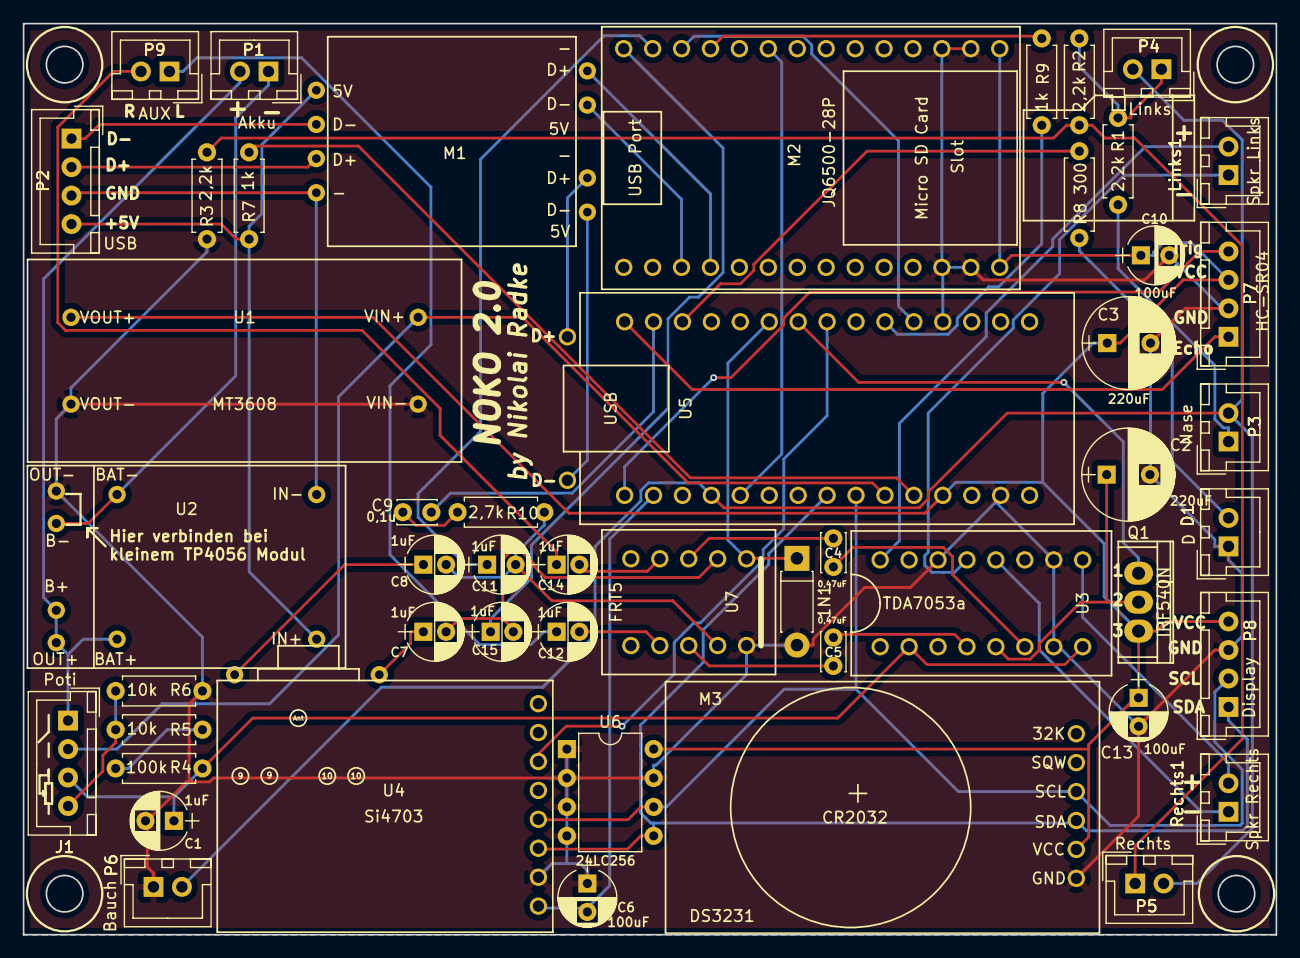
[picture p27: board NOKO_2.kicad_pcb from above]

Board: 2 copper layers, 110.0 x 80.0 mm, 50 parts (0 on the bottom side), 56 nets.

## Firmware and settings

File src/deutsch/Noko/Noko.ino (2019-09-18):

 /* NOKO V1.0 14.04.2019 - Nikolai Radke
 *
 * Sketch for NOKO-Monster - Deutsch
 * NOTE: Does NOT run without the Si4703 Radio Module! Uncommend line 88 if it's not present.
 * The main loop controls the timing events and gets interrupted by the read_button()-funtion.
 * Otherwise NOKO falls asleep with powerdown_delay() for 120ms. This saves a lot of power.
 * 
 * Flash-Usage: 27.032 (1.8.10 | AVR Core 1.8.1 | Linux x86_64, Windows 10 | Compiler options)
 * 
 * Optional:
 * Compiler Options:   -funsafe-math-optimizations -mcall-prologues -maccumulate-args
 *                     -ffunction-sections  -fdata-sections -fmerge-constants
 * These options save flash but are not needed since IDE 1.6.10. Optiboot is still recommended.
 * See https://github.com/NikolaiRadke/NOKO/blob/master/howto_compile/README.md
 * 
 * char()-list: 32=space 37=% 46=. 47=/ 48=0 58=: 68=D 78=N 80=P 82=R 83=S 86=V 87=W 88=X
 *              110=n 120=x | 225=ä 226=ß 239=ö 245=ü (German only)
 *         
 * TODO:
 *         
 * KNOWN BUGS:
 * Due to bad programming the summertime/wintertime will switch at 04:00, not 02:00.
 * 
 * Circuit:
 * 5V               5V    Regulated   
 * LCD GND          GND
 * LCD VCC          5V
 * LCD SDA          A4    (SDA)
 * LCD SCL          A5    (SCL)
 * RTC GND          GND
 * RTC VCC          5V
 * RTC SDA          A4    (SDA)
 * RTC SCL          A5    (SCL)
 * Radio GND        GND
 * Radio VCC        3,3V  (!!!) 
 * Radio SDA        A4    (SDA)
 * Radio SCL        A5    (SCL)
 * Radio RST        D5  
 * JQ6500 GND   13  GND
 * JQ6500 TX    26  D2    (Software-TX)
 * JQ6500 RX    25  D3    (Software-RX), connect with 1kOhm resistor
 * JQ6500 Busy  23  D4/A1 D4: With 4,7kOhm connected to 5V to get a clear HIGH
 * JQ6500 LOUT  27  L Amp
 * JQ6500 ROUT  28  R Amp
 * ULTRA GND        GND
 * ULTRA VCC        5V
 * ULTRA PingPin    D13   (Trigger)
 * ULTRA inPin      D12   (Echo)
 * 24LC256      1   GND   Pin 1-3 must be connected to GND for the correct I2C-address
 * 24LC256      2   GND
 * 24LC256      3   GND
 * 24LC256      4   GND
 * 24LC256      5   A4    (SDA)
 * 24LC256      6   A5    (SCL)
 * 24LC256      7   GND   Pin 7 set to HIGH would enable write protection
 * 24LC256      8   5V
 * Amplifier GND    GND
 * Amplifier VCC    6,5V
 * Amplifier MOSFET D6    (LOW=ON, HIGH=OFF)
 * AUX Relay        D7    
 * SW1 Belly        A0    (Menue) connected via ADC with 3 x 2,2kOhm
 * SW2 Right        A0    (Mute ULTRA | next menue)
 * SW3 Left         A0    (Mute LCD | prev menue)
 * SW4 Nose         A0    (Quit)
 * LED VCC          D10   (PWM)
 * LED GND          GND
 * Speaker VCC      D11   (PWM)
 * Speaker GND      GND
 * Battery VCC      A6    
 * USB VCC          A7    With 1kOhm
 * 
 * Unused           A1.A2,A3,D8,D9,(ICSP), A0 or D4
 * 
 * I2C address list:
 * SI4703           0x10 (Radio)
 * LCD              Will be scanned by default
 * 24LC256          0x50 (EEPROM 32kb)
 * AT24C32          0x57 (EEPROM 4kb on RTC module)
 * DS3231           0x68 (RTC chip on RTC module)
*/

// Softwareversion
#define Firmware "-140419"
#define Version 10  // 1.0
#define Build_by "by Nikolai Radke" // Your Name. Max. 20 chars, appears in "Mein NOKO" menu

// Features on/off. Comment out to disable
#define def_radio             // Using Radio?
#define def_external_eeprom   // Using external EEPROM?
#define def_stories           // Stories on SD card?

// Display selection
#define display_address 0x00    // Autodetect
//#define display_address 0x27  // Blue (PCF8574)
//#define display_address 0x3F  // Yellow (PCF8574A)

// 24LC256 EEPROM addresses
#define phrase_address 4000    // Starting address of the phrases in 24LC256
#define quote_address 10000    // Quotations
#define poem_address  18000    // Poems

// Timezone GMT+1=1
#define TZ 1 

// Developer options
#define pwd_delay     50  // Button debounce
#define reaction_time 70  // Startup time for the amplifier
#define sensor        25  // Ultrasonic: with cover 10, without 25
#define vol_mp3       30  // JQ6500 volume 0-30
#define vol_radio     10  // Si4703 volume 0-15
#define def_sysinfo       // Sysinfo menu. Comment out for additional 640 bytes
//#define busy_analog     // Set if reading the busy signal analog via A1

// Choose your voice set              
//#define voice_set_111   // Old set with 111 files
#define voice_set_226     // New set with 226 files
//#define own_set         // Define your own set below

#ifdef voice_set_111
  #define voice_nose_start    31  // Starts with 31.mp3
  #define voice_sensor_start  61
  #define voice_time_start    81
  #define voice_birthday      111
#endif
#ifdef voice_set_226
  #define voice_nose_start    51
  #define voice_sensor_start  101
  #define voice_time_start    151
  #define voice_birthday      226
#endif
#ifdef own_set
  #define voice_nose_start    0    
  #define voice_sensor_start  0
  #define voice_birthday      0  
  #define voice_birhday       0
#endif  

// Battery calculation
#define min_V         2.85
#define max_V         4.15

// Hardware addresses PINS
#define LED 10            // LED -> PWM
#define Distance_inPin 12 // Ultrasonic
#define Battery 6         // Battery power
#define USB 7             // Is NOKO connected to USB?
#define Speaker 11        // PWM beep 
#define Buttons A0        // ADC buttons
#define Disc0 0x57        // AH24C32 4 kByte EEPROM
#define Disc1 0x50        // 24LC256 32 kByte EEPROM

// Pin operations shortcuts
#define turnOn_pingPin  PORTB |= (1<<5)  // pingPin HIGH
#define turnOff_pingPin PORTB &= ~(1<<5) // pingPin LOW 
#define turnOn_amp      PORTD &= ~(1<<6) // Amplifier LOW=on
#define turnOff_amp     PORTD |= (1<<6)  // Amplifier HIGH=off
#define turnOn_aux      PORTD |= (1<<7)  // AUX HIGH=on
#define turnOff_aux     PORTD &= ~(1<<7) // AUX LOW=off

#ifdef busy_analog                       // Busy=HIGH?
  #define mp3_busy     (analogRead(1)>1) // Analog reading on A1
#else
  #define mp3_busy     PIND & (1<<4)     // Digital reading on D4
#endif

// Libraries
#include <avr/power.h>
#include <avr/wdt.h>
#include <avr/sleep.h>
#include <Wire.h> 
#include <EEPROM.h>
#include "Time.h"
#include "LiquidCrystal_I2C.h"
#include "Si4703.h"
#include "DS3231RTC.h"
#include "TimerFreeTone.h"
#include "JQ6500_Serial.h"

SIGNAL(WDT_vect) // Watchdog to wake NOKO from powerdown_delay()
{
  wdt_disable();
  wdt_reset();
  WDTCSR &= ~_BV(WDIE);
}

uint8_t  selected=0;             // Which menu item selected
uint8_t  xlcd=0;                 // X and
uint8_t  ylcd=0;                 // Y position of LCD cursor
uint8_t  led_val;                // LED brightness 0-9
uint8_t  birth_day,birth_month;  // Birthday gt=day, gm=month
uint8_t  alarm_type;             // Whicht type of alarm
uint8_t  alarm_tone,alarm_mp3;   // Which tone and mp3
uint8_t  alarm_mm,alarm_hh;      // Alarm time hh:mm
uint8_t  alarm_days;             // 8 bit boolean for the weekdays
uint8_t  night_mm,night_hh;      // Nightmode from hh:mm
uint8_t  night_to_mm,night_to_hh;// To hh:mm
uint8_t  distance_val;           // Ultrasonic reaction distance 0-9 
uint8_t  event_val;              // Chance of time event 0-9
uint8_t  equalizer;              // Equalizer mode of MP3 module

boolean  distance_now=false;     // Has there been am ultrasonic event this minute?
boolean  distance_light;         // Swich on LCD light with ultrasonic?
boolean  distance_off=false;     // Ultrasonic off?
boolean  radio_on=false;         // Radio on?
boolean  mp3_pause=false;        // MP3 pause?
boolean  mp3_on=false;           // Is the MP3-Module itself running anything?
boolean  story_on=false;         // Is there a story running?
boolean  file_on=false;          // Is there an own mp3 running?
boolean  birthday=false;         // Is it your birthday today?
boolean  birthday_over=false;    // Was it already celebrated?
boolean  alarm_on;               // Is the Alarm set?
boolean  alarm_mute=false;       // No alarm here?
boolean  alarm_now=false;        // Is the alarm running?
boolean  powersave;              // Powersavemode?
boolean  lcd_dimm=false ;        // Only dim the display?
boolean  lcd_off=false;          // Is powersave active?
boolean  aux_on=false;           // Is AUX active?
boolean  summertime;             // Summertime?
boolean  night_now;              // Is it nighttime? (Time of Nightmode)
boolean  night_over;             // Has the nightmode switched?
boolean  nightmode_on;           // Is nightmode set?
boolean  night_lcd_dimm;         // Will the display mute at nighttime?
boolean  charging;               // Is NOKO's battery charging?

uint16_t file=1;                 // Selected MP3
uint16_t story=1;                // Selected story
uint16_t max_stories;            // Number of stories
uint16_t max_files;              // Number of own MP3s files on SD card
uint16_t offset;                 // EEPROM start position to expand life cyle
uint16_t radio_freq;             // Used frequency * 100
uint16_t radio_station[3];       // 3 radiostationsry

int16_t  thisyear;               // Year is integer type
int16_t  power;                  // Voltage * 100
uint32_t lcd_dimm_time;          // Milliseconds until display mutes
  
const uint8_t event_trigger[10]={0,120,60,45,30,15,10,5,3,1};

// Custom characters. Number set was made by Ishan Karve. Awesome!
// Putting this array into PROGMEM caused strange output. Bizarre.
uint8_t custom_char[19][8]=
{
  {B00111,B01111,B11111,B11111,B11111,B11111,B11111,B11111},
  {B11111,B11111,B11111,B00000,B00000,B00000,B00000,B00000},
  {B11100,B11110,B11111,B11111,B11111,B11111,B11111,B11111},
  {B11111,B11111,B11111,B11111,B11111,B11111,B01111,B00111},
  {B00000,B00000,B00000,B00000,B00000,B11111,B11111,B11111},
  {B11111,B11111,B11111,B11111,B11111,B11111,B11110,B11100},
  {B11111,B11111,B11111,B00000,B00000,B00000,B11111,B11111},
  {B11111,B11111,B11111,B11111,B11111,B11111,B11111,B11111},
  {B01000,B01100,B01110,B01111,B01110,B01100,B01000,B00000}, // Play
  {B00000,B00000,B01110,B01110,B01110,B01110,B00000,B00000}, // Stop
  {B00000,B01010,B01010,B01010,B01010,B01010,B00000,B00000}, // Pause 
  {B00000,B00101,B01010,B10100,B01010,B00101,B00000,B00000}, // Prev
  {B00000,B10100,B01010,B00101,B01010,B10100,B00000,B00000}, // Next
  {B00000,B01010,B01110,B10101,B11111,B01110,B01010,B00000}, // Monster
  {B00000,B00100,B00100,B11111,B01110,B01010,B10001,B00000}, // Star
  {B00001,B00011,B00101,B01001,B01001,B01011,B11011,B11000}, // Note
  {B00000,B01110,B10101,B10111,B10001,B01110,B00000,B00000}, // Clock
  {B00100,B01110,B01110,B01110,B11111,B00000,B00100,B00000}, // Bell
  {B00011,B00110,B01100,B11100,B01100,B00110,B00011,B00000}  // Moon
};

tmElements_t tm;

#ifdef def_radio
  Si4703 Radio(5,A4,A5);  // RST, SDA, SCL
#endif
LiquidCrystal_I2C lcd(display_address,20,4);
JQ6500_Serial mp3(2,3); // Software serial connection

//-------------------------------------------------------------------------
// Using main() and init() instead of setup() and loop() saves flash space

int main(void) {  
uint8_t minute_now=99;
uint8_t hour_now=99;
uint8_t help;
init();
{  
  // Powersave options
  SPCR=0;                // Disable SPI
  ACSR=B10000000;        // Disable analog comparator
  DIDR0=0x3F;            // Disable digital input buffer on all analog ports
  power_spi_disable();       
  power_usart0_disable(); 
  power_timer2_disable();
  
  // Portdefinitions. Direct manipulation is much faster and saves flash
  DDRD=B11111000;   // D7-D0 | 1=OUTPUT
  DDRB=B00101100;   // D13-D8
  DDRC=B00001100;   // A7-A0 | Set unused analog pins to output to prevent catching noise from open ports
  PORTD=B01000000;  // D6 MOSFET HIGH: Turn off amplifier to prevent startup noise
  //PORTB=B00000000; 
  PORTC=B00000001;  // A0: INPUT_PULLUP 
 
  // Read Arduino EEPROM
  offset=EEPROM.read(0)*30;
  equalizer=read_EEPROM(1);
  led_val=read_EEPROM(2);
  alarm_on=read_EEPROM(3);
  alarm_mm=read_EEPROM(4);
  alarm_hh=read_EEPROM(5);
  alarm_type=read_EEPROM(6);
  alarm_tone=read_EEPROM(7);
  distance_val=read_EEPROM(8);
  event_val=read_EEPROM(9);
  powersave=read_EEPROM(10);
  nightmode_on=read_EEPROM(11);
  night_hh=read_EEPROM(12);
  night_mm=read_EEPROM(13);
  night_to_hh=read_EEPROM(14);
  night_to_mm=read_EEPROM(15);
  summertime=read_EEPROM(16);
  radio_freq=(read_EEPROM(17)*10)+(read_EEPROM(18));
  alarm_mp3=read_EEPROM(19);
  for (help=0;help<3;help++)
    radio_station[help]=(read_EEPROM(21+(help*2))*10)+(read_EEPROM(22+(help*2)));
  distance_light=read_EEPROM(27);
  night_lcd_dimm=read_EEPROM(28);
  alarm_days=read_EEPROM(29);

  //  Read AT24C32 
  birth_day=read_disc(Disc0,0);          // Birthday day
  birth_month=read_disc(Disc0,1);        // Birthday month
  #ifdef def_stories
    max_stories=read_disc(Disc0,2);      // Number of stories
  #else
    max_stories=0;
  #endif

   // Start JQ6500
  mp3.begin(9600);
  mp3.pause();
  mp3.reset();
  NewDelay(500);
  mp3.setVolume(vol_mp3);
  mp3.setLoopMode(MP3_LOOP_NONE); // Play only once
  mp3.setEqualizer(equalizer);
  
  // Start Radio
  #ifdef def_radio
    Radio.powerOn();  // Needs to start once!
    Radio.setVolume(vol_radio);
    Radio.powerOff();
  #endif
  
  // Start RTC and switch off useless functions for power saving
  Wire.beginTransmission(0x68); 
  Wire.write("\x0F\xF7");       // 32kHz off         
  Wire.endTransmission();
  powerdown_delay(20);
  Wire.beginTransmission(0x68);
  Wire.write("\x0E\x7F");       // SQW off
  Wire.endTransmission();
  read_RTC();                   // Read RTC
  
  // Start LCD and create custom characters 
  lcd.begin(20,4);    
  init_char();

  //  Check for update and compare with internal version number
  help=EEPROM.read(20);
  if (Version>help) // New version > internal version?
  {
    lcd.clear();
    lcd.print(F(" Update erfolgreich"));
    put_char(3,1,86);
    lcd.print(help/10);
    print_dot();
    lcd.print(help%10);
    lcd.print(F(" auf V"));
    lcd.print(Version/10);
    print_dot();
    lcd.print(Version%10); // lcd.print does not support printf-formatting
    lcd.setCursor(4,3);
    lcd.print(F("Nase dr cken"));
    put_char(11,3,245);
    EEPROM.write(20,Version); // Write new internal version
    wait_1m(true,false);      // Wait for button
    lcd.clear();
  }

  // Starting sound
  sound_on();
  play_tone(600,80,false,80);
  play_tone(880,150,false,150);
  //turnOff_amp;
  
  read_time(); // Read RTC
  night_over=check_night(); // Has nightmode switched before startup?
  
  max_files=mp3.countFiles(MP3_SRC_SDCARD)-(voice_birthday+max_stories); // Number own of files on SD card
  
}
// MAIN LOOP
while(1)
{
  read_time();
  if (((analogRead(USB)>800) && (!charging)) || ((analogRead(USB)<800) && (charging))) // USB connected?
  {
    charging=!charging;
    if ((analogRead(USB)<800) && (lcd_dimm) && (powersave)) powerdown();
    else if ((analogRead(USB)>800) && (lcd_off)) powerup();
    else draw_time();
  } 

// Every minute                                             
  if (minute_now!=tm.Minute)                        
  { 
    if ((night_now) && (night_lcd_dimm) && (!lcd_off))   // Power down at nightmode
    {
      if ((powersave) && (!charging)) powerdown();
      else if (!lcd_dimm)
      {
        lcd.noBacklight();
        lcd_dimm=true;
      }
    }
    distance_now=false;

// Every hour
    if (hour_now!=tm.Hour)                          
    {
      if (!lcd_off) 
      {    
        draw_date();                          // Draw date
        if ((birth_month==tm.Month) && (birth_day==tm.Day))   // Check for birthday
        {
          birthday=true;
          if ((!birthday_over) && (!night_now)) party();
        }
        else 
        {
          birthday_over=false;
          birthday=false;
        }                   
      }
      check_summertime();                     // Check for summertime
    }
    if (!lcd_off) draw_time();                // Draw clock
    if (!night_now)
    {
      if ((power<10) && (!charging))          // Read battery power
      {
        sound_on();
        play_tone(920,80,false,80);           // Power <10% beep
      }
      if ((!(mp3_busy)) && (!mp3_pause) && (!radio_on) && (power>1) && ((newrandom(1,event_trigger[event_val]+1)==event_trigger[event_val])))
        event();                              // Time based event
    }
  }
  if ((!lcd_off) && (!distance_off) && (distance_val>0)) check_ultra(); 
                                              // Ultrasonic event
  if ((lcd_dimm) && (distance_light) && (millis()>lcd_dimm_time+150)) lcd.noBacklight();  
                                              // Switch off display light after ~1s. 150 is a workaround for stupid IDLE mode.
  minute_now=tm.Minute;
  hour_now=tm.Hour;
  selected=read_button(false);                // Read buttons
  switch(selected)
  {
    case 1:                                   // Belly: menue
      if (!lcd_off) menue_Main(); 
      break;
    case 2:                                   // Right: toggle ultrasonic
      if ((!lcd_off) && (!lcd_dimm) && (distance_val>0)) 
      { 
        distance_off=!distance_off;
        draw_time();
      }
      break;
    case 3:                                   // Left: toggle display & power save
      if (lcd_off) powerup();
      else if ((powersave) && (!charging)) powerdown();
      else
      {
        lcd_dimm=!lcd_dimm;
        draw_time();
        if (!lcd_dimm)
        {
          analogWrite(LED,0);
          lcd.backlight();  
        }
        else 
        {
          analogWrite(LED,led_val*28);
          lcd.noBacklight();
        }
        powerdown_delay(pwd_delay);
      }
      break;
    //case 4: break; // Nose unused, only voice as random event
    }
    powerdown_delay(lcd_off? 240:120); // Main loop power save!    
}}

//-------------------------------------------------------------------------------------

uint8_t read_button(boolean silent)  // Read pressed button und debounce | silent = NOKO stays silent
{
  uint16_t button_val;
  read_RTC();      // Read RTC. Powerdown_delay() messes up the internal time!
  if ((!mp3_pause) && (!(mp3_busy)) && (mp3_on)) mp3_on=false;
  if (power<5) silent=true;
  if ((!(mp3_busy)) && (!radio_on) && (!aux_on) && (!alarm_now)) turnOff_amp;
  if (check_alarm()) return 4; // Check alarm
  button_val=(analogRead(Buttons));
  if (button_val>200) return 0;
  else 
  {
    if (button_val>150)         // SW4 nose -> voice 31-60
    {
      powerdown_delay(pwd_delay);
      if (analogRead(Buttons)>150)
      {
       if ((!mp3_busy) && (!silent) && (!mp3_pause))
         if (newrandom(1,5)==4) JQ6500_play(newrandom(voice_nose_start,voice_sensor_start));
       return 4;
      }
    }
    else if (button_val>100)    // SW3 left hand
    { 
      powerdown_delay(pwd_delay);
      if (analogRead(Buttons)>100) return 3;
    }
    else if ((button_val>50))   // SW2 right hand
    {
      powerdown_delay(pwd_delay);
      if (analogRead(Buttons)>50) return 2;
    }
    else                        // SW1 belly -> voice 11-30
    {
      if (analogRead(Buttons)>0)
      {
        if ((!silent) && (!mp3_pause))
          JQ6500_play(newrandom(11,voice_nose_start)); 
        powerdown_delay(pwd_delay);
        return 1;
      }
    }
  }
}

// Constantly used functions. Saves a lot of flash.
void put_char(uint8_t x,uint8_t y,uint8_t c) // Char c at x,y
{
  lcd.setCursor(x,y);
  lcd.print(char(c));
}

void print_space(uint8_t x,uint8_t y,uint8_t val) // anz spaces from x,y
{
  lcd.setCursor(x,y);
  for (uint8_t help=val;val>0;val--) print_onespace();
}

void print_icon(uint8_t c[]) // Icon c at 0,0
{
  lcd.createChar(0,c);
  lcd.clear();
  lcd.print(char(0));
  print_onespace();
}

void init_menue()
{
  lcd.clear();
  lcd.setCursor(2,0);
}

// Plays tone with delay. Delay can be stopped by pressing SW4 when stopd is set TRUE
void play_tone(uint16_t h,uint16_t l,boolean stopd,uint16_t d) 
{
  TimerFreeTone(Speaker,h,l);
  if (!stopd) NewDelay(d-l);
  else if (selected!=4) stop_delay(d-l);
}

// Constantly used strings. Saves a lot of flash space. 
void print_onespace() {lcd.print(char(32));}  // Prints a " ". Saves flash. However.
void print_dot()      {lcd.print(char(46));}  // Prints a "."
void print_zero()     {lcd.print(char(48));}  // Prints a "0" 
void print_uhr()      {lcd.print(F(" Uhr"));} // Prints " Uhr"
 
void print_hoeren() // Prints "[h]ören"
{
  lcd.print(char(239));
  lcd.print(F("ren")); 
}

void init_char() // Read custom chars again
{
  lcd.clear();
  for (uint8_t help=0;help<8;help++)
    lcd.createChar(help,custom_char[help]);
}

void clearnum(uint8_t x,uint8_t y) // Delete a big number at x,y
{
  xlcd=x;
  ylcd=y;
  print_space(xlcd,ylcd,3);
  print_space(xlcd,ylcd+1,3);
}
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

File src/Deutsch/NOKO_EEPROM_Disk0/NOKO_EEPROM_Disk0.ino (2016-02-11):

/*
 * NOKO Settings EEPROM and Disk0 V1.0 12.01.2016 - Nikolai Radke - Deutsch
 * 
 * This sketch writes the presets into Arduino EEPROM and the owner name in email
 * into the AT24C32-EEPROM. If there are stories on the SD card an def_stories is
 * set to 1, additional informations can be written to AT24C32, which is limited 
 * to 4kb. 
 * 
 * To write these information, see README in folder Write_EEPROM
 * 
 * Arduino-EEPROM:
 * The variables are described in the NOKO sketch.
 * stumm            1 = 0
 * led_dimm         2 = 6
 * alarm_an         3 = 0
 * alarmmm          4 = 9
 * alarmhh          5 = 15
 * klang            6 = 0
 * klang_ton        7 = 3
 * ultra_distanz    8 = 5
 * eventsteller     9 = 4
 * powersave        10 = 1
 * nachtmodus       11 = 1
 * nachtahh         12 = 22
 * nachtamm         13 = 0
 * nachtbhh         14 = 9
 * nachtbmm         15 = 0
 * sommer           16 = will be calculated
 * freqhigh         17 = 89
 * freqlow          18 = 9
 * klang_mp3        19 = 2
 * firmware         20 = 10 -> 1.0
 * station1h        21 = 101
 * station1l        22 = 3
 * station2h        23 = 89
 * station2l        24 = 5
 * station3h        25 = 104
 * station3l        26 = 0
 * ultra_licht      27 = 1
 * nachtdimm        28 = 0
 * 
 * AT24C32:
 * gt               0  = Birthday day
 * gm               1  = Birhtday month
 * geschichten      2 = Number of stories; Max 95
 * Byte 3-19        free
 * Byte 20-39       Owner name
 * Byte 40-79       Owner email
 * Byte 80-99       Reserverd for... whatever the future tells me
 * Byte 100-1699    Author and title geschichtenx2x20 Byte blocks
 * Byte 1700-1779   Length mm:ss geschichtenx2 Byte
 * Byte 1800-4096   free
 */

#include <Wire.h>
#include <EEPROM.h>
#include <Time.h>
#include <DS3231RTC.h>

#define Disk0 0x57    // AH24C32
#define def_stories 1 // Stories on SD card?
#define zz 1          // Timezone 1 = MEZ


// Personal informations
//                {"                    "}
const char name[]={"Nikolai Radke       "};

//                 {"                                        "}
const char email[]={"kontakt@            nikolairadke.de     "};

// Birthday: gt=day, gm=month
const byte gt=7; // Ich
const byte gm=12;

// Number of Stories
const byte geschichten=40; // Max 95

// Length of stories - mm:ss
const byte laenge[]={53,6, 45,6, 53,23, 48,40, 48,22, 47,9, 52,44, 43,56, 48,28, 49,38, 46,16, 53,20, 53,1,
50,15, 52,46, 52,29, 53,8, 50,15, 52,20, 35,25, 50,27, 51,33, 51,23, 48,4, 25,20, 42,39, 47,4, 52,14, 49,36,
53,51, 50,3, 49,27, 52,47, 49,53, 31,13, 32,14, 50,38, 51,8, 47,45, 65,12};

unsigned int addr,c;

const char *monthName[12] = {
  "Jan", "Feb", "Mar", "Apr", "Mai", "Jun",
  "Jul", "Aug", "Sep", "Okt", "Nov", "Dez"
};

tmElements_t tm;

void setup() 
{
  bool parse=false;
  bool config=false;

  // Read time from computer
  if (getDate(__DATE__) && getTime(__TIME__)) {
    parse = true;
    RTC.write(tm);
    config = true;
  }
  
  // Read RTC
    Serial.begin(9600);
  while (!Serial);
  delay(200);
  if (parse && config) {
    Serial.print("DS3231: Zeit=");
    Serial.print(__TIME__);
    Serial.print(", Datum=");
    Serial.println(__DATE__);
    if (sommer()) Serial.println("Sommerzeit");
    else Serial.println("Winterzeit");
  } else if (parse) {
    Serial.println("Fehler! RTC nicht gefunden.");
  } else {
    Serial.print("Konnte die Zeit nicht auslesen, Zeit=\"");
    Serial.print(__TIME__);
    Serial.print("\",Datum=\"");
    Serial.print(__DATE__);
    Serial.println("\"");
  }
  // Write EEPROM
  EEPROM.write(1,0);
  EEPROM.write(2,6);
  EEPROM.write(3,0);
  EEPROM.write(4,10);
  EEPROM.write(5,15);
  EEPROM.write(6,0);
  EEPROM.write(7,3);
  EEPROM.write(8,5);
  EEPROM.write(9,4);
  EEPROM.write(10,1);
  EEPROM.write(11,1);
  EEPROM.write(12,22);
  EEPROM.write(13,0);
  EEPROM.write(14,9);
  EEPROM.write(15,0);
  EEPROM.write(16,sommer());
  EEPROM.write(17,99);
  EEPROM.write(18,25);
  EEPROM.write(19,2);
  EEPROM.write(20,10);
  EEPROM.write(21,101);
  EEPROM.write(22,30);
  EEPROM.write(23,89);
  EEPROM.write(24,50);
  EEPROM.write(25,104);
  EEPROM.write(26,0);
  EEPROM.write(27,1);
  EEPROM.write(28,0);
  Serial.println("Grundeinstellungen wurden ins EEPROM geschrieben.");
  
  // Write AT24C32
  Serial.println("AT24C32 beschreiben:");
  Serial.println("NOKO wird personalisiert...");
  Serial.print("Geburtstag: ");
  Serial.print(gt);
  Serial.print(".");
  Serial.print(gm);
  Serial.println(".");
  writeDisk(Disk0,0,gt);
  delay(30);
  writeDisk(Disk0,1,gm);
  delay(30);

  // Write owner name
  Serial.print("Name: ");
  for (addr=0;addr<20;addr++)
  {
    writeDisk(Disk0,addr+20,name[addr]);
    Serial.print(name[addr]);
    delay(50);
  }

  // Write owner email
  Serial.println();
  Serial.print("Email: ");
  delay(100);
  
  for (addr=0;addr<40;addr++)
  {
    writeDisk(Disk0,addr+40,email[addr]);
    Serial.print(email[addr]);
    delay(50);
  }

  //Write number of stories
  writeDisk(Disk0,2,geschichten);
  delay(30);
  
  Serial.println();

  #ifdef def_stories
    Serial.println("Länge der Geschichten...");
    for (addr=0;addr<(geschichten*2);addr++)
    {
     writeDisk(Disk0,addr+(geschichten-1)*80+100,laenge[addr]);
     Serial.print(laenge[addr]);
     Serial.print(" ");
     if ((addr+1)%20==0) Serial.println();
    }
    Serial.println();  
    Serial.println("Autor und Titel - Script starten (zum Beenden Fenster schliessen)...");
    addr=100; // Starting adress
  #endif
}

void loop() 
{
  #ifdef def_stories
    while(Serial.available() == 0);
    c=Serial.read();
    switch(c) // Convert Umlaute
    {
      case 35:c=225;break; // #=ä
      case 36:c=239;break; // $=ö
      case 37:c=245;break; // %=ü
      case 42:c=226;break; // *=ß
    }
    Serial.print(char(c));
    writeDisk(Disk0,addr,c);
    // delay(30);
    addr++;
    if (addr%20==0) Serial.println();
  #else
    Serial.println("Fertig.");
    while(1)
  #endif
}

//----------------------------------------------------------------------

bool getTime(const char *str) // Read time
{
  int Hour, Min, Sec;

  if (sscanf(str, "%d:%d:%d", &Hour, &Min, &Sec) != 3) return false;
  tm.Hour = Hour;
  tm.Minute = Min;
  tm.Second = Sec;
  return true;
}

bool getDate(const char *str) // Read date
{
  char Month[12];
  int Day, Year;
  uint8_t monthIndex;

  if (sscanf(str, "%s %d %d", Month, &Day, &Year) != 3) return false;
  for (monthIndex = 0; monthIndex < 12; monthIndex++) {
    if (strcmp(Month, monthName[monthIndex]) == 0) break;
  }
  if (monthIndex >= 12) return false;
  tm.Day = Day;
  tm.Month = monthIndex + 1;
  tm.Year = CalendarYrToTm(Year);
  return true;
}
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

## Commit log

2016-01-20 Schaltplaene hinzu
    [NOKO.sch, NOKO_Amp.sch, NOKO_USB.sch]
2016-01-20 Richtige Schaltpläne
    [NOKO.sch, NOKO_Amp.sch]
2016-01-23 Update Schaltpläne
    [NOKO.sch, NOKO_Amp.sch, NOKO_USB.sch]
2016-02-11 Corrected writing to Disk0
    [NOKO_EEPROM_Disk0.ino]
2016-02-21 Chanced diode to voltage regulator
2016-03-18 Adjusted radio volume
    [NOKO.sch]
2016-03-18 Updated NOKOs Mainboard schematic
    [NOKO.sch]
2016-03-18 Updated MOSFET
    [NOKO_Amp.sch]
2016-03-18 Update German material list
2016-03-28 Better button tolerance if current drops
2016-03-29 Chanced AUX-relay state on startup
2016-04-06 Stupid Bug: A6 and A7 were switched.
2016-04-07 New schematics!
    [NOKO.sch, NOKO_Amp.sch, NOKO_USB.sch]
2016-04-08 Updated schematics
    [NOKO.sch, NOKO_Amp.sch, NOKO_USB.sch]
2016-04-12 Better schematics
    [NOKO_Amp.sch, NOKO_USB.sch]
2016-04-16 Fixed wrong voice for nose event
    [DS3231RTC.cpp, JQ6500_Serial.cpp, Si4703.cpp]
2016-04-17 Better battery percentage algorithm
2016-04-17 Litte more power saving
2016-04-17 Updated poti connections
    [NOKO_Amp.sch]
2016-04-18 Adjusted battery calculation
2016-04-22 Better button debounce
2016-04-24 Adjusted power percentage calculation. Finally!
2016-04-30 Adjusted ultrasonic sensor
2016-05-06 Reworked power save mode
2016-05-06 Found an error in the settings software
    [NOKO_EEPROM_Disk0.ino]
2016-05-07 Reworked power save modes
    [DS3231RTC.cpp, JQ6500_Serial.cpp, Si4703.cpp]
2016-05-07 Added missing local libraries. Shame...
    [DS3231RTC.cpp, NOKO_EEPROM_Disk0.ino]
2016-05-08 Workaround for Atmels stupid stupid idle mode
    [DS3231RTC.cpp, JQ6500_Serial.cpp, Si4703.cpp]
2016-05-09 Upated power source schematic
    [NOKO_USB.sch]
2016-06-09 Added important comments on LCDs I2C-adress
2016-06-09 Added I2C-scanner tool
2016-07-11 Updated amplifier schematics
    [NOKO_Amp.sch]
2016-09-21 Changed PWM-Port for the taillight
2016-09-22 Changed wrong relay number
2016-10-06 Chanced Micro-USB to Mini-USB. Yes. We need Mini-USB-Cables.
2016-11-10 Fixed wrong relay connection. Old connection worked anyway (strangely...)
2016-11-12 Chanced ST3 002 H5W Relay to FRT8S with Diode
    [NOKO_Amp.sch]
2016-11-13 Fixed stupid typo in relay name
2016-11-13 Fixed stupid type in relay name
    [NOKO_Amp.sch]
2016-11-28 Fixed an ifdef-bug in NOKO_EEPROM_Disk0
    [NOKO_EEPROM_Disk0.ino]
2017-01-05 Oh! Big bug! Switched D2 and D3!
2017-01-05 New schematics. TX and RX on the MP3_module where switched.
2017-01-05 New schematics. TX and RX on the MP3 module where switched.
2017-02-09 Removed wrong bridge in slot S1
2017-03-06 Changed programming language to Arduino
2017-04-12 Slightly improved power saving
2017-04-19 Fixed ADC bug after power mode
    [DS3231RTC.cpp, JQ6500_Serial.cpp, Si4703.cpp]
2017-05-21 RDS rework. Works MUCH better now!
    [DS3231RTC.cpp, JQ6500_Serial.cpp, Si4703.cpp]
2017-05-31 Added some error handling
    [DS3231RTC.cpp, I2C_Scanner.ino, NOKO_Disk1.ino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]
2017-06-09 Fixed a bug: Display won't turn off
    [DS3231RTC.cpp, JQ6500_Serial.cpp, Si4703.cpp]
2017-06-27 New eagle layout for a better NOKO
    [NokoLayout-B.Cu.gbr, NokoLayout-B.Mask.gbr, NokoLayout-B.Paste.gbr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]
2017-07-04 New PCB schematics
    [NokoLayout-B.Cu.gbr, NokoLayout-B.Mask.gbr, NokoLayout-B.Paste.gbr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]
2017-07-13 New poti schematic
2017-07-24 Added layout drill file
    [NokoLayoutV1.1.drl]
2017-08-24 Firmware 280717 - fixed a bug that limited the number of stories to 42 instead of 95
    [NOKO_EEPROM_Disk0.ino]
2017-10-31 New power schematics picture
2017-10-31 New main board downside schematic
2017-11-11 New schematics for the upper board. Two cuts were missing.
2017-11-30 Reworked story adressing. Working now.
    [DS3231RTC.cpp, NOKO_EEPROM_Disk0.ino]
2017-12-18 Added pcb gerber-files
    [NOKO_2-B.Cu.gbr, NOKO_2-B.Mask.gbr, NOKO_2-B.SilkS.gbr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]
2017-12-25 PCB: Bestückungsliste hinzugefügt
    [NOKO_2.csv]
2018-01-15 Added new pcb files
    [NokoLayoutV1.1-B.Cu.gbr, NokoLayoutV1.1-B.Mask.gbr, NokoLayoutV1.1-B.Paste.gbr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]
2018-01-15 Clean up
    [NOKO_2-B.Cu.gbr, NOKO_2-B.Mask.gbr, NOKO_2-B.SilkS.gbr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]
2018-01-24 added kicad folder with rotated arduino
    [NOKO_2-B.Cu.gbr, NOKO_2-B.Mask.gbr, NOKO_2-B.SilkS.gbr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]
2018-01-24 created Gerber files
    [NOKO_2-B.Cu.gbr, NOKO_2-B.Mask.gbr, NOKO_2-B.SilkS.gbr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]
2018-01-26 Changed module descriptors to F-Silk layer
    [NOKO_2.kicad_pcb]
2018-01-27 last changes
    [NOKO_2.kicad_pcb]
2018-01-27 Gerber files updated
    [NOKO_2-B.Cu.gbr, NOKO_2-B.Mask.gbr, NOKO_2-B.SilkS.gbr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]
2018-01-28 added D+ / D- to Arduino USB pads
    [NOKO_2.kicad_pcb]
2018-01-29 need to change circuit again, don't use at the moment
    [NOKO_2.2.dsn, NOKO_2.dsn, NOKO_2.kicad_pcb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]
2018-01-29 Footprint für Arduino optimiert, so dass er besser passt
    [NOKO_2.dsn, NOKO_2.kicad_pcb]
2018-01-30 beautified mounting holes, change folder structure to make more sense
    [NOKO_2.dsn, NOKO_2.kicad_pcb, NOKO_2.sch]
2018-01-30 created PDF folder
    [PCB_Preise.ods]
2018-01-30 updated circuit diagram in PDF folder
2018-01-30 deleted old circuit diagram
2018-02-01 changed layout of USB hub, fixed mix up of D+ and D- line to MP3 module
    [NOKO_2.dsn, NOKO_2.kicad_pcb, NOKO_2.sch]
2018-02-06 Added PCB V2.0 Firmware and renamed some mp3s to correct format
    [DS3231RTC.cpp, JQ6500_Serial.cpp, Si4703.cpp]
2018-02-08 Reworked some tone code
    [DS3231RTC.cpp, JQ6500_Serial.cpp, Si4703.cpp]
2018-02-11 Schutzdiode am Relais umgedreht
    [NOKO_2.dsn, NOKO_2.kicad_pcb, NOKO_2.sch]
2018-02-24 Aufschrift auf 2.0 geändert
    [NOKO_2-B.Cu.gbr, NOKO_2-B.Mask.gbr, NOKO_2-B.SilkS.gbr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]
2018-02-25 Removed obsolete folder pcb
2018-03-16 VIN+ und VOUT+ des StepUp Moduls richtig / gedreht
    [NOKO_2-B.Cu.gbr, NOKO_2-B.Mask.gbr, NOKO_2-B.SilkS.gbr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]
2018-03-17 Last, last, last changes
    [NOKO_2.kicad_pcb, NOKO_2.sch]
2018-03-17 Jetzt auch mit GERBER Dateien inklusive ZIP Datei Update!
    [NOKO_2-B.Cu.gbr, NOKO_2-B.Mask.gbr, NOKO_2-B.SilkS.gbr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]
2018-04-30 Slightly optimized random generator
    [Akku_Deckel.stl, Gehaeuse_eckiger_LED_Schalter.stl, Gehaeuse_runde_LED_Schalter.stl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]
2018-05-23 New backpart
    [Akku_deckel.stl, Gehaeuse_eckiger_LED_Schalter.stl, Gehaeuse_runde_LED_Schalter.stl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]
2018-08-26 New IDE 1.8.6 used
    [Akku_Deckel.stl, Akku_deckel.stl]
2018-10-31 Tested with AVR Core 1.6.23
    [Akku_deckel.stl, Gehaeuse_eckiger_LED_Schalter.stl, Gehaeuse_runde_LED_Schalter.stl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]
2019-04-16 Firmware 140419. Fixed old and rare night mode bug
    [Akku_Deckel.stl]
2020-06-14 Reworking repository
    [Akku_deckel.stl]
2020-07-11 Repository rework
    [Akku_deckel.stl, Gehaeuse_eckiger_LED_Schalter.stl, Gehaeuse_runde_LED_Schalter.stl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]
